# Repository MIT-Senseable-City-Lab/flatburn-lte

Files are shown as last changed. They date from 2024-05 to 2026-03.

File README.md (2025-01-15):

# FLATBURN: the open source city scanner

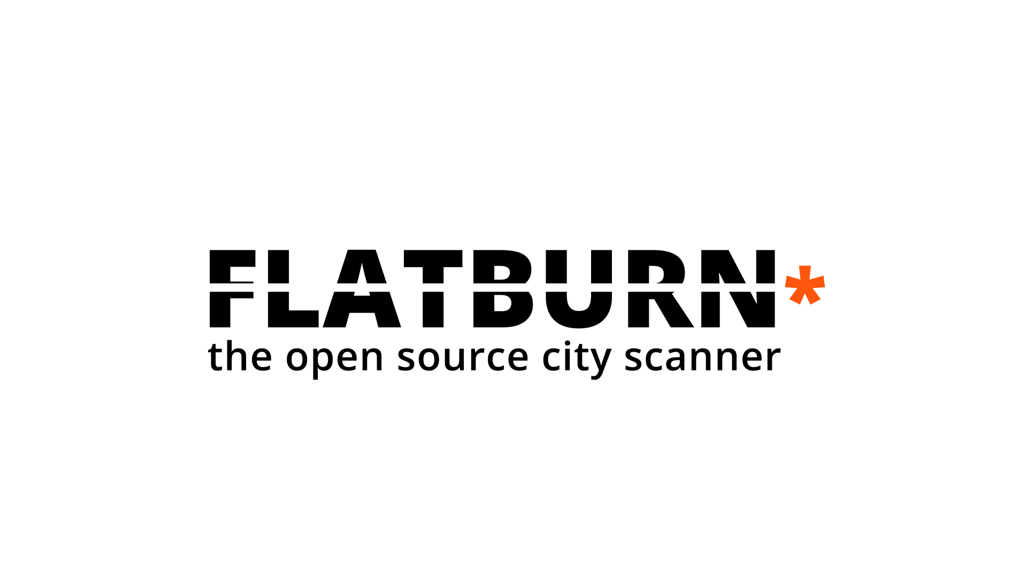
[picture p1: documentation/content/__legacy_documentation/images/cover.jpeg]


Part of the [City Scanner](https://senseable.mit.edu/cityscanner/) project at [MIT Senseable City Lab](https://senseable.mit.edu), Flatburn is an open-source, solar-powered, modular sensing platform that can be easily deployed on road vehicles to collect various environmental data. 

This repository contains all information to build your own Flatburn, explore datasets collected using Flatburn and other City Scanner deployments worldwide and learn how to perform environmental analysis and use the data to contribute to the development of healtier cities.

You can find all information on the [documentation](https://mit-senseable-city-lab.github.io/flatburn-lte/).

[Project website](https://senseable.mit.edu/flatburn).

All materials are released under [MIT license](LICENSE).

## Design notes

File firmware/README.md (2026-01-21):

# Flatburn-firmware

## Environment
- Code developed using [Particle.io plugin for MS Code](https://www.particle.io/workbench/)
- Devices can be flashed both via cable or cloud flash (data costs)
- Compatible with [Particle deviceOS@6.3.4](https://docs.particle.io/reference/device-os/firmware)
- Written in C++ and [Particle deviceOS APIs](https://docs.particle.io/reference/device-os/firmware/)

## Dev Environment Setup

1. Clone this repository
2. Open Particle Workbench
3. Run the `Particle: Import Project` command, follow the prompts, and wait for the project to load
4. Run the `Particle: Configure Workspace for Device` command and select a compatible Device OS version and the `bsom` platform when prompted ([docs](https://docs.particle.io/tutorials/developer-tools/workbench/#cloud-build-and-flash))
5. Connect your device
6. Compile & Flash!

## Quick overview of classes and files
- *cityscanner_config.h* main config file, needs to be updated before flashing
- *main.h* the program startpoint, should not be modified
- *cityscanner class* handles operation modes (more below)
- *CitySense class* manages data acquisition for environmental sensors (air quality, etc)
- *CityVitals class* acquires telemetry data (battery status, solar energy production, etc)
- *CityStore class* manages storing data on the SD card, dumping data over USB
- *MotionService class* used to send the device to sleep when the vehicle is not moving
- *LocationService class* provides GPS data to other classes (e.g. CityStore)

## Operation modes
- *IDLE* sensors off, provides only telemetry data
- *REALTIME* logs data onto the SD card
- *LOGGING* buffer data onto the SD card and send multiple records upon request (via USB)
- *PWRSAVE* like LOGGING but in low power mode

#### Payload

deviceID, timestamp, latitude, longitude, PM1.0, PM 2.5, PM4, PM10, numPM0.5, numPM1, numPM2.5, numPM4, numPM10, PM size, temperature, humidity, gas_op1_w, gas_op1_r, gas_op2_w, gas_op2_r, noise

### Vitals
deviceID, time, latitude, longitude, SOC_batt, temp_batt, voltage_batt, voltage_particle, current_batt, isCharging, isCharginS, temp_int, hum_int, voltage_solar, current_solar, cell_strenght

# Command line interface
A Python script provides a command line interface (CLI) for retrieving data over USB. To use it, follow the step-by-step instructions in the [data retrieval guide](https://mit-senseable-city-lab.github.io/flatburn-lte/deploy/data)

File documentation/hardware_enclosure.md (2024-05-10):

Files for 3D printing, laser-cutting and the full CAD assembly.

A BoM (bill of materials) listing all the required parts and components to build a Flatburn enclosure is available [here](https://docs.google.com/spreadsheets/d/1qiVyINNuo0XEu6MasEJE_p4onlJh241j/edit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).

**Process pictures showing the main assembly steps:**



Our prototypes were printed on a Flashforge Guider ii, but the files can be printed on most standard desktop 3D printers (e.g. Prusa i3, Ender 3, Ultimaker etc). 

We suggest the following settings:

* Infill type: Triangular or Esagonal 
* Infill Percentage: at leat 50% 
* Layer height: this depend on the printer nozzle, I would go with the pre-defined setting.

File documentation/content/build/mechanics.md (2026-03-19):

---
sidebar_position: 5
---

import Top from '@site/static/files/assembly/DSC09227.jpg'
import Middle from '@site/static/files/printed/middle.png'
import Bottom from '@site/static/files/assembly/DSC09240.jpg'
import BatteryCover from '@site/static/files/printed/battery_cover.png'
import SwitchTop from '@site/static/files/printed/switch_top.png'

# 🔩 Mechanics (files)

###

### Material and Suggested Settings

The easiest material to print with is _PLA_, but _ASA_ is recommended for prolonged outdoor use with high exposure to weather.

It is important to choose a **light material** (i.e. white) to avoid overheating when exposed to sun, which might interfere with measurements and overall electronics' life-cycle.

Since the device might also be exposed to moisture, vibration and stress – during trips and mounting/unmounting – it is recommended to print with settings that provide sturdyness and plenty layer and walls sealing:

- **_layer height_ – 0.28mm**
- **_top layers_ – 5**
- **_bottom layers_ – 5**
- **_walls_ – 5**
- **_infill_ – 15%**

These settings were used for time estimations below, with a total time of approximately **15 hours**.

### Parts List

:::tip
The 3d files below are provided with optimal orientation for printing, which is different from their respective reference images.
:::
| ID | name | support | weight | ~time | download |
| :--- | :--- | :-----: | -----: | :---: | :---: |
| MP_01 | **top** | N |  350 g | 07:30 | [link](https://github.com/MIT-Senseable-City-Lab/flatburn-lte/blob/main/hardware/enclosure/stl/MP-01%20top.stl) |
| MP_02 | **middle** | Y |  150 g | 03:30 | [link](https://github.com/MIT-Senseable-City-Lab/flatburn-lte/blob/main/hardware/enclosure/stl/MP-02%20middle.stl) |
| MP_03 | **bottom** | N |  150 g | 03:30 | [link](https://github.com/MIT-Senseable-City-Lab/flatburn-lte/blob/main/hardware/enclosure/stl/MP-03%20bottom.stl) |
| MP_04 | **switch_top** | N | 5 g | 00:10 | [link](https://github.com/MIT-Senseable-City-Lab/flatburn-lte/blob/main/hardware/enclosure/stl/MP-04%20switch_top.stl) |
| MP_05_02 | **switch_bottom** | N | 5 g | 00:10 | [link](https://github.com/MIT-Senseable-City-Lab/flatburn-lte/blob/main/hardware/enclosure/stl/switch%20radial%20-%20R10307RN02Q/MP-05%20switch_bottom.stl) |
| MP_06 | **battery_cover** | Y | 15 g | 00:30 | [link](https://github.com/MIT-Senseable-City-Lab/flatburn-lte/blob/main/hardware/enclosure/stl/MP-06%20battery_cover.stl) |

The sources are available [here](https://github.com/MIT-Senseable-City-Lab/flatburn-lte/tree/main/hardware/enclosure/step) in *.STEP* format.

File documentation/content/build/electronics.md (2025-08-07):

---
sidebar_position: 4
---

# ⚡ Electronics (files)

### Main and Sensing Board

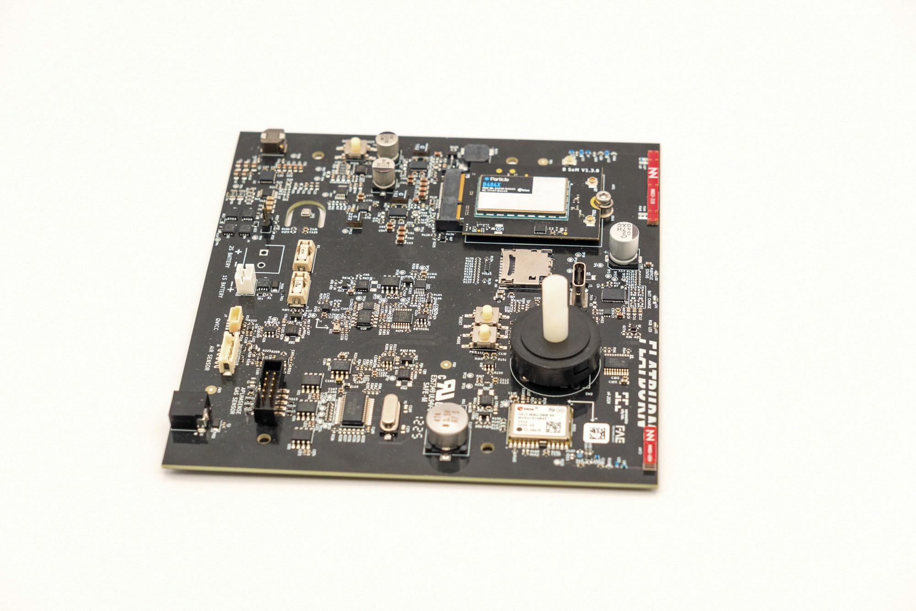
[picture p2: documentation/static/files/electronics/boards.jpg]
Main and Sensing Board


<!-- ### Harnesses

![Harnesses](@site/static/files/electronics/harnesses.jpg) --> 

### Files

- [schematics](https://github.com/MIT-Senseable-City-Lab/flatburn-lte/blob/main/hardware/electronics/Doc/Flatburn_V5_schematic.pdf) (2025-07-29)

- [KiCad files](https://github.com/MIT-Senseable-City-Lab/flatburn-lte/tree/main/hardware/electronics) with embedded component libraries

- [gerbers and centroid files](https://github.com/MIT-Senseable-City-Lab/flatburn-lte/tree/main/hardware/Production/Gerber%20and%20drill)

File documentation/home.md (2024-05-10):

# FLATBURN: the open source city scanner

[Project website](https://senseable.mit.edu/flatburn).

### Flatburn Overview
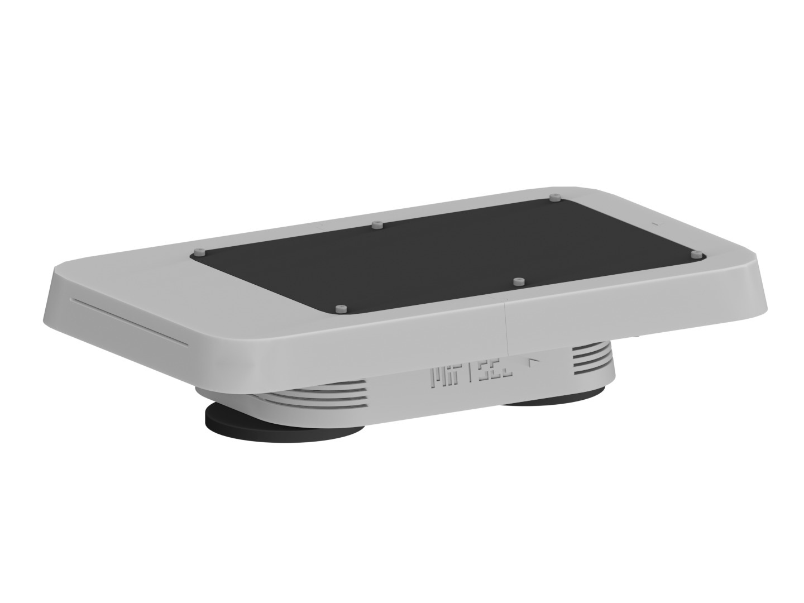
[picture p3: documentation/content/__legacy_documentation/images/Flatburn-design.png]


Part of the [City Scanner](https://senseable.mit.edu/cityscanner/) project at [MIT Senseable City Lab](https://senseable.mit.edu), Flatburn is an open-source, solar-powered, modular sensing platform that can be easily deployed on road vehicles to collect various environmental data. 

This repository contains all information to [build](https://github.com/MIT-Senseable-City-Lab/OSCS/tree/main/Build) your own Flatburn, [explore](https://github.com/MIT-Senseable-City-Lab/OSCS/tree/main/Explore) datasets collected using Flatburn and other City Scanner deployments worldwide and [learn](https://github.com/MIT-Senseable-City-Lab/OSCS/tree/main/Learn) how to perform environmental analysis and use the data to contribute to the development of healtier cities.

## Build
 - [/hardware](Build/Hardware)  
    - [fabrication files](Build/Hardware/Hardware%20enclosure) for Flatburn mechanical parts, including files for [3D printing](Build/Hardware/Hardware%20enclosure/To%20Print), [laser cutting](Build/Hardware/Hardware%20enclosure/To%20lasercut), and a [CAD model](Build/Hardware/Hardware%20enclosure/Flatburn_assembly.step) of the full assembly. A [bill of materials](https://docs.google.com/spreadsheets/d/1qiVyINNuo0XEu6MasEJE_p4onlJh241j/edit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) listing all the required mechanical components is also included.
    - [hardware schematics](Build/Hardware/Hardware%20schematics) contains `.brb` files for the main-board and the sensor-board which can be viewed using the [Cadence](https://www.cadence.com/en_US/home/tools/pcb-design-and-analysis/allegro-downloads-start.html) free viewer, schematics of the PCB in `.pdf` format, and a [bill of materials](https://docs.google.com/spreadsheets/d/1-UVIJEneydIf8kLRng4QxvzjM4k2ZoDa/edit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) for the electronics components.
 - [/firmware](Build/Firmware): The Flatburn main firmware code base, developed using [Particle.io](https://www.particle.io/workbench/) workbench.
 - [/fabrication handbook](Build/Handbook): The assembly guide with detailed instructions on how to build flatburn.

## Explore
- [/datasets](Explore/Datasets): `.csv` calibrated air quality datasets collected during City Scanner deployments worldwide. 
- [/calibration handbook](Explore/Calibration%20Handbook): a guide for validation and calibration of the data collected by Flatburn.

## Learn
- [/coding exercise](Learn/Coding%20Exercise): [jupyter](https://jupyter.org/) notebooks for a Python coding activity to introduce non-experts to air quality and environmental sensing and analysis methods. The activity includes exploring time series analysis, geospatial analysis, and pollution hotspot analysis. The conding activity can be used with the [datasets](Explore/Datasets) captured by previous City Scanner deployment as well as data captured by Flatburn.
- [/facilitator handbook](Learn/Facilitator%20Handbook): a facilitator guide and educational slides to implement the coding exercise as part of workshops or classroom activities.

All materials are released under [MIT license](LICENSE).

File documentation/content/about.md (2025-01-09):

---
sidebar_position: 1
slug: /
---

# Flatburn

_We empower communities around the world to monitor their environment._

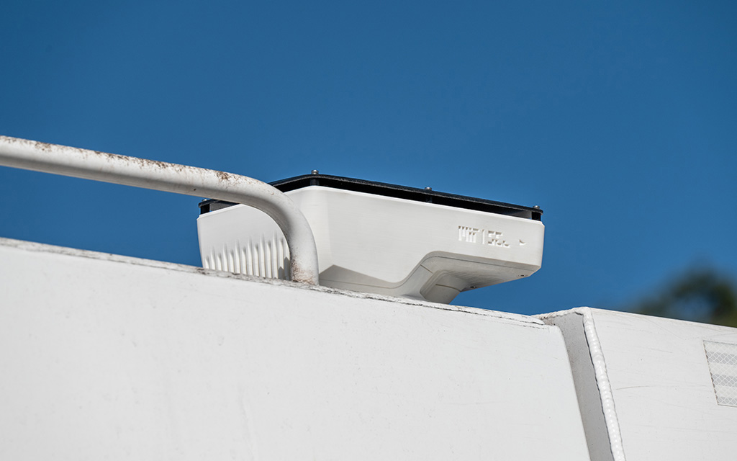
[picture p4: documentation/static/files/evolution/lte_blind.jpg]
Flatburn


Part of the City Scanner project, Flatburn is an open-source, 3D-printed environmental sensor.

Its encompasses houses heat, noise and air quality sensors. Powered using a solar panel, it can be mounted on vehicles using magnetic pads.

Build your own Flatburn and help your community monitor its environment.

<!-- vision: how the project is connected to SCL's vision

approach: drive-by low-cost sensing, high spatio-temporal resolution -->

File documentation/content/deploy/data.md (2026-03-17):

---
sidebar_position: 4
---

# 📊 Data Retrieval via USB Cable

**Follow these steps to retrieve data from the Flatburn device using the web-based downloader tool.**

The Flatburn SD Downloader is a browser-based tool that connects to your device over USB. It works in **Google Chrome** or **Microsoft Edge** (requires Web Serial API support).

The HTML tool is available [here](https://github.com/MIT-Senseable-City-Lab/flatburn-lte/blob/main/documentation/content/explore/flatburn_downloader.html). Download it and open it in Chrome or Edge.

## Step 1: Connect Flatburn to Your Computer

1. Turn on your Flatburn device.
2. Use a USB cable to connect the device to your computer.
3. Open `flatburn_downloader.html` in **Google Chrome** or **Microsoft Edge**.

## Step 2: Connect to the Serial Port

1. Click the **Connect** button.
2. A browser dialog will show available serial ports.
3. Select the Flatburn port; it will be labeled **"B-SoM CDC Mode"**.
4. The status indicator will turn green once connected, and the file list will load automatically.

**Note** After connecting, the tool waits about 1 minute for the device to finish initializing before loading the file list. This is normal, just wait for the file list to appear.

## Step 3: Download, Parse & Merge

The tool will display all available files on the SD card (e.g., files in `/queue/` and `active.csv`).

1. Review the file list.
2. Click **"Download All, Parse & Merge"**.
3. The tool will:
   - Download all files from the SD card
   - Parse each CSV (filter columns, clean data)
   - Convert epoch timestamps to human-readable format (e.g., `2025-03-15 22:37:17`)
   - Merge everything into a single dataset

A progress bar will show the download status, and stats badges will display the total files processed and rows merged.

## Step 4: Save the Merged CSV

1. Click **"Save CSV File"** to download the merged data to your computer.
2. The file is automatically named with a timestamp: `merged_20250315_223717.csv`

The output CSV contains the following columns:

| Column | Description |
|---|---|
| `timestamp` | Date and time of the reading (human-readable) |
| `latitude` | GPS latitude |
| `longitude` | GPS longitude |
| `PM1_0` | Particulate matter 1.0 µm |
| `PM2_5` | Particulate matter 2.5 µm |
| `PM4` | Particulate matter 4.0 µm |
| `PM10` | Particulate matter 10 µm |
| `temperature` | Temperature reading |
| `humidity` | Humidity reading |
| `gas_op1_w` | Gas sensor OP1 working electrode |
| `gas_op1_r` | Gas sensor OP1 reference electrode |
| `gas_op2_w` | Gas sensor OP2 working electrode |
| `gas_op2_r` | Gas sensor OP2 reference electrode |
| `noise` | Noise level reading |

## Step 5: Clean Up the SD Card (Optional)

After saving your merged CSV, you can delete all files from the SD card to free up space:

1. Click **"Delete All Files from SD"**.
2. A confirmation dialog will list all files that will be deleted.
3. Click **OK** to confirm, or **Cancel** to keep the files.

The device will automatically create a fresh `active.csv` file after deletion, so it is ready to continue collecting data.

## Step 6: You're Done!

You now have a single, clean CSV file containing all your environmental and telemetry data with human-readable timestamps. You can use this file for analysis, upload to cloud storage, or integrate into your research workflow.

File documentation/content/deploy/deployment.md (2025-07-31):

---
sidebar_position: 3
---

# 🚚 Deployment
# Flatburn Solar Feasibility & Runtime Estimation

This file estimates whether Flatburn will run continuously on solar power in Brazil, using all the  hardware and sensor configurations.

---

## 1. Instructions

Get your average daily sun hours for your city/month using:
   - [Global Solar Atlas](https://globalsolaratlas.info/)
   - [PVWatts Calculator](https://pvwatts.nrel.gov/)
   - Example: **Rio de Janeiro** in July ≈ 5.5 h/day

---

## 2. Flatburn Power Consumption Estimate

- **Total current:** 211 mA  
- **Total power:** 0.85 W
- **Device daily consumption:** 0.85 W × 24 h = **20.4 Wh/day**

---

## 3. Solar Panel and Battery Specs

| Parameter | Value | Units | Notes |
|---|---|---|---|
| Solar panel power | 5.5 | W | |
| Solar panel voltage | 6 | V | |
| Average daily sun hours  | 5.5 | hours/day  | Brazil average (Rio, July) |
| Solar energy per day | 5.5 × 5.5 = 30.25  | Wh/day | Panel power × sun hours |
| Battery capacity | 10050 × 3.7 / 1000 = 37.19 | Wh | 10050 mAh, 3.7 V Li-Ion |
| Days battery lasts w/o sun | 37.19 / 20.4 = 1.8 | days | Battery Wh / daily use |

---

## 4. Results

- **Solar panel provides:** ~30 Wh/day
- **Flatburn requires:** ~20.4 Wh/day
- **Battery stores:** ~37 Wh

- Daily solar energy is enough for continuous operation with some surplus for battery charging.
- Battery can run Flatburn for **1.8 days** without sun (cloudy/rainy buffer).

---

## 5. Tips

- For worst-case (cloudy, winter), use the lowest sun hours for your city/month.

---

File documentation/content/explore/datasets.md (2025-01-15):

---
sidebar_position: 6
---

# 🗂️ Datasets (files)

[This folder](https://github.com/MIT-Senseable-City-Lab/flatburn-lte/tree/main/documentation/content/_files/datasets) contains open City Scanner data sets collected in four deployments in three cities. Raw sensor readings were collected and calibrated following standardized air sensor performance evaluation guidelines recommended by the U.S. EPA. The general method is presented in the following diagram and details can be found in the open source [calibration page](../deploy/calibration.md).

Detailed information about the deployments and data files is included in he following table. In total, there are eight data files. Given that the second pilot in NYC contains a huge amount of data, its full dataset is divided into five sections. A [data descriptor](https://github.com/MIT-Senseable-City-Lab/OSCS/blob/main/Explore/Datasets/OSCS_OpenDataSupplement.pdf) is also included.

_Table 1. Deployments and open data sets_

| Country | City | Sensing target pollutants | Sensing fleet | Duration |
| :--- | :--- | :--- | :--- | :--- |
| US | New York City | Particulate matter, particle size distribution, NO2 | Five municipal vehicles | Jan. 2020 - Feb. 2020 |
| US | New York City | Particulate matter, particle size distribution, NO2 | Five municipal vehicles | Sep. 2021 - Dec. 2021 |
| US | Boston | Particulate matter, particle size distribution, NO2 | One mobile air laboratory | Feb. 2022 - Apr. 2022 |
| Lebanon | Beirut | Particulate matter, particle size distribution | Two taxis | Feb. 2022 - Jun. 2022 |

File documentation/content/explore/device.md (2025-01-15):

---
sidebar_position: 2
---

# 🧭 Device

The Flatburn device is based on almost a decade of experience in drive-by sensing, which resulted in a sturdy and compact device that can be deployed on vehicles of different sizes. See below all its features in depth.

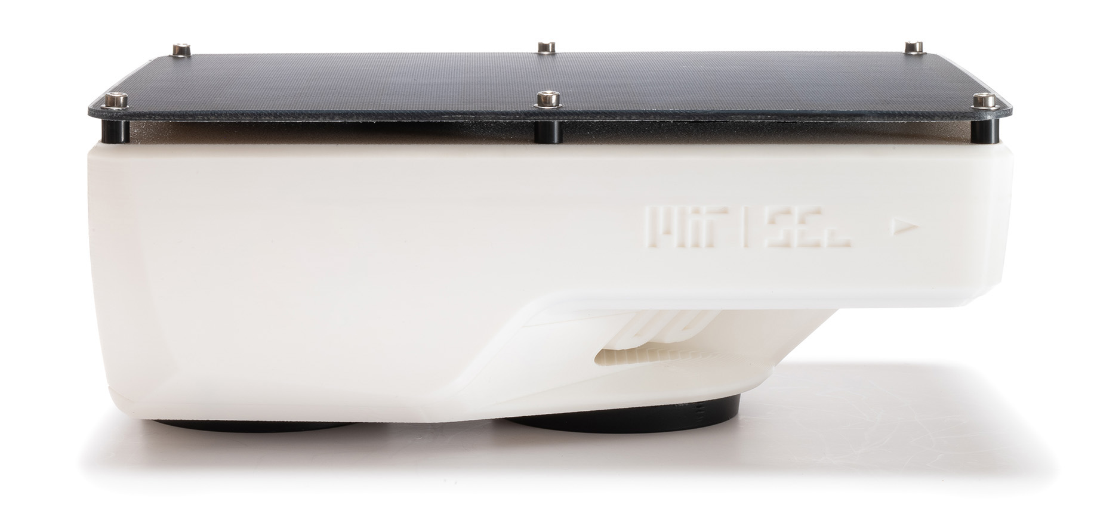
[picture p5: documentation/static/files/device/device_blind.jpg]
Device


## Sensing

<div style={{textAlign: 'center'}}>

```mermaid
mindmap
    root((**SENSING**))
        Temperature
        Humidity
        Particulate Matter
            PM1.0
            PM2.5
            PM4
            PM10
        Gases
            CO
            NO2
            O3
            & more
        Noise
        Road Quality
        Position
```

</div>

### 💨 Gases

<div style={{display: "flex", justifyContent:"space-between"}}>
    <div style={{width: "49%"}}>
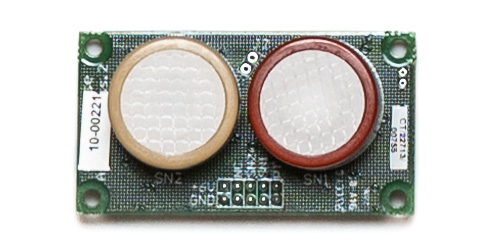
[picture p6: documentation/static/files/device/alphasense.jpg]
        
    </div>
    <div style={{width: "49%"}}>
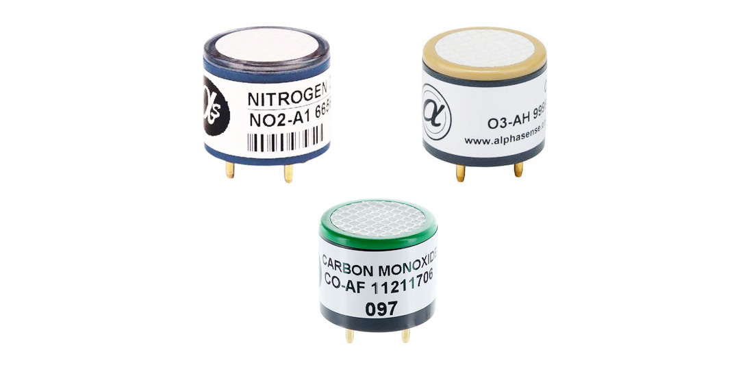
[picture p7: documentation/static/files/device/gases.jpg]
        
    </div>
</div>

_Sensor: Alphasense._

By using Alphasense platform for sensing gases, it is possible to mount up to two different sensors using the same base configuration, such as CO, NO2 or O3.

### ☁️ Particulate Matter

<!-- ![Particulate Matter](@site/static/files/device/particulate.svg) -->
<div style={{width: "49%"}}>
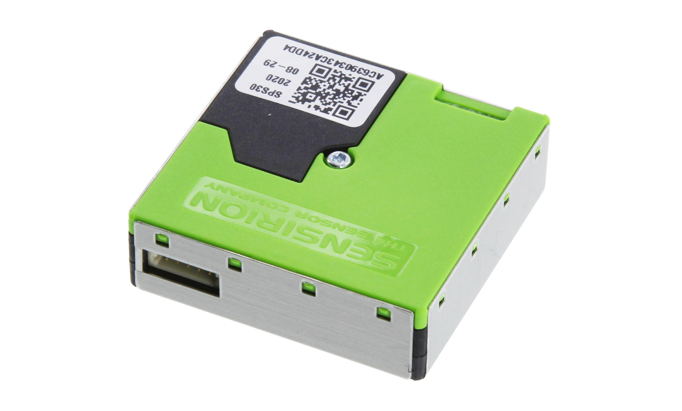
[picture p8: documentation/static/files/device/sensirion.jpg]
    
</div>
_Sensor: Sensirion SPS30._

City Scanner counts particles in different diameter size bins (PM1.0, PM2.5, PM4 and PM10) using a small laser.

The particle counts are an indicator to determine signatures of different pollution sources. This data can inform epidemiological research and urban health policies.

### 🌡️ Temperature & 💧 Humidity

<!-- ![Temperature & Humidity](@site/static/files/device/temperature.svg) -->

<div style={{display: "flex", justifyContent:"space-between"}}>
    <div style={{width: "49%"}}>
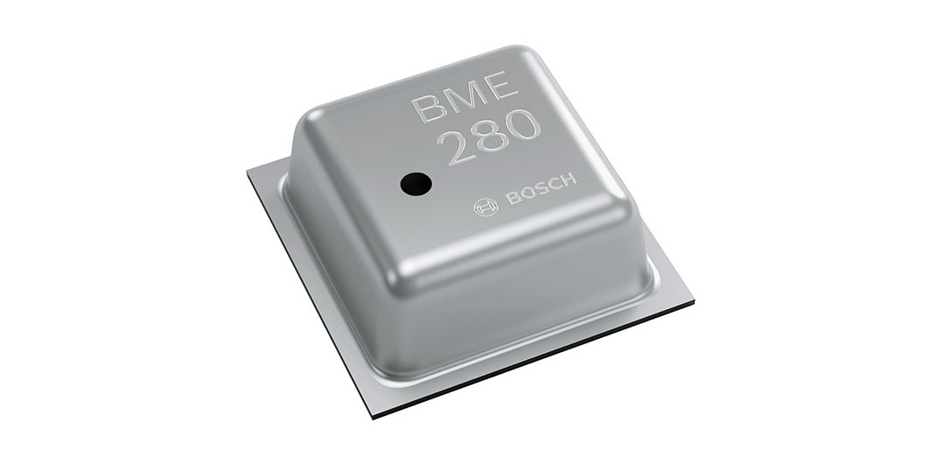
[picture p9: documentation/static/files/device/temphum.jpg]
        
    </div>
</div>

_Sensor: Bosch BME280_

City Scanner includes low-cost temperature and humidity sensors that can be used to understand pedestrian activities as well as heat islands in urban areas.

### 🎤 Noise Levels

<div style={{display: "flex", justifyContent:"space-between"}}>
    <div style={{width: "49%"}}>
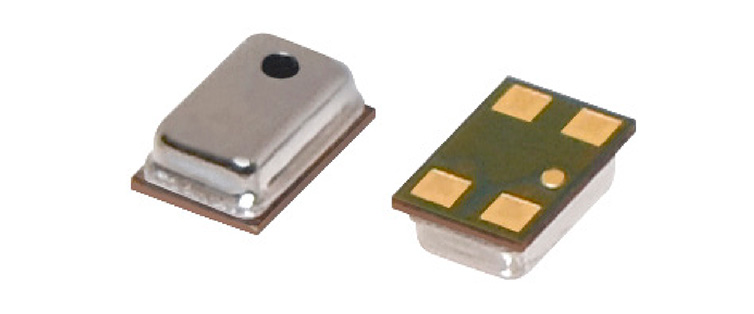
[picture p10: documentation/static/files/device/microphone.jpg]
        
    </div>
</div>

_Sensor: CUI DEVICES CMM-2718AT-42316-TR MEMS Microphone_

The device carries an internal microphone able to capture noise from surroundings.

### 🛰️ Position & 🚎 Road Quality

<!-- ![Road Quality](@site/static/files/device/road.svg) -->

<div style={{display: "flex", justifyContent:"space-between"}}>
    <div style={{width: "49%"}}>
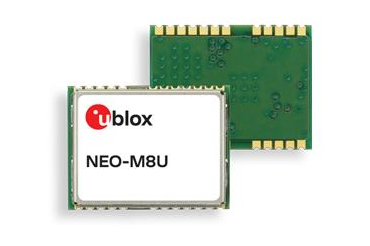
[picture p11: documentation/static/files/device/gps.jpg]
        
    </div>
</div>

_Sensor: u-blox NEO-M8U-06B_

The GPS sensor provides location, and also accelerometer data to identify road quality based on the vehicle vibrations.

City Scanner literally creates a roadmap for improving roads.

## Power

### ☀️ Solar Energy

Whenever the sun is shining the device is able to charge its battery while operating.

### 🔋 Battery

If either the day is cloudy, or it is in a shade, the device is able to run for _⚠️ N hours_ without needing to charge on an outlet.

## Connectivity

### 🌎 Particle GSM

<div style={{display: "flex", justifyContent:"space-between"}}>
    <div style={{width: "49%"}}>
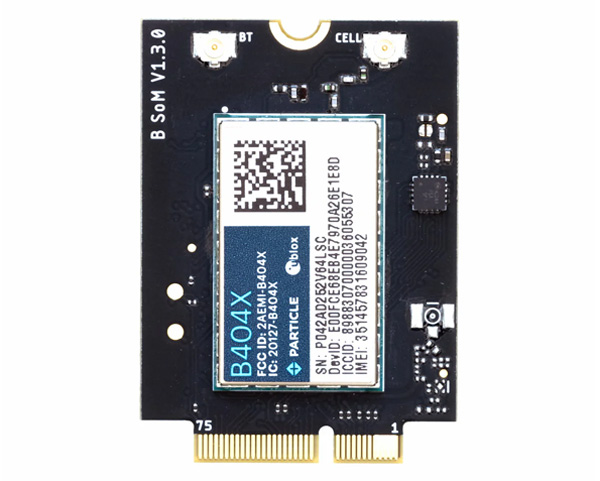
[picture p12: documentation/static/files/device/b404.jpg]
        
    </div>
    <div style={{width: "49%"}}>
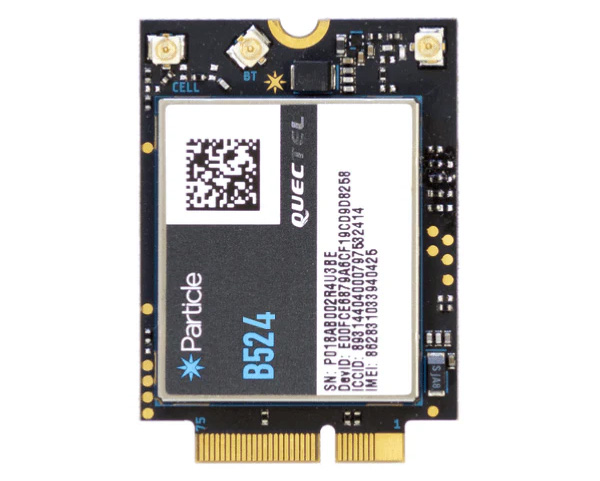
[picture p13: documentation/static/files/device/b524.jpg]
        
    </div>
</div>

By using a [Particle](https://www.particle.io/) module, the device automatically gathers data and send it to the cloud, and might have its firmware updated remotely as well.

It is possible to select between US (B404) and EU (B524), depending on where the device will be deployed.

<div style={{textAlign: "center"}}>
 ```mermaid
graph BT;

    A[/Sensing\] --> D1
    B[/Sensing\] --> D2
    C[/Sensing\] --> D3
    D[/Sensing\] --> D4

    D1(<b>Device #01</b>) -.-> |GSM| E
    D2(<b>Device #02</b>)  -.-> |GSM| E
    D3(<b>Device #03</b>)  -.-> |GSM| E
    D4(<b>Device #...</b>)  -.-> |GSM| E{Back-end}

    E ==> F[(Database)]

```
</div>

## Weather Resilience

### ☔️ Sensing Chamber

Inspired by the nasal cavity. Just like our brains, all sensitive electronics are positioned in a monolithic enclosure and above the air intake, avoiding the water entrance.

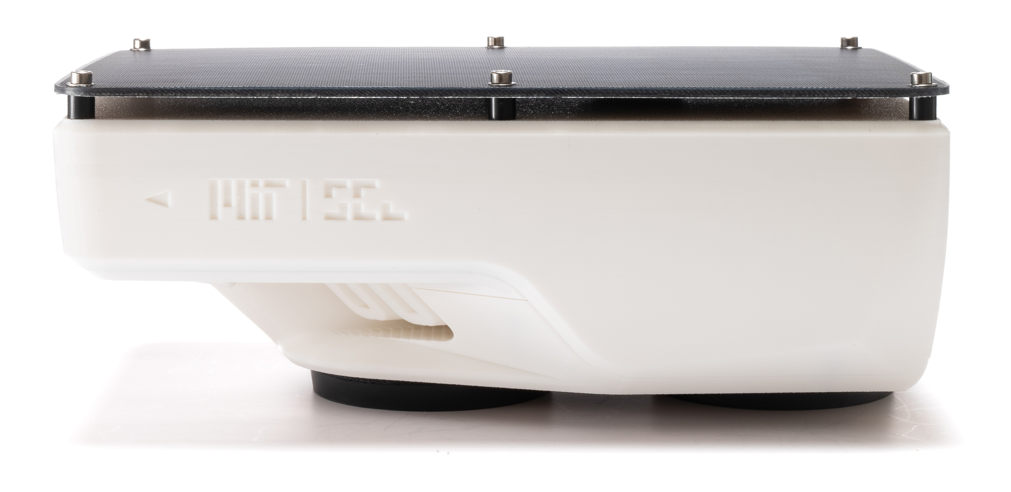
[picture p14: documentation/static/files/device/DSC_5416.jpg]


The sensors that need to be in contact with the exterior are protected by grilled nostrils that slows the airspeed to avoid misreadings and allows for fast sensor response times. Any eventual accumulated moisture is easily drained through internal slopes.
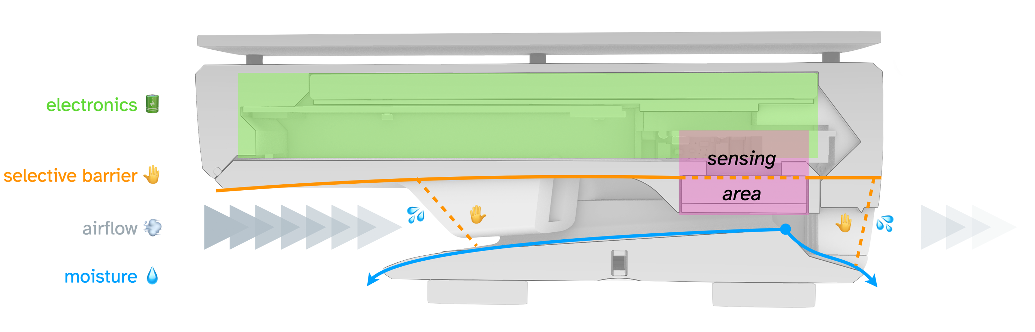
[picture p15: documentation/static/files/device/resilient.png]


### 🤿 Sealed I/Os

Both the **on–off switch** and the **USB-C port** are sealed for protection while keeping their core functionalities.
<div style={{display: "flex", justifyContent:"space-between"}}>
    <span style={{width: "49%"}}>
        
    </span>
    <span style={{width: "49%"}}>
        
    </span>
</div>

The USB-C can be used to charge the device, flash firmware, debug and retrieve data.
<div style={{display: "flex", justifyContent:"space-between"}}>
    <span style={{width: "32%"}}>
        
    </span>
    <span style={{width: "32%"}}>
        
    </span>
    <span style={{width: "32%"}}>
        
    </span>
</div>

## Practicity

### 🧲 Magnetic Mount

The two magnets on the bottom make it easy to **attach the device to any ferromagnetic material**, such as most of automobile roofs.
<div style={{display: "flex", justifyContent:"space-between"}}>
    <div style={{width: "49%"}}>
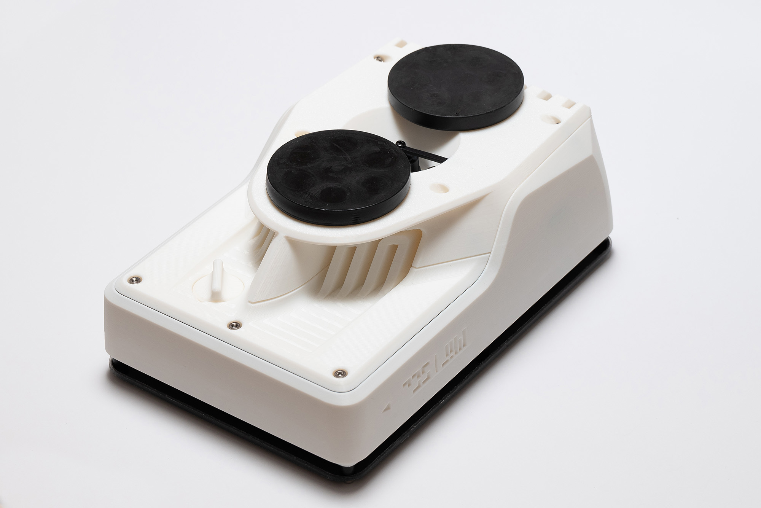
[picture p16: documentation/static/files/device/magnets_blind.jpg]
        
    </div>
    <div style={{width: "49%"}}>
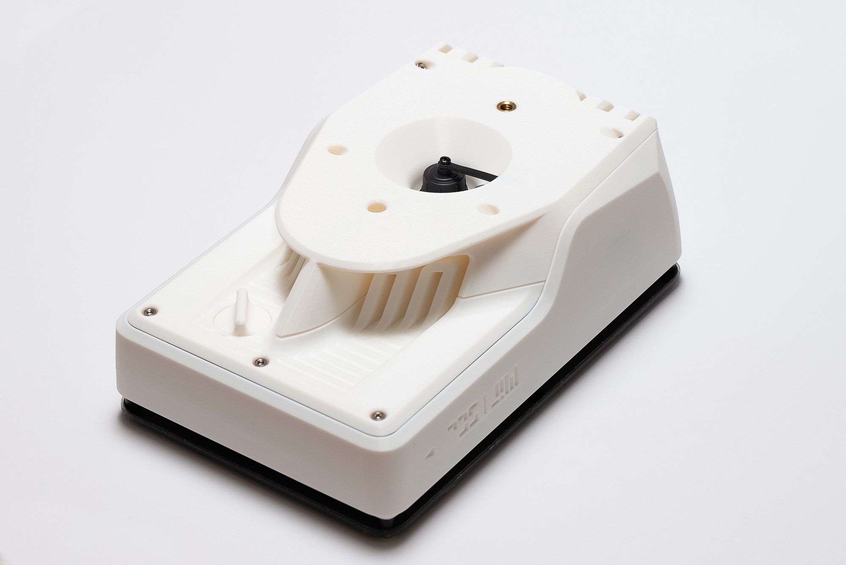
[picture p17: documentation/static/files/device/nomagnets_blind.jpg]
        
    </div>
</div>
Alternatively, the magnets can be removed, leaving the rear standard camera 1/4" thread to **mount the device with other accessories.**

### 💼 Light and Compact

Each unit weighs 1.5kg, and at least 5 devices can be fitted inside a small carry-on bag.

<div style={{display: "flex", justifyContent:"space-between"}}>
    <div style={{width: "48%"}}>
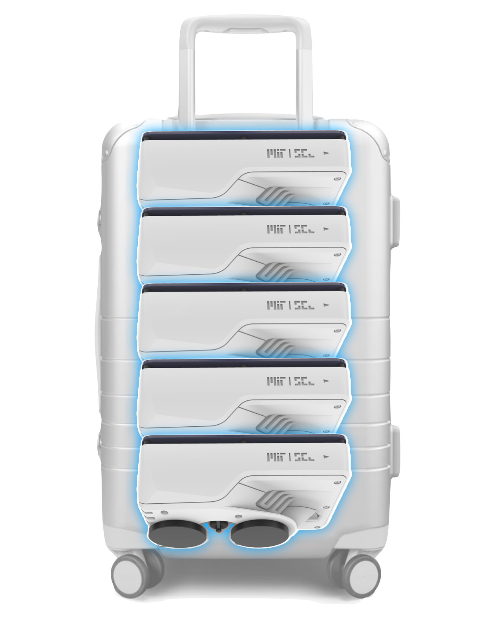
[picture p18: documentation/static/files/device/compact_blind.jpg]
        
    </div>
</div>

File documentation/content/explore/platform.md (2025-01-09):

---
sidebar_position: 1
---

# 🏗️ Platform

<!-- Explain how all different researches and devices are structured under the long-term City Scanner project. -->

The City Scanner platform proposes a drive-by solution to capture the spatiotemporal variation in environmental indicators in urban areas, such as air quality. Instead of relying on a dedicated fleet, the project began by deploying various types of environmental sensors on garbage trucks in the City of Cambridge.

With a few garbage trucks, we collected various environmental data for the whole city over several months. The result was 1.6 million data points including temperature, humidity, and air quality data.

The spatio­temporal datasets play a significant role in smart city domain by empowering advanced analytics solutions for decision makers and urban managers. The City Scanner project follows a centralized IoT regime to generate a near real-time map of sensed data, building on existing fleets and moving sensing platforms.

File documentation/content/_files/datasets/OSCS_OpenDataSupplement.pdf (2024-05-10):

## City Scanner Open Data Supplement

This document provides expanded definitions, units, and more information on the data provided in the .CSV files from City Scanner deployments.

### Data Fields

time

- The time field is in Unix time and can be converted to local time with a simple script or using online tools.

latitude, longitude

- The latitude and longitude readings from the devices are determined via GPS and given in degrees for projected corrdinates.

pm1, pm25, pm10

- The particulate matter (pm) readings from the optical particle counter after calibration.
- The units for each are instantaneous mass concentrations in µg/m³

no2

- The nitrogen dioxide (no2) readings from the gas sensors after conversion and calibration.
- The unit is instantaneous concentrations in parts per billion (ppb).

bin0-bin23

- Twenty-four bins from the OPC containing particle number counts for different sizes, ranging from 0.35 to 40 µm. The bin boundary sizes are as follows from bin0 to bin23:
- 0.35
- 0.46
- 0.66
- 1.0
- 1.3
- 1.7
- 2.3
- 3.0
- 4.0
- 5.2
- 6.5

- 8.0
- 10.0
- 12.0
- 14.0
- 16.0
- 18.0
- 20.0
- 22.0
- 25.0
- 28.0
- 31.0
- 34.0
- 37.0
- 40.0

temperature

- Ambient temperature reading in degrees Celsius.

humidity

- Ambient relative humidity reading in percentage

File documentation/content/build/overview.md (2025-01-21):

---
sidebar_position: 1
---

# 🏔️ Overview

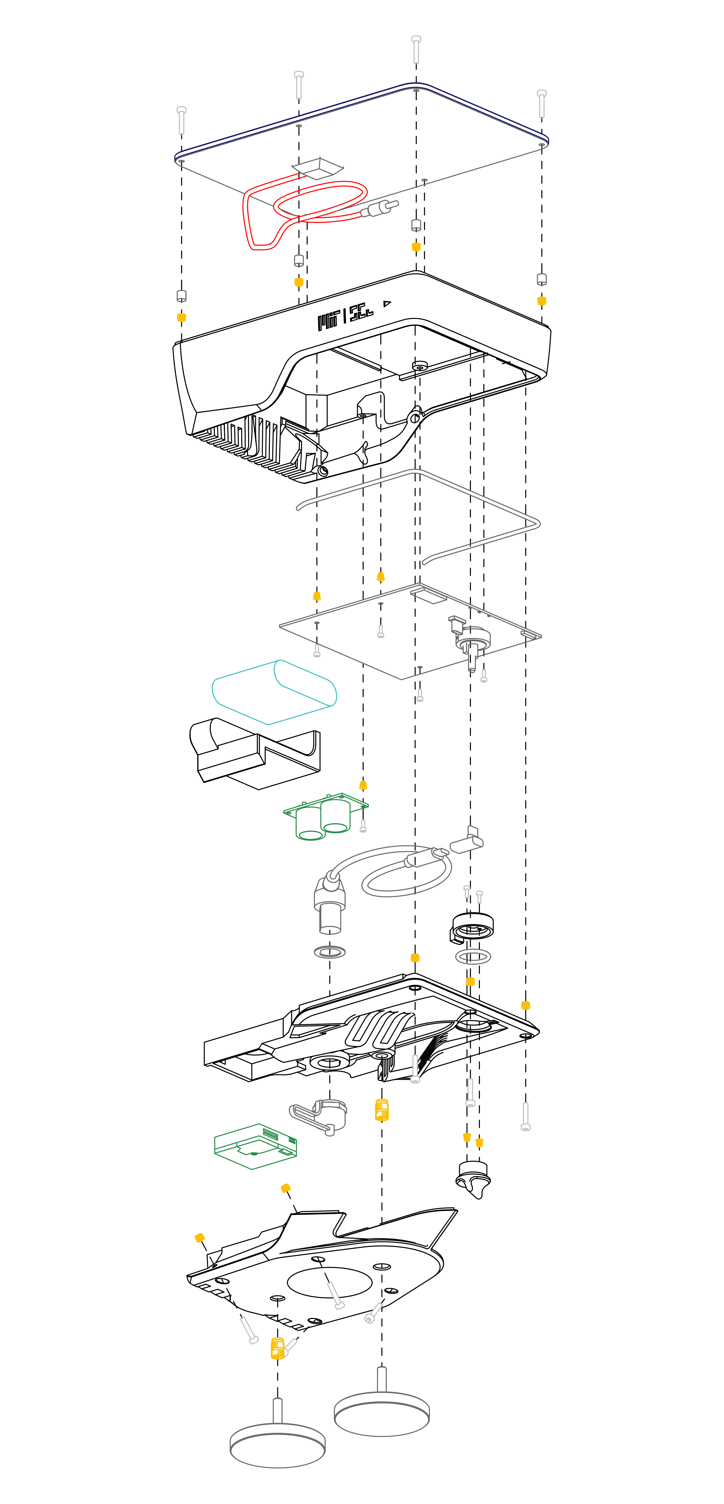
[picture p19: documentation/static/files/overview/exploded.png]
Flatburn


Click [here](https://github.com/MIT-Senseable-City-Lab/flatburn-lte/blob/main/documentation/content/_files/overview/exploded_view.pdf) for PDF File.

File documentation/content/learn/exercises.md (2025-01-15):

---
sidebar_position: 2
---

# 💻 Coding Exercise (files)

[This folder](https://github.com/MIT-Senseable-City-Lab/flatburn-lte/tree/main/documentation/content/_files/coding_exercise) contains a coding activity written in Python to introduce users to air quality and environmental sensing methods by working with CityScanner Data, exploring time series analysis, geospatial analysis, and pollution hotspot analysis.

There are 2 versions:

- One is a `.ipynb` file containing python code and some descriptive text, which can be run in an environment of your choosing.
- The other is a `.ipynb` file intended to be run on the [Google CoLab](https://colab.research.google.com/) platform.

The notebooks provide sample code to run with *New York City Deployment* data, which can be edited to use different data files we provide in [explore/datasets](/Explore/Datasets).

Please refer to the [Facilitator Handbook](facilitator/handbook_overview) for further instructions.

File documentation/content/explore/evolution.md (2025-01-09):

---
sidebar_position: 4
---

# ♾️ Evolution

What we discover when we turn urban vehicles into sensing platforms.

```mermaid

timeline
    2017  <br> Greta I
    2018  <br> Greta II
    2019  <br> Blackburn
    2022  <br> Whiteburn
    2023  <br> Flatburn
    2024  <br> Flatburn

```

### 2024 Flatburn

_Stockolm (2024), Bologna (2024)_

Flatburn

### 2023 Flatburn

_Beirut (2023), Amsterdam (2023)_

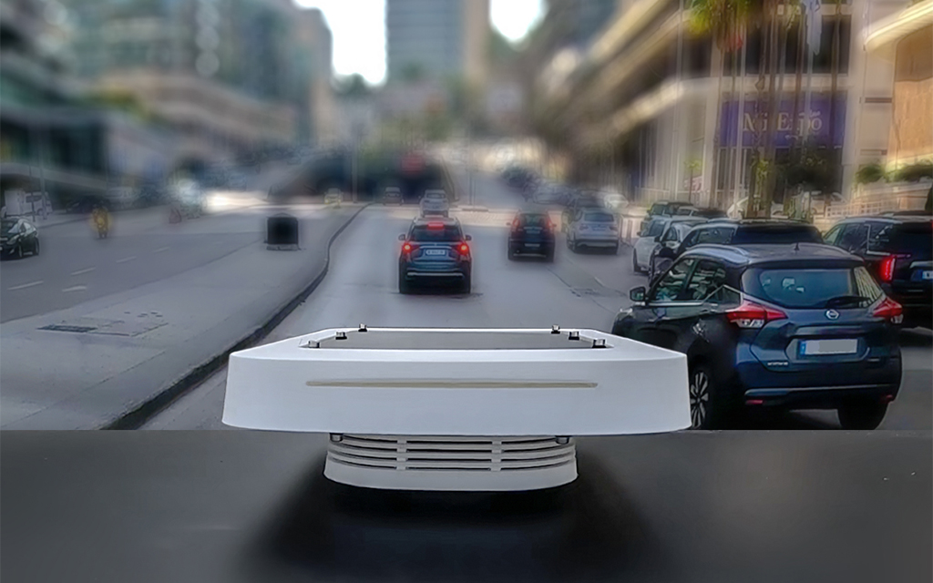
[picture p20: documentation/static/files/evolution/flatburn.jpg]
Flatburn


### 2022 Whiteburn

_Boston (2019), New York (2020), Stockholm (2021), Oskemen (2021), Beirut (2022)_

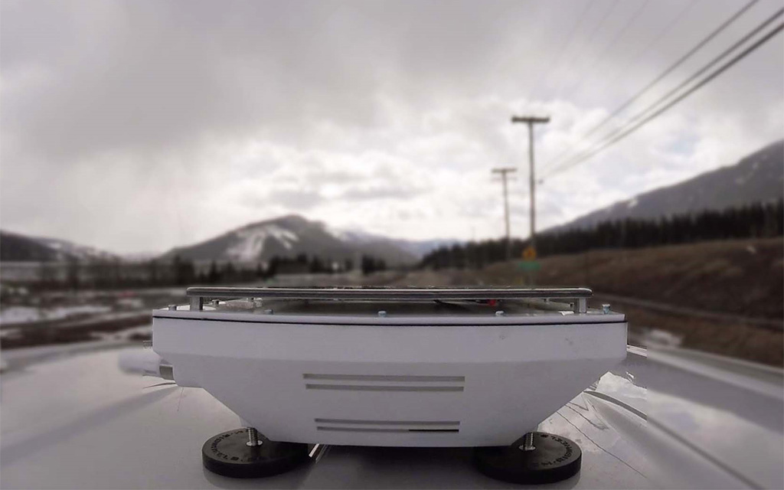
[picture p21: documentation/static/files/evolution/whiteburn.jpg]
Whiteburn


### 2019 Blackburn

_Boston (2019)_

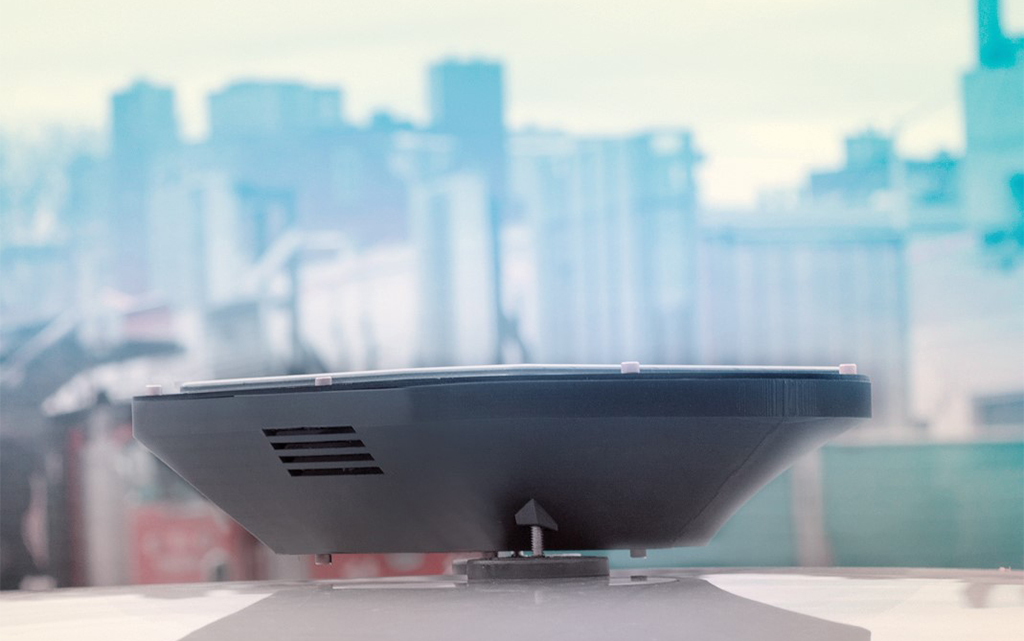
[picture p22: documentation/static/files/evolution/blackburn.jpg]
Blackburn


### 2018 Greta II

_Boston (2018), New York (2018)_

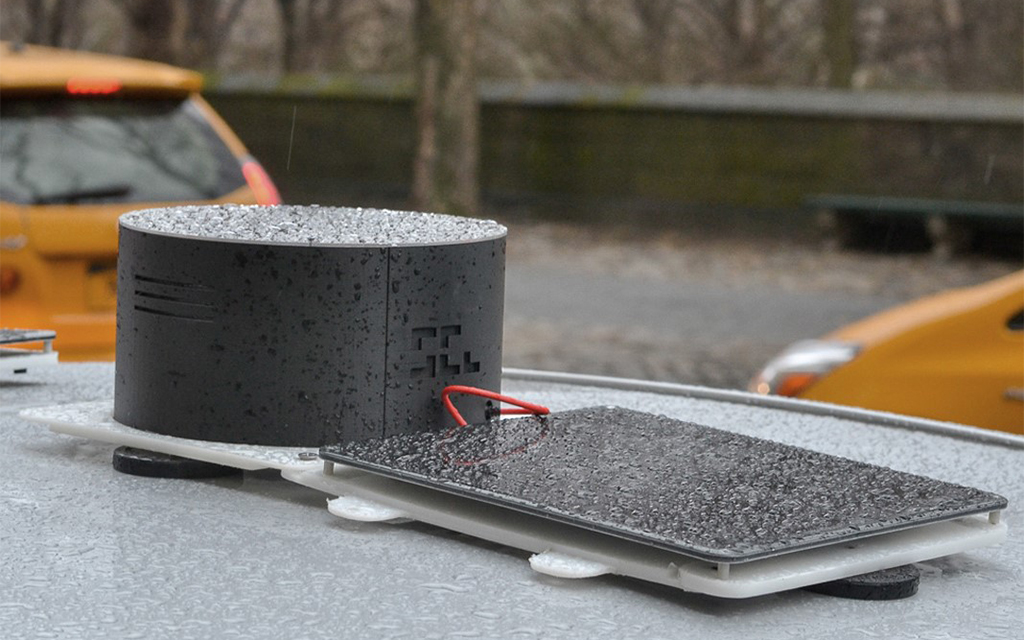
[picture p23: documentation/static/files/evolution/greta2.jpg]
Greta II


### 2017 Greta I

_Boston (2017)_

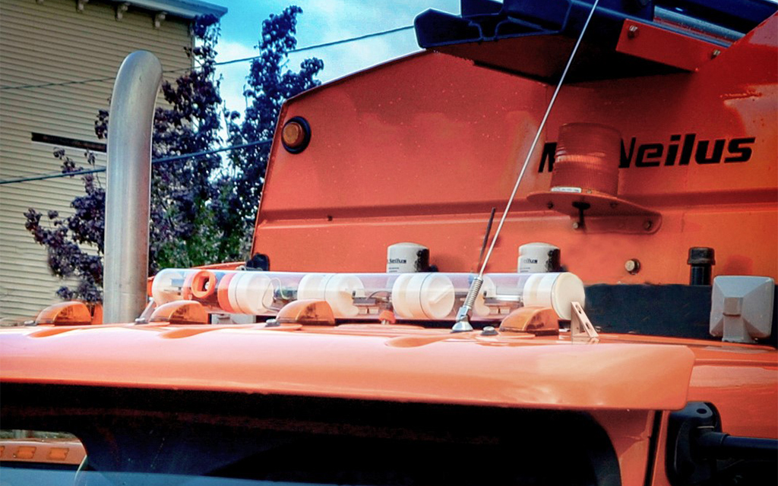
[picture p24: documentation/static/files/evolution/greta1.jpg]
Greta I


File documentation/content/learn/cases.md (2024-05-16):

---
sidebar_position: 1
---

# 💡 Use Cases

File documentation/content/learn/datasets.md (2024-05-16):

---
sidebar_position: 2
---

# 🗂️ Datasets

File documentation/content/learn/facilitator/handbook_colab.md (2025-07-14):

---
title: 🤸 Colab
sidebar_position: 3
---

import Image1 from '@site/static/files/facilitator/image1.png';
import Image2 from '@site/static/files/facilitator/image2.png';
import Image3 from '@site/static/files/facilitator/image3.png';
import Image4 from '@site/static/files/facilitator/image4.png';
import Image5 from '@site/static/files/facilitator/image5.png';
import Image6 from '@site/static/files/facilitator/image6.png';
import Image7 from '@site/static/files/facilitator/image7.png';

## Coding Activity Facilitator Guide

### Schedule

- Lecture (up to 1 hour);
- Python activity + Discussion (up to 2 hours);
- Google CoLab notebook ”SAL Activity” provided in Google Drive.

## Python Activity Instructions

### Introductory Lecture

Please utilize the accompanying [Introductory Lecture Slides](handbook_slides) for this activity.

### Before the Workshop

- Before the workshop begins, please send out an email to the organizers asking them to ensure that all participants have a Google GSuite account, are familiar with Google Drive, and have the Google CoLaboratory (Colab) extension installed.
- Participants should also be encouraged to explore the [Colab welcome site](https://colab.research.google.com/) prior to the workshop if they are not familiar with the platform.
- The recommended browser for this workshop is [Google Chrome](https://www.google.com/chrome/).

<details>
<summary><strong>⚠️ If participants do not have Google CoLab, they can do so with the following process (expand) </strong></summary>

#### 1. Click the “New” button on the left hand side of the Google drive page.


<br/> <br/>

#### 2. Then scroll down to the “More” option from the popup menu.


<br/> <br/>

#### 3. Next, scroll down to the “Connect More Apps” option on the second pop up menu and click on it.


<br/> <br/>

#### 4. This should bring up the Google Workspace Marketplace.


<br/> <br/>

#### 5. Use the search bar to search for Colaboratory, and select the option that shows up.


<br/> <br/>

#### 6. Click the blue “Install” button, give the extension the necessary permissions.


<br/> <br/>

#### ... and you should be set up!



</details>

### During the Workshop Introduction

Provide students with the link to the zip file containing the notebook and relevant data files:

- Ask the students to download the zip file onto their computer, and unzip the files.
- Then, ask them to upload the folder to their Google Drive and rename the folder “THEIRNAME_WorkshopName”. The path to get to the folder should be ‘/content/drive/My Drive/THEIRNAME_WorkshopName.
- Ask the students to modify the path in Block 4 to reflect this During the Workshop
- When the students run code block #13, which creates the first .html map, let them know that the .html file will be saved in the Google Drive folder they created. - They will need to download the file onto their computers and then double click to open it in their web browser and interact with it.
- Please ensure they know which location they are saving the .html file to (eg, Desktop or Downloads folder).

### Discussion prompts

- What do you think the biggest issues surrounding pollution hotspots in The Bronx are,
  versus where you are?
- Have you, your friends, family, or coworkers been affected by air pollution? What do you
  hope can be done about it?
- Share what you learned about different methods of environmental sensing.

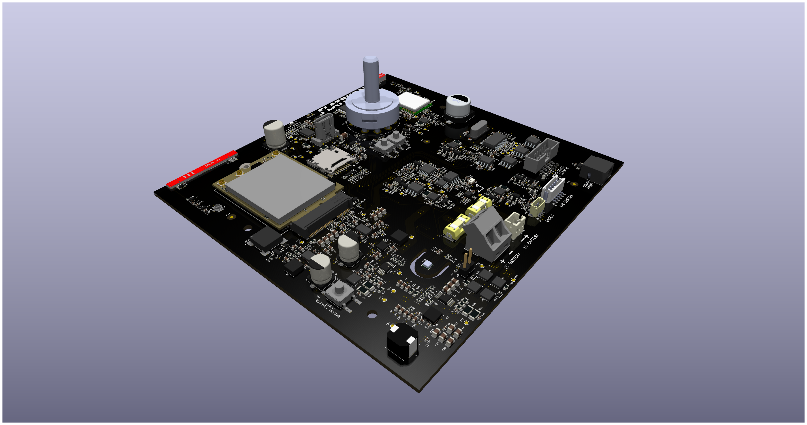
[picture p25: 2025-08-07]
hardware/electronics/Doc/Flatburn_3D_Models/VIEW.png

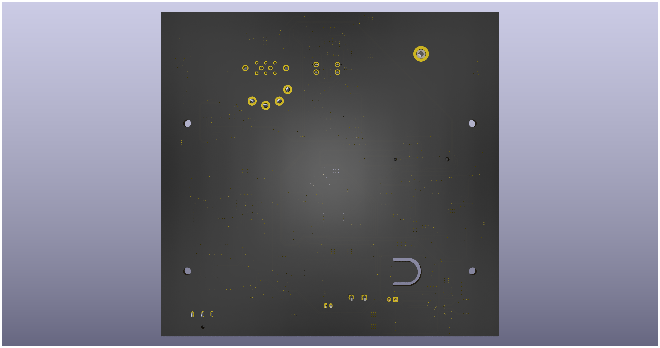
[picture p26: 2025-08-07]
hardware/electronics/Doc/Flatburn_3D_Models/BOTTOM.png

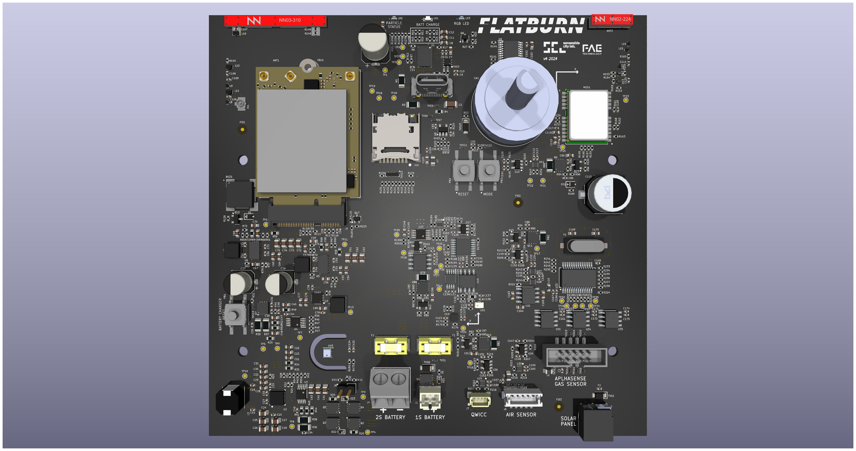
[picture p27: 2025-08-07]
hardware/electronics/Doc/Flatburn_3D_Models/TOP.png

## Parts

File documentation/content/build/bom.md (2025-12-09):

---
sidebar_position: 2
---

# 📦 Bill Of Materials

<!-- a nice top-down photo can be put here following the previous version below -->
<!-- ![Parts](@site/static/files/bom/parts.jpg) -->

:::info
The list below refers to a single device.
:::

### Identifier standard (ID)

All names follow the same _pattern:_

```
    X Y _ NN _ ( Z / NNN )
```

- **X** → Electronics, Mechanics, Consumables or Accessories
- **Y** → Type
- **N** → Crescent number
- **Z** → Different alternatives (A, B, C, ...)
  _or_
  **N** → Crescent sub-number

## ⚡ Electronics

:::warning
Depending on where the device will be deployed a different type of **Particle MCU** will be needed.

Make sure you order the correct option, being **EL_01_A for North America** or **EL_01_B for Europe**.
:::

### General Parts

| ID | Type | Subtype | Specification | URL |  Qty  |
| :--- | :--- | :--- | :--- | :---: | :---: |
| EB_01 | Board | Main | Custom | [custom](#boards) | 1 |
| **EL_01_A** | Logic | MCU | Particle B-SoM LTE-M B404X (for North America) | [link](https://store.particle.io/collections/cellular/products/b-series-lte-cat-m1-noram-with-ethersim) |  (1)  |
| **EL-01_B** | Logic | MCU | Particle B-SoM LTE B524 (for Europe) | [link](https://store.particle.io/collections/cellular/products/b-series-lte-cat1-3g-2g-europe-ethersim) |  (1)  |
| EP_01 | Power | Battery | Lithium Ion Battery - 3.7V 10050mAh (10 Ah) | [link](https://www.adafruit.com/product/5035) | 1 |
| EP_02 | Power | Solar Panel  | Voltaic Systems P105 - 5.5W 6V Solar Panel | [link](https://www.amazon.com/Voltaic-Systems-Small-Solar-Panel/dp/B085W9KG6V) | 1 |
| ES_01 | Sensor  | Gas | Alphasense A4x2 (CO+NO2) + AFE board | [link](https://www.alphasense.com) | 1 |
| ES_02 | Sensor  | Particulate  | Sensirion SPS30 | [link](https://www.digikey.com/en/products/detail/sensirion-ag/SPS30/9598990) | 1 |
| EH_01 | Harness | Cable | U.FL to U.FL – CINCH 415-0086-050 | [link](https://www.digikey.com/en/products/detail/cinch-connectivity-solutions-johnson/415-0086-050/1305528) | 1 |
| EH_03 | Harness | Cable | AreMe – 90 Degree USB-C male to female | [link](https://www.amazon.com/gp/product/B0CQH48YFQ/) | 1 |
| EH_04 | Harness | Cable | Qianrenon – 90º Waterproof USB-C "pass through" 30cm | [link](https://www.amazon.com/gp/product/B0BPCHR24G/) | 1 |
| EV_01 | Vault | Storage Card | 32GB MicroSD | [link](https://www.amazon.com/dp/B08GY9NYRM/) | 1 |

### Custom Parts

#### Boards

Due to the quantity of items, these lists are available in a dedicated spreadsheet:
- [📝 Main Board](https://github.com/MIT-Senseable-City-Lab/flatburn-lte/blob/main/hardware/Production/BOM_Flatburn_V5.csv) (2025-04-18)

#### Cables

| ID | Type | Subtype | From  |  To | Specification | URL |  Qty  |
| :--- | :--- | :--- | :---: | :---: | :--- | :---: | :---: |
| EH_02_01 | Harness | Wire | EB_01 | ES_02 | 0.08 mm2 (AWG 28) x 300 mm | [link](https://www.digikey.com/en/products/detail/cnc-tech/10064-28-1-0500-001-1-TS/4486265)  | 5 |
| EH_02_02 | Harness | Socket | EB_01 | ES_02 | JST SZH-002T-P0.5 | [link](https://www.digikey.com/en/products/detail/jst-sales-america-inc/szh-002t-p0-5/527363) |  10 |
| EH_02_03 | Harness | Housing | EB_01 | ES_02 | JST ZHR-5 | [link](https://www.digikey.com/en/products/detail/jst-sales-america-inc/ZHR-5/608642) | 2 |

<!-- | EH_01_01 | Harness | Wire      | EB_01 | ES_01 | TBD                        |                                              TBD                                              |   1   | --> 
<!-- | EH_01_02 | Harness | Connector | EB_01 | ES_01 | TBD                        |                                              TBD                                              |   2   | --> 

<!-- :::tip
💡 You can buy these boards fully assembled together with cables by contacting [My Fast PCBA from FAE Technology S.p.a.](myfastpcba@fae.technology).
::: --> 

## ⚙️ Mechanics

### General Parts

| ID | Type | Subtype | Specification | URL |  Qty  |
| :---- | :--- | :--- | :--- | :---: | :---: |
| MM_01 | Mounting | Magnet | RigMount Magnetic 1/4" Mount – Long | [link](https://www.rigwheels.com/product/magnetic-mount/) | 2 |
| MF_01 | Fixation | Brass Insert | 1/4" – for Plastic | [link](https://www.mcmaster.com/94459A390/) | 2 |
| MF_02 | Fixation | Brass Insert | M2 – flanged, for Plastic | [link](https://www.mcmaster.com/97171A300/) | 7 |
| MF_03 | Fixation | Brass Insert | M3 - tapered, for Plastic | [link](https://www.mcmaster.com/94180A331/) |  13 |
| MF_04 | Fixation | Stainless Screw | M2X6 – socket head hex | [link](https://www.mcmaster.com/91292A831/) | 7 |
| MF_05 | Fixation | Stainless Screw | M2.5X4 – socket head hex | [link](https://www.mcmaster.com/91292A015/) | 1 |
| MF_06 | Fixation | Stainless Screw | M3X16 – socket head hex | [link](https://www.mcmaster.com/91292A115/) |  13 |
| MF_07 | Fixation | Spacer | M3 6mm spacer – ABS | [link](https://www.amazon.com/dp/B09N2NKNDJ?smid=A2U2UFFPJ8JX7R) | 6 |
| MS_01 | Sealing  | O-Ring | Oil-Resistant Buna-N – 3/32 Fractional Width, Dash 116 | [link](https://www.mcmaster.com/9452K28/) | 2 |
| MS_02 | Sealing  | O-Ring Cord | Oil-Resistant Soft Buna-N – 3/32 Fractional Width | [link](https://www.mcmaster.com/9864K25/) | 2 ft  |

### [3D Printed Parts](./mechanics)

More info in the [mechanics](./mechanics) section.

## 🧵 Consumables

| ID | Type  | Subtype  | Specification | URL |  Qty |
| :---- | :---- | :--- | :--- | :---: | :----: |
| CP_01 | Print | Filament | PLA White | [link](https://us.store.bambulab.com/collections/bambu-lab-3d-printer-filament/products/pla-basic-filament) | 0.7 kg |

## 🔌 Accessories

:::info
The device uses USB-C for charging, flashing firmware and transfering data.

Please, choose among the cable options below according to your needs (A or B).
:::

### General

| ID | Type  | Subtype | Specification | URL |  Qty  |
| :--- | :---- | :--- | :--- | :---: | :---: |
| AL_01_A | Logic | Data + power cable | USB-C → USB-C | [link](https://www.amazon.com/Amazon-Basics-Charging-Transfer-Certified/dp/B085SB6RSN/) | 1 |
| AL_01_B | Logic | Data + power cable | USB-C → USB-A |  [link](https://www.amazon.com/Amazon-Basics-Charger-480Mbps-Certified/dp/B01GGKYN0A/)  | 1 |
| AP_01_A | Power | Outlet Charger | USB-C, 30 Watts, Bivolt | [link](https://www.amazon.com/dp/B0B2MM1W65/ref=twister_B0DNYG7ZY9) | 1 |

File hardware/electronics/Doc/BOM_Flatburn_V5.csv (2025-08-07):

Item | Reference | Value | MPN | Description | Distributor | Pkg Type | Footprint | Notes
1 | ANT1 | NN03-310 | NN03-310 | Ignion TRIO mXTENDT (NN03-310),GSM, UMTS, LTE, LTE-M, NB-IoT, 5G, GNSS, Bluetooth, 400-8000MHz, 30X3X1mm | M-128-NN03-310 | SMD | FAE-ANT:XCVR_NN03-310
2 | ANT2 | NN02-224 | NN02-224 | Ignion RUN mXTENDâ„¢ (NN02-224) GNSS antenna, 824-8000 MHz | M-128-NN02-224 | SMD | FAE-ANT:XCVR_NN02-224
3 | BUZ1 | ST-025BH | ST-025BH | BUZZER MAGN 3V 7.5X7.5 SMD, 2,7KHz, 8RdBA | D-433-1087-2-ND | SMD | FAE-BUZZ:ST-025BH_SOB
4 | C1 | 100n/50V |  | CHIP CAP.CER. 100nF 50V 10% X7R 0402 | FAE-043362 | SMD | Capacitor_SMD:C_0402_1005Metric
5 | C2 | 10n/1kV |  | CHIP CAP.CER. 10nF 1kV 10% X7R 1206 | FAE-028470 | SMD | Capacitor_SMD:C_1206_3216Metric
6 | C3 | 100n/50V |  | CHIP CAP.CER. 100nF 50V 10% X7R 0402 | FAE-043362 | SMD | Capacitor_SMD:C_0402_1005Metric
7 | C4 | 100n/50V |  | CHIP CAP.CER. 100nF 50V 10% X7R 0402 | FAE-043362 | SMD | Capacitor_SMD:C_0402_1005Metric
8 | C5 | 10n/50V |  | CHIP CAP.CER. 10nF 50V 10% X7R 0402 | FAE-101362 | SMD | Capacitor_SMD:C_0402_1005Metric
9 | C6 | 10n/50V |  | CHIP CAP.CER. 10nF 50V 10% X7R 0402 | FAE-101362 | SMD | Capacitor_SMD:C_0402_1005Metric
10 | C7 | 4.7u/35V |  | CHIP CAP.CER. 4.7u 35V 10% X5R 0603 | FAE-057733 | SMD | Capacitor_SMD:C_0603_1608Metric
11 | C8 | 10u/10V |  | CHIP CAP.CER. 10u 10V 10% X5R 0603 | FAE-028168 | SMD | Capacitor_SMD:C_0603_1608Metric
12 | C9 | 330p/10V | C0402C331K8RACTU | CHIP CAP.CER. 330p 10V 10% X7R 0402 | M-80-C0402C331K8R | SMD | Capacitor_SMD:C_0402_1005Metric
13 | C10 | 330p/10V | C0402C331K8RACTU | CHIP CAP.CER. 330p 10V 10% X7R 0402 | M-80-C0402C331K8R | SMD | Capacitor_SMD:C_0402_1005Metric
14 | C11 | 10u/10V |  | CHIP CAP.CER. 10u 10V 10% X5R 0603 | FAE-028168 | SMD | Capacitor_SMD:C_0603_1608Metric
15 | C12 | 4.7u/10V |  | CHIP CAP.CER. 4.7u 10V 10% X5R 0603 | FAE-033362 | SMD | Capacitor_SMD:C_0603_1608Metric
16 | C13 | 47u/50V | GXC1H470MCQ1GS | AL ORG POLR. 47u 50V 20% 8X10 | M-647-GXC1H470MCQ1GS | SMD | Capacitor_SMD:CP_Elec_8x10
17 | C14 | 10n/50V |  | CHIP CAP.CER. 10nF 50V 10% X7R 0402 | FAE-101362 | SMD | Capacitor_SMD:C_0402_1005Metric
18 | C15 | 47n/25V |  | CHIP CAP.CER. 47nF 25V 10% X7R 0402 | FAE-029703 | SMD | Capacitor_SMD:C_0402_1005Metric
19 | C16 | 47n/25V |  | CHIP CAP.CER. 47nF 25V 10% X7R 0402 | FAE-029703 | SMD | Capacitor_SMD:C_0402_1005Metric
20 | C17 | 10u/50V | GRM21BR61H106KE43L | CHIP CAP.CER. 10u 50V 10% X5R 0805 | M-81-GRM21BR61H106KE3L | SMD | Capacitor_SMD:C_0805_2012Metric
21 | C18 | 10u/50V | GRM21BR61H106KE43L | CHIP CAP.CER. 10u 50V 10% X5R 0805 | M-81-GRM21BR61H106KE3L | SMD | Capacitor_SMD:C_0805_2012Metric
22 | C19 | 100n/50V |  | CHIP CAP.CER. 100nF 50V 10% X7R 0402 | FAE-043362 | SMD | Capacitor_SMD:C_0402_1005Metric
23 | C20 | 1n/50V |  | CHIP CAP.CER. 1nF 50V 10% X7R 0402 | FAE-043572 | SMD | Capacitor_SMD:C_0402_1005Metric
24 | C21 | 4.7u/10V |  | CHIP CAP.CER. 4.7u 10V 10% X5R 0603 | FAE-033362 | SMD | Capacitor_SMD:C_0603_1608Metric
25 | C22 | 10u/25V |  | CHIP CAP.CER. 10u 25V 20% X5R 0603 | FAE-055937 | SMD | Capacitor_SMD:C_0603_1608Metric
26 | C23 | 10u/25V |  | CHIP CAP.CER. 10u 25V 20% X5R 0603 | FAE-055937 | SMD | Capacitor_SMD:C_0603_1608Metric
27 | C24 | 10u/50V | GRM21BR61H106KE43L | CHIP CAP.CER. 10u 50V 10% X5R 0805 | M-81-GRM21BR61H106KE3L | SMD | Capacitor_SMD:C_0805_2012Metric
28 | C25 | 10u/50V | GRM21BR61H106KE43L | CHIP CAP.CER. 10u 50V 10% X5R 0805 | M-81-GRM21BR61H106KE3L | SMD | Capacitor_SMD:C_0805_2012Metric
29 | C26 | 10u/50V | GRM21BR61H106KE43L | CHIP CAP.CER. 10u 50V 10% X5R 0805 | M-81-GRM21BR61H106KE3L | SMD | Capacitor_SMD:C_0805_2012Metric
30 | C27 | 100n/50V |  | CHIP CAP.CER. 100nF 50V 10% X7R 0402 | FAE-043362 | SMD | Capacitor_SMD:C_0402_1005Metric
31 | C28 | 10u/25V | GRM188R61E106KA73D | CHIP CAP.CER. 10u 25V 10% X5R 0603 | M-81-GRM188R61E106KA3D | SMD | Capacitor_SMD:C_0603_1608Metric
32 | C29 | 10u/25V | GRM188R61E106KA73D | CHIP CAP.CER. 10u 25V 10% X5R 0603 | M-81-GRM188R61E106KA3D | SMD | Capacitor_SMD:C_0603_1608Metric
33 | C30 | 10u/25V | GRM188R61E106KA73D | CHIP CAP.CER. 10u 25V 10% X5R 0603 | M-81-GRM188R61E106KA3D | SMD | Capacitor_SMD:C_0603_1608Metric
34 | C31 | 10u/25V | GRM188R61E106KA73D | CHIP CAP.CER. 10u 25V 10% X5R 0603 | M-81-GRM188R61E106KA3D | SMD | Capacitor_SMD:C_0603_1608Metric
35 | C32 | 10u/25V | GRM188R61E106KA73D | CHIP CAP.CER. 10u 25V 10% X5R 0603 | M-81-GRM188R61E106KA3D | SMD | Capacitor_SMD:C_0603_1608Metric
36 | C33 | 100n/50V |  | CHIP CAP.CER. 100nF 50V 10% X7R 0402 | FAE-043362 | SMD | Capacitor_SMD:C_0402_1005Metric
37 | C34 | 100n/50V |  | CHIP CAP.CER. 100nF 50V 10% X7R 0402 | FAE-043362 | SMD | Capacitor_SMD:C_0402_1005Metric
38 | C35 | 100n/50V |  | CHIP CAP.CER. 100nF 50V 10% X7R 0402 | FAE-043362 | SMD | Capacitor_SMD:C_0402_1005Metric
39 | C36 | 10p/50V | GCM1555C1H100JA16D | CHIP CAP.CER. 10p 50V 5% C0G 0402 | FAE-043366 | SMD | Capacitor_SMD:C_0402_1005Metric
40 | C37 | 220u/25V | UCM1E221MCL1GS | EL POLR. 220u 25V 20% 6,3x7,7 | M-647-UCM1E221MCL1GS | SMD | Capacitor_SMD:CP_Elec_6.3x7.7
41 | C38 | 220u/25V | UCM1E221MCL1GS | EL POLR. 220u 25V 20% 6,3x7,7 | M-647-UCM1E221MCL1GS | SMD | Capacitor_SMD:CP_Elec_6.3x7.7
42 | C39 | NU |  | CHIP CAP.CER. 100nF 50V 10% X7R 0402 | FAE-043362 | SMD | Capacitor_SMD:C_0402_1005Metric | NOT MOUNTED
43 | C40 | 100n/50V |  | CHIP CAP.CER. 100nF 50V 10% X7R 0402 | FAE-043362 | SMD | Capacitor_SMD:C_0402_1005Metric
44 | C41 | 1u/50V |  | CHIP CAP.CER. 1u 50V 10% X7R 0805 | FAE-027166 | SMD | Capacitor_SMD:C_0805_2012Metric
45 | C42 | 1u/50V |  | CHIP CAP.CER. 1u 50V 10% X7R 0805 | FAE-027166 | SMD | Capacitor_SMD:C_0805_2012Metric
46 | C43 | 1u/50V |  | CHIP CAP.CER. 1u 50V 10% X7R 0805 | FAE-027166 | SMD | Capacitor_SMD:C_0805_2012Metric
47 | C44 | 100n/50V |  | CHIP CAP.CER. 100nF 50V 10% X7R 0402 | FAE-043362 | SMD | Capacitor_SMD:C_0402_1005Metric
48 | C45 | 1u/25V | CL10B105KA8NNNC | CHIP CAP.CER. 1u 25V 10% X7R 0603 | FAE-100573 | SMD | Capacitor_SMD:C_0603_1608Metric
49 | C46 | 1u/25V | CL10B105KA8NNNC | CHIP CAP.CER. 1u 25V 10% X7R 0603 | FAE-100573 | SMD | Capacitor_SMD:C_0603_1608Metric
50 | C47 | 1u/25V | CL10B105KA8NNNC | CHIP CAP.CER. 1u 25V 10% X7R 0603 | FAE-100573 | SMD | Capacitor_SMD:C_0603_1608Metric
51 | C48 | NU |  | CHIP CAP.CER. 100nF 50V 10% X7R 0402 | FAE-043362 | SMD | Capacitor_SMD:C_0402_1005Metric | NOT MOUNTED
52 | C49 | 100n/50V |  | CHIP CAP.CER. 100nF 50V 10% X7R 0402 | FAE-043362 | SMD | Capacitor_SMD:C_0402_1005Metric
53 | C50 | 100n/50V |  | CHIP CAP.CER. 100nF 50V 10% X7R 0402 | FAE-043362 | SMD | Capacitor_SMD:C_0402_1005Metric
54 | C51 | 100n/50V |  | CHIP CAP.CER. 100nF 50V 10% X7R 0402 | FAE-043362 | SMD | Capacitor_SMD:C_0402_1005Metric
55 | C52 | 100n/50V |  | CHIP CAP.CER. 100nF 50V 10% X7R 0402 | FAE-043362 | SMD | Capacitor_SMD:C_0402_1005Metric
56 | C53 | 10u/25V | GRM188R61E106KA73D | CHIP CAP.CER. 10u 25V 10% X5R 0603 | M-81-GRM188R61E106KA3D | SMD | Capacitor_SMD:C_0603_1608Metric
57 | C54 | 10u/25V | GRM188R61E106KA73D | CHIP CAP.CER. 10u 25V 10% X5R 0603 | M-81-GRM188R61E106KA3D | SMD | Capacitor_SMD:C_0603_1608Metric
58 | C55 | 100n/50V |  | CHIP CAP.CER. 100nF 50V 10% X7R 0402 | FAE-043362 | SMD | Capacitor_SMD:C_0402_1005Metric
59 | C56 | NU | GRM188R61E106KA73D | CHIP CAP.CER. 10u 25V 10% X5R 0603 | M-81-GRM188R61E106KA3D | SMD | Capacitor_SMD:C_0603_1608Metric | NOT MOUNTED
60 | C57 | 10u/25V | GRM188R61E106KA73D | CHIP CAP.CER. 10u 25V 10% X5R 0603 | M-81-GRM188R61E106KA3D | SMD | Capacitor_SMD:C_0603_1608Metric
61 | C58 | 330p/25V | C0603C331J3HACAUTO | CHIP CAP.CER. 330p 25V 5% X8R 0603 | M-80-C0603C331J3HAUTO | SMD | Capacitor_SMD:C_0603_1608Metric
62 | C59 | 22n/16V | 0603YC223J4T2A | CHIP CAP.CER. 22n 16V 5% X7R 0603 | M-581-0603YC223J4T2A | SMD | Capacitor_SMD:C_0603_1608Metric
63 | C60 | 100n/50V |  | CHIP CAP.CER. 100nF 50V 10% X7R 0402 | FAE-043362 | SMD | Capacitor_SMD:C_0402_1005Metric
64 | C61 | 22u/16V | GRM21BC81C226ME44L | CHIP CAP.CER. 22u 16V 20% X6S 0805 | M-81-GRM21BC81C226ME4L | SMD | Capacitor_SMD:C_0805_2012Metric
65 | C62 | 22u/16V | GRM21BC81C226ME44L | CHIP CAP.CER. 22u 16V 20% X6S 0805 | M-81-GRM21BC81C226ME4L | SMD | Capacitor_SMD:C_0805_2012Metric
66 | C63 | 22u/16V | GRM21BC81C226ME44L | CHIP CAP.CER. 22u 16V 20% X6S 0805 | M-81-GRM21BC81C226ME4L | SMD | Capacitor_SMD:C_0805_2012Metric
67 | C64 | 10u/25V | GRM188R61E106KA73D | CHIP CAP.CER. 10u 25V 10% X5R 0603 | M-81-GRM188R61E106KA3D | SMD | Capacitor_SMD:C_0603_1608Metric
68 | C65 | 10u/25V | GRM188R61E106KA73D | CHIP CAP.CER. 10u 25V 10% X5R 0603 | M-81-GRM188R61E106KA3D | SMD | Capacitor_SMD:C_0603_1608Metric
69 | C66 | 100n/50V |  | CHIP CAP.CER. 100nF 50V 10% X7R 0402 | FAE-043362 | SMD | Capacitor_SMD:C_0402_1005Metric
70 | C67 | NU | GRM188R61E106KA73D | CHIP CAP.CER. 10u 25V 10% X5R 0603 | M-81-GRM188R61E106KA3D | SMD | Capacitor_SMD:C_0603_1608Metric | NOT MOUNTED
71 | C68 | 10u/25V | GRM188R61E106KA73D | CHIP CAP.CER. 10u 25V 10% X5R 0603 | M-81-GRM188R61E106KA3D | SMD | Capacitor_SMD:C_0603_1608Metric
72 | C69 | 560p/25V | GRM1885C1E561JA01D | CHIP CAP.CER. 560p 25V 1% C0G 0603 | M-81-GRM185C1E561JA01D | SMD | Capacitor_SMD:C_0603_1608Metric
73 | C70 | 27n/25V | C0603C273J3RACAUTO | CHIP CAP.CER. 27n 25V 5% X7R 0603 | M-80-C0603C273J3RAUTO | SMD | Capacitor_SMD:C_0603_1608Metric
74 | C71 | 100n/50V |  | CHIP CAP.CER. 100nF 50V 10% X7R 0402 | FAE-043362 | SMD | Capacitor_SMD:C_0402_1005Metric
75 | C72 | 22u/16V | GRM21BC81C226ME44L | CHIP CAP.CER. 22u 16V 20% X6S 0805 | M-81-GRM21BC81C226ME4L | SMD | Capacitor_SMD:C_0805_2012Metric
76 | C73 | 22u/16V | GRM21BC81C226ME44L | CHIP CAP.CER. 22u 16V 20% X6S 0805 | M-81-GRM21BC81C226ME4L | SMD | Capacitor_SMD:C_0805_2012Metric
77 | C74 | 22u/16V | GRM21BC81C226ME44L | CHIP CAP.CER. 22u 16V 20% X6S 0805 | M-81-GRM21BC81C226ME4L | SMD | Capacitor_SMD:C_0805_2012Metric
78 | C75 | 22u/16V | GRM21BC81C226ME44L | CHIP CAP.CER. 22u 16V 20% X6S 0805 | M-81-GRM21BC81C226ME4L | SMD | Capacitor_SMD:C_0805_2012Metric
79 | C76 | 10u/25V | GRM188R61E106KA73D | CHIP CAP.CER. 10u 25V 10% X5R 0603 | M-81-GRM188R61E106KA3D | SMD | Capacitor_SMD:C_0603_1608Metric
80 | C77 | 10u/25V | GRM188R61E106KA73D | CHIP CAP.CER. 10u 25V 10% X5R 0603 | M-81-GRM188R61E106KA3D | SMD | Capacitor_SMD:C_0603_1608Metric
81 | C78 | 3.3n/25V | 8.85E+11 | CHIP CAP.CER. 3.3nF 25V 10% X7R 0402 | M-710-885012205047 | SMD | Capacitor_SMD:C_0402_1005Metric
82 | C79 | 100n/50V |  | CHIP CAP.CER. 100nF 50V 10% X7R 0402 | FAE-043362 | SMD | Capacitor_SMD:C_0402_1005Metric
83 | C80 | 22u/16V | KGM15CR51C226MT | CHIP CAP.CER. 22u 16V 20% X5R 0603 | M-581-KGM15CR51C226MT | SMD | Capacitor_SMD:C_0603_1608Metric
84 | C81 | 100n/50V |  | CHIP CAP.CER. 100nF 50V 10% X7R 0402 | FAE-043362 | SMD | Capacitor_SMD:C_0402_1005Metric
85 | C82 | 100n/50V |  | CHIP CAP.CER. 100nF 50V 10% X7R 0402 | FAE-043362 | SMD | Capacitor_SMD:C_0402_1005Metric
86 | C83 | 100n/50V |  | CHIP CAP.CER. 100nF 50V 10% X7R 0402 | FAE-043362 | SMD | Capacitor_SMD:C_0402_1005Metric
87 | C84 | 100n/50V |  | CHIP CAP.CER. 100nF 50V 10% X7R 0402 | FAE-043362 | SMD | Capacitor_SMD:C_0402_1005Metric
88 | C85 | NU |  | CHIP CAP.CER. 100nF 50V 10% X7R 0402 | FAE-043362 | SMD | Capacitor_SMD:C_0402_1005Metric | NOT MOUNTED
89 | C86 | NU |  | CHIP CAP.CER. 100nF 50V 10% X7R 0402 | FAE-043362 | SMD | Capacitor_SMD:C_0402_1005Metric | NOT MOUNTED
90 | C87 | NU |  | CHIP CAP.CER. 100nF 50V 10% X7R 0402 | FAE-043362 | SMD | Capacitor_SMD:C_0402_1005Metric | NOT MOUNTED
91 | C88 | NU |  | CHIP CAP.CER. 100nF 50V 10% X7R 0402 | FAE-043362 | SMD | Capacitor_SMD:C_0402_1005Metric | NOT MOUNTED
92 | C89 | 10u/10V |  | CHIP CAP.CER. 10u 10V 10% X5R 0603 | FAE-028168 | SMD | Capacitor_SMD:C_0603_1608Metric
93 | C90 | 10u/10V |  | CHIP CAP.CER. 10u 10V 10% X5R 0603 | FAE-028168 | SMD | Capacitor_SMD:C_0603_1608Metric
94 | C91 | 10u/10V |  | CHIP CAP.CER. 10u 10V 10% X5R 0603 | FAE-028168 | SMD | Capacitor_SMD:C_0603_1608Metric
95 | C92 | 10u/10V |  | CHIP CAP.CER. 10u 10V 10% X5R 0603 | FAE-028168 | SMD | Capacitor_SMD:C_0603_1608Metric
96 | C93 | 100n/50V |  | CHIP CAP.CER. 100nF 50V 10% X7R 0402 | FAE-043362 | SMD | Capacitor_SMD:C_0402_1005Metric
97 | C94 | 100n/50V |  | CHIP CAP.CER. 100nF 50V 10% X7R 0402 | FAE-043362 | SMD | Capacitor_SMD:C_0402_1005Metric
98 | C95 | 100n/50V |  | CHIP CAP.CER. 100nF 50V 10% X7R 0402 | FAE-043362 | SMD | Capacitor_SMD:C_0402_1005Metric
99 | C96 | NU |  | CHIP CAP.CER. 100nF 50V 10% X7R 0402 | FAE-043362 | SMD | Capacitor_SMD:C_0402_1005Metric | NOT MOUNTED
100 | C97 | NU |  | CHIP CAP.CER. 33pF 50V 5% C0G 0402 | FAE-043360 | SMD | Capacitor_SMD:C_0402_1005Metric | NOT MOUNTED
101 | C98 | NU |  | CHIP CAP.CER. 33pF 50V 5% C0G 0402 | FAE-043360 | SMD | Capacitor_SMD:C_0402_1005Metric | NOT MOUNTED
102 | C99 | 100n/50V |  | CHIP CAP.CER. 100nF 50V 10% X7R 0402 | FAE-043362 | SMD | Capacitor_SMD:C_0402_1005Metric
103 | C100 | 10u/10V |  | CHIP CAP.CER. 10u 10V 10% X5R 0603 | FAE-028168 | SMD | Capacitor_SMD:C_0603_1608Metric
104 | C101 | 100n/50V |  | CHIP CAP.CER. 100nF 50V 10% X7R 0402 | FAE-043362 | SMD | Capacitor_SMD:C_0402_1005Metric
105 | C102 | 100n/50V |  | CHIP CAP.CER. 100nF 50V 10% X7R 0402 | FAE-043362 | SMD | Capacitor_SMD:C_0402_1005Metric
106 | C103 | 10u/10V |  | CHIP CAP.CER. 10u 10V 10% X5R 0603 | FAE-028168 | SMD | Capacitor_SMD:C_0603_1608Metric
107 | C104 | 100n/50V |  | CHIP CAP.CER. 100nF 50V 10% X7R 0402 | FAE-043362 | SMD | Capacitor_SMD:C_0402_1005Metric
108 | C105 | 10u/10V |  | CHIP CAP.CER. 10u 10V 10% X5R 0603 | FAE-028168 | SMD | Capacitor_SMD:C_0603_1608Metric
109 | C106 | 1.6p/50V | GJM1555C1H1R6WB01D | CHIP CAP.CER. 1.6pF 50V +-0.05pF C0G 0402 | M-81-GJM1555C1H1R6WB1D | SMD | Capacitor_SMD:C_0402_1005Metric
110 | C107 | 0.4p/50V | GJM1555C1HR40WB01D | CHIP CAP.CER. 0.4p 50V +-0.05p C0G 0402 | M-81-GJM1555C1HR40WB1D | SMD | Capacitor_SMD:C_0402_1005Metric
111 | C108 | 0.5p/50V | GJM1555C1HR50WB01D | CHIP CAP.CER. 0.5p 50V +-0.05p C0G 0402 | M-81-GJM1555C1HR50WB1D | SMD | Capacitor_SMD:C_0402_1005Metric
112 | C109 | 0.3p/50V | GJM1555C1HR30WB01D | CHIP CAP.CER. 0.3p 50V +-0.05p C0G 0402 | M-81-GJM1555C1HR30WB1D | SMD | Capacitor_SMD:C_0402_1005Metric
113 | C110 | 100n/50V |  | CHIP CAP.CER. 100nF 50V 10% X7R 0402 | FAE-043362 | SMD | Capacitor_SMD:C_0402_1005Metric
114 | C111 | 100n/50V |  | CHIP CAP.CER. 100nF 50V 10% X7R 0402 | FAE-043362 | SMD | Capacitor_SMD:C_0402_1005Metric
115 | C112 | 100n/50V |  | CHIP CAP.CER. 100nF 50V 10% X7R 0402 | FAE-043362 | SMD | Capacitor_SMD:C_0402_1005Metric
116 | C113 | 100n/50V |  | CHIP CAP.CER. 100nF 50V 10% X7R 0402 | FAE-043362 | SMD | Capacitor_SMD:C_0402_1005Metric
117 | C114 | 1n/50V |  | CHIP CAP.CER. 1nF 50V 10% X7R 0402 | FAE-043572 | SMD | Capacitor_SMD:C_0402_1005Metric
118 | C115 | 470mF/3.5V | FCS0V474ZFTBR24 | SUPERCAP 0.7x8.5-470mF/3.5V | M-80-FCS0V474ZFTBR24 | SMD | FAE-CAP:FCS0V474ZFTBR24_KEM
119 | C116 | 1u/25V | CL10B105KA8NNNC | CHIP CAP.CER. 1u 25V 10% X7R 0603 | FAE-100573 | SMD | Capacitor_SMD:C_0603_1608Metric
120 | C117 | 100n/50V |  | CHIP CAP.CER. 100nF 50V 10% X7R 0402 | FAE-043362 | SMD | Capacitor_SMD:C_0402_1005Metric
121 | C118 | 100n/50V |  | CHIP CAP.CER. 100nF 50V 10% X7R 0402 | FAE-043362 | SMD | Capacitor_SMD:C_0402_1005Metric
122 | C119 | 10u/10V |  | CHIP CAP.CER. 10u 10V 10% X5R 0603 | FAE-028168 | SMD | Capacitor_SMD:C_0603_1608Metric
123 | C120 | 100n/50V |  | CHIP CAP.CER. 100nF 50V 10% X7R 0402 | FAE-043362 | SMD | Capacitor_SMD:C_0402_1005Metric
124 | C121 | 1u/16V | GRM155C71C105KE11D | CHIP CAP.CER. 1uF 16V 10% X7S 0402 | M-81-GRM155C71C105KE1D | SMD | Capacitor_SMD:C_0402_1005Metric
125 | C122 | 100n/50V |  | CHIP CAP.CER. 100nF 50V 10% X7R 0402 | FAE-043362 | SMD | Capacitor_SMD:C_0402_1005Metric
126 | C123 | 100n/50V |  | CHIP CAP.CER. 100nF 50V 10% X7R 0402 | FAE-043362 | SMD | Capacitor_SMD:C_0402_1005Metric
127 | C124 | 100n/50V |  | CHIP CAP.CER. 100nF 50V 10% X7R 0402 | FAE-043362 | SMD | Capacitor_SMD:C_0402_1005Metric
128 | C125 | 100n/50V |  | CHIP CAP.CER. 100nF 50V 10% X7R 0402 | FAE-043362 | SMD | Capacitor_SMD:C_0402_1005Metric
129 | C126 | 100n/50V |  | CHIP CAP.CER. 100nF 50V 10% X7R 0402 | FAE-043362 | SMD | Capacitor_SMD:C_0402_1005Metric
130 | C127 | 1u/16V | GRM155C71C105KE11D | CHIP CAP.CER. 1uF 16V 10% X7S 0402 | M-81-GRM155C71C105KE1D | SMD | Capacitor_SMD:C_0402_1005Metric
131 | C128 | 100n/50V |  | CHIP CAP.CER. 100nF 50V 10% X7R 0402 | FAE-043362 | SMD | Capacitor_SMD:C_0402_1005Metric
132 | C129 | 100n/50V |  | CHIP CAP.CER. 100nF 50V 10% X7R 0402 | FAE-043362 | SMD | Capacitor_SMD:C_0402_1005Metric
133 | C130 | 100n/50V |  | CHIP CAP.CER. 100nF 50V 10% X7R 0402 | FAE-043362 | SMD | Capacitor_SMD:C_0402_1005Metric
134 | C131 | 100n/50V |  | CHIP CAP.CER. 100nF 50V 10% X7R 0402 | FAE-043362 | SMD | Capacitor_SMD:C_0402_1005Metric
135 | C132 | 1u/16V | GRM155C71C105KE11D | CHIP CAP.CER. 1uF 16V 10% X7S 0402 | M-81-GRM155C71C105KE1D | SMD | Capacitor_SMD:C_0402_1005Metric
136 | C133 | 100n/50V |  | CHIP CAP.CER. 100nF 50V 10% X7R 0402 | FAE-043362 | SMD | Capacitor_SMD:C_0402_1005Metric
137 | C134 | 100n/50V |  | CHIP CAP.CER. 100nF 50V 10% X7R 0402 | FAE-043362 | SMD | Capacitor_SMD:C_0402_1005Metric
138 | C135 | 100n/50V |  | CHIP CAP.CER. 100nF 50V 10% X7R 0402 | FAE-043362 | SMD | Capacitor_SMD:C_0402_1005Metric
139 | C136 | 100n/50V |  | CHIP CAP.CER. 100nF 50V 10% X7R 0402 | FAE-043362 | SMD | Capacitor_SMD:C_0402_1005Metric
140 | C137 | 1u/16V | GRM155C71C105KE11D | CHIP CAP.CER. 1uF 16V 10% X7S 0402 | M-81-GRM155C71C105KE1D | SMD | Capacitor_SMD:C_0402_1005Metric
141 | C138 | 100n/50V |  | CHIP CAP.CER. 100nF 50V 10% X7R 0402 | FAE-043362 | SMD | Capacitor_SMD:C_0402_1005Metric
142 | C139 | 1u/16V | GRM155C71C105KE11D | CHIP CAP.CER. 1uF 16V 10% X7S 0402 | M-81-GRM155C71C105KE1D | SMD | Capacitor_SMD:C_0402_1005Metric
143 | C140 | 100n/50V |  | CHIP CAP.CER. 100nF 50V 10% X7R 0402 | FAE-043362 | SMD | Capacitor_SMD:C_0402_1005Metric
144 | C141 | 100n/50V |  | CHIP CAP.CER. 100nF 50V 10% X7R 0402 | FAE-043362 | SMD | Capacitor_SMD:C_0402_1005Metric
145 | C142 | 100n/50V |  | CHIP CAP.CER. 100nF 50V 10% X7R 0402 | FAE-043362 | SMD | Capacitor_SMD:C_0402_1005Metric
146 | C143 | 100n/50V |  | CHIP CAP.CER. 100nF 50V 10% X7R 0402 | FAE-043362 | SMD | Capacitor_SMD:C_0402_1005Metric
147 | C144 | 1u/16V | GRM155C71C105KE11D | CHIP CAP.CER. 1uF 16V 10% X7S 0402 | M-81-GRM155C71C105KE1D | SMD | Capacitor_SMD:C_0402_1005Metric
148 | C145 | 100n/50V |  | CHIP CAP.CER. 100nF 50V 10% X7R 0402 | FAE-043362 | SMD | Capacitor_SMD:C_0402_1005Metric
149 | C146 | 10u/10V |  | CHIP CAP.CER. 10u 10V 10% X5R 0603 | FAE-028168 | SMD | Capacitor_SMD:C_0603_1608Metric
150 | C147 | 100n/50V |  | CHIP CAP.CER. 100nF 50V 10% X7R 0402 | FAE-043362 | SMD | Capacitor_SMD:C_0402_1005Metric
151 | C148 | 100n/50V |  | CHIP CAP.CER. 100nF 50V 10% X7R 0402 | FAE-043362 | SMD | Capacitor_SMD:C_0402_1005Metric
152 | C149 | 100n/50V |  | CHIP CAP.CER. 100nF 50V 10% X7R 0402 | FAE-043362 | SMD | Capacitor_SMD:C_0402_1005Metric
153 | C150 | 100n/50V |  | CHIP CAP.CER. 100nF 50V 10% X7R 0402 | FAE-043362 | SMD | Capacitor_SMD:C_0402_1005Metric
154 | C151 | 100n/50V |  | CHIP CAP.CER. 100nF 50V 10% X7R 0402 | FAE-043362 | SMD | Capacitor_SMD:C_0402_1005Metric
155 | C152 | 100n/50V |  | CHIP CAP.CER. 100nF 50V 10% X7R 0402 | FAE-043362 | SMD | Capacitor_SMD:C_0402_1005Metric
156 | C153 | 100n/50V |  | CHIP CAP.CER. 100nF 50V 10% X7R 0402 | FAE-043362 | SMD | Capacitor_SMD:C_0402_1005Metric
157 | C154 | 100n/50V |  | CHIP CAP.CER. 100nF 50V 10% X7R 0402 | FAE-043362 | SMD | Capacitor_SMD:C_0402_1005Metric
158 | C155 | 100n/50V |  | CHIP CAP.CER. 100nF 50V 10% X7R 0402 | FAE-043362 | SMD | Capacitor_SMD:C_0402_1005Metric
159 | C156 | 100n/50V |  | CHIP CAP.CER. 100nF 50V 10% X7R 0402 | FAE-043362 | SMD | Capacitor_SMD:C_0402_1005Metric
160 | C157 | 100n/50V |  | CHIP CAP.CER. 100nF 50V 10% X7R 0402 | FAE-043362 | SMD | Capacitor_SMD:C_0402_1005Metric
161 | C158 | 100n/50V |  | CHIP CAP.CER. 100nF 50V 10% X7R 0402 | FAE-043362 | SMD | Capacitor_SMD:C_0402_1005Metric
162 | C159 | 100n/50V |  | CHIP CAP.CER. 100nF 50V 10% X7R 0402 | FAE-043362 | SMD | Capacitor_SMD:C_0402_1005Metric
163 | C160 | 100n/50V |  | CHIP CAP.CER. 100nF 50V 10% X7R 0402 | FAE-043362 | SMD | Capacitor_SMD:C_0402_1005Metric
164 | C161 | 1u/16V | GRM155C71C105KE11D | CHIP CAP.CER. 1uF 16V 10% X7S 0402 | M-81-GRM155C71C105KE1D | SMD | Capacitor_SMD:C_0402_1005Metric
165 | C162 | 100n/50V |  | CHIP CAP.CER. 100nF 50V 10% X7R 0402 | FAE-043362 | SMD | Capacitor_SMD:C_0402_1005Metric
166 | C163 | 4.7u/10V |  | CHIP CAP.CER. 4.7u 10V 10% X5R 0603 | FAE-033362 | SMD | Capacitor_SMD:C_0603_1608Metric
167 | C164 | NU | CL10B105KA8NNNC | CHIP CAP.CER. 1u 25V 10% X7R 0603 | FAE-100573 | SMD | Capacitor_SMD:C_0603_1608Metric | NOT MOUNTED
168 | C165 | 22u/16V | KGM15CR51C226MT | CHIP CAP.CER. 22u 16V 20% X5R 0603 | M-581-KGM15CR51C226MT | SMD | Capacitor_SMD:C_0603_1608Metric
169 | C166 | 1u/16V | GRM155C71C105KE11D | CHIP CAP.CER. 1uF 16V 10% X7S 0402 | M-81-GRM155C71C105KE1D | SMD | Capacitor_SMD:C_0402_1005Metric
170 | C167 | 100n/50V |  | CHIP CAP.CER. 100nF 50V 10% X7R 0402 | FAE-043362 | SMD | Capacitor_SMD:C_0402_1005Metric
171 | C168 | 100n/50V |  | CHIP CAP.CER. 100nF 50V 10% X7R 0402 | FAE-043362 | SMD | Capacitor_SMD:C_0402_1005Metric
172 | C169 | 18p/50V | C0603C180J5GAC7411 | CHIP CAP.CER. 18p 50V 5% C0G 0603 | M-80-C0603C180J5G7411 | SMD | Capacitor_SMD:C_0603_1608Metric
173 | C170 | 18p/50V | C0603C180J5GAC7411 | CHIP CAP.CER. 18p 50V 5% C0G 0603 | M-80-C0603C180J5G7411 | SMD | Capacitor_SMD:C_0603_1608Metric
174 | C171 | 1u/16V | GRM155C71C105KE11D | CHIP CAP.CER. 1uF 16V 10% X7S 0402 | M-81-GRM155C71C105KE1D | SMD | Capacitor_SMD:C_0402_1005Metric
175 | C172 | 100n/50V |  | CHIP CAP.CER. 100nF 50V 10% X7R 0402 | FAE-043362 | SMD | Capacitor_SMD:C_0402_1005Metric
176 | C173 | 1u/16V | GRM155C71C105KE11D | CHIP CAP.CER. 1uF 16V 10% X7S 0402 | M-81-GRM155C71C105KE1D | SMD | Capacitor_SMD:C_0402_1005Metric
177 | C174 | 100n/50V |  | CHIP CAP.CER. 100nF 50V 10% X7R 0402 | FAE-043362 | SMD | Capacitor_SMD:C_0402_1005Metric
178 | CABLE1 | U.FL | 2016493-1 | U.FL cable 30MM Right angle | M-571-2016493-1 | SMD
179 | D1 | 1N4148WS | 1N4148WS | Diode VR 100V, 0.15A | M-637-1N4148WS | SMD | Diode_SMD:D_SOD-323F
180 | DS1 | BAT54J | BAT54J,115 | Schottky 30V/0.2A , SOD-323F | FAE-034244 | SMD | Diode_SMD:D_SOD-323F
181 | DZ1 | NU | BZT52C12T-7 | Zener 12V 300mW | M-621-BZT52C12T-7 | SMD | Diode_SMD:D_SOD-523 | NOT MOUNTED
182 | DZ2 | BZT52C12T-7 | BZT52C12T-7 | Zener 12V 300mW | M-621-BZT52C12T-7 | SMD | Diode_SMD:D_SOD-523
183 | DZ3 | BZT52C12T-7 | BZT52C12T-7 | Zener 12V 300mW | M-621-BZT52C12T-7 | SMD | Diode_SMD:D_SOD-523
184 | F1 | 01543.15DR | 01543.15DR | Fuse Holder + Fuse: 4533.15, 3.15A | M-576-01543.15DR | SMD | FAE-FUSE:154SERIES
185 | F2 | NU | 0154005.DR | Fuse Holder + Fuse: 453005.0, 5A | M-576-0154005.DR | SMD | FAE-FUSE:154SERIES | NOT MOUNTED
186 | J1 | B2B-PH-K-S(LF)(SN) | B2B-PH-K-S(LF)(SN) | CONN JACK R/A PCB 3.5X1.1MM | M-306-B2BPHKSLFSNPP | THT | Connector_JST:JST_PH_B2B-PH-K_1x02_P2.00mm_Vertical
187 | J2 | 54-00125 | 54-00125 | CONN JACK R/A PCB 3.5X1.1MM | D-839-1508-ND | THT | FAE-CONN:54-00125
188 | J3 | DX07S024WJ3R400 | DX07S024WJ3R400 | USB Connectors Vert Mount Type C Recept 10mm Height | M-656-DX07S0024WJ3R400 | SMD | FAE-CONN:DX07S024WJ3R400
189 | J4 | NU | 39543-4302 | 5.00mm Pitch Eurostyle 45Â° Wire Entry Fixed Mount PCB Terminal Block, 2 Circuits | M-538-39543-4302 | THT | FAE-CONN:39543-4302 | NOT MOUNTED
190 | J5 | SBH21-NBPN-D05-SM-BK | SBH21-NBPN-D05-SM-BK | CONN JACK R/A PCB 3.5X1.1MM | D-S9036-ND | SMD | FAE-CONN:SBH21-NBPN-D05-SM-BK
191 | J6 | B5B-ZR-SM4-TF | B5B-ZR-SM4-TF | JST, 5P, Vertical SMD | D-455-1684-2-ND | SMD | FAE-CONN:B5B-ZR-SM4-TF
192 | J7 | BM04B-SRSS-TB | BM04B-SRSS-TB | SH series 1.0mm pitch, 50V, 1.0A | D-455-BM04B-SRSS-TBTR-ND | SMD | FAE-CONN:BM04B-SRSS_JST
193 | J8 | STRIP-2P-M |  |  | FAE-038144 | THT | Connector_PinHeader_2.54mm:PinHeader_1x02_P2.54mm_Vertical
194 | J9 | MDT420E01001 | MDT420E01001 | PCI Express/PCI Connectors PCIe M2 Connectors P=05mm H=42mm Key E | M-523-MDT420E01001 | SMD | FAE-CONN:MDT420E01001
195 | J10 | DM3CS-SF | DM3CS-SF | uSD hinged type | M-798-DM3CSSF | SMD | FAE-CONN:DM3CSSF
196 | J11 | U.FL-R-SMT-1(10) | U.FL-R-SMT-1(10) | Coaxial/RF connector 50Ohm HIROSE | FAE-028096 | SMD | FAE-CONN:U.FL-R-SMT-1(10)
197 | L1 | BLM21PG221SN1D | BLM21PG221SN1D | SDM Ferrite Beads 220Ohm/2A - 25%, 0805 | M-81-BLM21P221SG | SMD | Inductor_SMD:L_0805_2012Metric
198 | L2 | BLM21PG221SN1D | BLM21PG221SN1D | SDM Ferrite Beads 220Ohm/2A - 25%, 0805 | M-81-BLM21P221SG | SMD | Inductor_SMD:L_0805_2012Metric
199 | L3 | SPM6550T-1R0M100A | SPM6550T-1R0M100A | SDM 1.0uH, 20% 6550 Metal | M-810-SPM6550T1R0M100A | SMD | FAE-IND:SPM6550
200 | L4 | XGL4020-102MEC | XGL4020-102MEC | SDM 1uH, 20% ,Isat8.8A, 1616 | D-4652-XGL4020-102MEC-ND | SMD | Inductor_SMD:L_Coilcraft_XxL4020
201 | L5 | XGL4020-102MEC | XGL4020-102MEC | SDM 1uH, 20% ,Isat8.8A, 1616 | D-4652-XGL4020-102MEC-ND | SMD | Inductor_SMD:L_Coilcraft_XxL4020
202 | L6 | XGL4025-222MEC | XGL4025-222MEC | SDM 2.2uH, 20% ,Isat6.3A, 1616 | D-4652-XGL4025-222MEC-ND | SMD | Inductor_SMD:L_Coilcraft_XxL4020
203 | L7 | BLM21PG221SN1D | BLM21PG221SN1D | SDM Ferrite Beads 220Ohm/2A - 25%, 0805 | M-81-BLM21P221SG | SMD | Inductor_SMD:L_0805_2012Metric
204 | L8 | LQW15AN1N3C80D | LQW15AN1N3C80D | SDM 1.3nH/3.15A, +-0.2nH | M-81-LQW15AN1N3C80D | SMD | FAE-IND:LQW15AN4N1G80D
205 | L9 | LQW15AN2N3G80D | LQW15AN2N3G80D | SDM 2.3nH/2.53A, 2% | M-81-LQW15AN2N3G80D | SMD | FAE-IND:LQW15AN2N3G80D
206 | L10 | LQW18AN15NG80D | LQW18AN15NG80D | SDM 2.3nH/2.53A, 2% | M-81-LQW18AN15NG80D | SMD | FAE-IND:LQW18AN7N2G80D
207 | L11 | LQW18AN9N9G80D | LQW18AN9N9G80D | SDM 9.9nH/1.6A, 2% | M-81-LQW18AN9N9G80D | SMD | FAE-IND:LQW18AN7N2G80D
208 | L12 | LQW18AN10NG80D | LQW18AN10NG80D | SDM 10nH/1.6A, 2% | M-81-LQW18AN10NG80D | SMD | FAE-IND:LQW18AN7N2G80D
209 | L13 | LQW15AN7N5H00D | LQW15AN7N5H00D | SDM 7.5nH/570mA, 3% | M-81-LQW15AN7N5H00D | SMD | FAE-IND:LQW15AN7N5H00D
210 | L14 | LQW15AN7N1G80D | LQW15AN7N1G80D | SDM 7.1nH/1.42A, 2% | M-81-LQW15AN7N1G80D | SMD | FAE-IND:LQW15AN4N1G80D
211 | L15 | LQW15AN4N6G80D | LQW15AN4N6G80D | SDM 4.6nH/1.45A, 2% | M-81-LQW15AN4N6G80D | SMD | FAE-IND:LQW15AN4N1G80D
212 | L16 | LQM18PN2R2MGHD | LQM18PN2R2MGHD | SDM 2.2uH, 20% ,Isat0.35A, 0603 | M-81-LQM18PN2R2MGHD | SMD | Inductor_SMD:L_0603_1608Metric
213 | LD1 | IN-S63ASR | IN-S63ASR | RED led diode, right view, 2,6V, 20mA, | M-743-IN-S63ASR | SMD | FAE-DIODES:INS63ASR
214 | LD2 | IN-S63TBS5R5G5B | IN-S63TBS5R5G5B | RGB led diode, right view, 1.9 V, 2.8 V, 2.8 V, 5mA | M-743-IN-S63TBS5R5G5B | SMD | FAE-DIODES:INS63TBS5R5G5B
215 | LD3 | IN-S63TBS5R5G5B | IN-S63TBS5R5G5B | RGB led diode, right view, 1.9 V, 2.8 V, 2.8 V, 5mA | M-743-IN-S63TBS5R5G5B | SMD | FAE-DIODES:INS63TBS5R5G5B
216 | MOD1 | NEO-M8U-06B | NEO-M8U-06B | GNSS/GPS Modules u-blox M8 | M-377-NEO-M8U-06B | SMD | FAE-MOD:MOD24_NEO-M8U_UBL
217 | OBJ1 | 9774025151R | 9774025151R | STEEL SPACER 5.1X2.5mm, M2.5, W.E. | FAE-044635 | THT | FAE-MEC:SPACER M2.5 - 9774025151R
218 | OBJ2 | KNOB M2.5x4-INOX |  | Hexagon socket cylindrical head screw, Cl 12.9 DIN 912 UNI 5931, M2.54X4 | FAE-048266 | THT
219 | PB1 | 1571634-2 | 1571634-2 | PB SPST 24V 50mA OFF-(ON) | M-506-1571634-2 | SMD | FAE-SWITCH:15716342
220 | PB2 | 1571634-2 | 1571634-2 | PB SPST 24V 50mA OFF-(ON) | M-506-1571634-2 | SMD | FAE-SWITCH:15716342
221 | PB3 | 1571634-2 | 1571634-2 | PB SPST 24V 50mA OFF-(ON) | M-506-1571634-2 | SMD | FAE-SWITCH:15716342
222 | Q1 | NU | SISH402DN-T1-GE3 | PMOS, 30Vdss RDS 8mOhm 20Vgss 35A Id | M-78-SISH402DN-T1-GE3 | SMD | FAE-TRANSISTOR:PowerPAK 121-8 | NOT MOUNTED
223 | Q2 | SISH402DN-T1-GE3 | SISH402DN-T1-GE3 | PMOS, 30Vdss RDS 8mOhm 20Vgss 35A Id | M-78-SISH402DN-T1-GE3 | SMD | FAE-TRANSISTOR:PowerPAK 121-8
224 | Q3 | SISH402DN-T1-GE3 | SISH402DN-T1-GE3 | PMOS, 30Vdss RDS 8mOhm 20Vgss 35A Id | M-78-SISH402DN-T1-GE3 | SMD | FAE-TRANSISTOR:PowerPAK 121-8
225 | Q4 | SISH402DN-T1-GE3 | SISH402DN-T1-GE3 | PMOS, 30Vdss RDS 8mOhm 20Vgss 35A Id | M-78-SISH402DN-T1-GE3 | SMD | FAE-TRANSISTOR:PowerPAK 121-8
226 | Q5 | SISH402DN-T1-GE3 | SISH402DN-T1-GE3 | PMOS, 30Vdss RDS 8mOhm 20Vgss 35A Id | M-78-SISH402DN-T1-GE3 | SMD | FAE-TRANSISTOR:PowerPAK 121-8
227 | Q6 | BSS84WQ-7-F | BSS84WQ-7-F | PMOS, -50Vdss RDS 10Ohm 20Vgss -130mA Id | M-621-BSS84WQ-7-F | SMD | Package_TO_SOT_SMD:SOT-323_SC-70
228 | Q7 | SISS27DN-T1-GE3 | SISS27DN-T1-GE3 | PMOS, -30Vdss RDS 9mOhm 20Vgss -50A Id | M-78-SISS27DN-T1-GE3 | SMD | FAE-TRANSISTOR:PowerPAK 121-8
229 | Q8 | SISS27DN-T1-GE3 | SISS27DN-T1-GE3 | PMOS, -30Vdss RDS 9mOhm 20Vgss -50A Id | M-78-SISS27DN-T1-GE3 | SMD | FAE-TRANSISTOR:PowerPAK 121-8
230 | Q9 | SISS27DN-T1-GE3 | SISS27DN-T1-GE3 | PMOS, -30Vdss RDS 9mOhm 20Vgss -50A Id | M-78-SISS27DN-T1-GE3 | SMD | FAE-TRANSISTOR:PowerPAK 121-8
231 | Q10 | SISS27DN-T1-GE3 | SISS27DN-T1-GE3 | PMOS, -30Vdss RDS 9mOhm 20Vgss -50A Id | M-78-SISS27DN-T1-GE3 | SMD | FAE-TRANSISTOR:PowerPAK 121-8
232 | Q11 | SISS27DN-T1-GE3 | SISS27DN-T1-GE3 | PMOS, -30Vdss RDS 9mOhm 20Vgss -50A Id | M-78-SISS27DN-T1-GE3 | SMD | FAE-TRANSISTOR:PowerPAK 121-8
233 | Q12 | DMN63D8L-7 | DMN63D8L-7 | NMOS, 30Vdss RDS 2,8Ohm 20Vgss -350mA Id | M-621-DMN63D8L-7 | SMD | Package_TO_SOT_SMD:SOT-23
234 | Q13 | DMN63D8L-7 | DMN63D8L-7 | NMOS, 30Vdss RDS 2,8Ohm 20Vgss -350mA Id | M-621-DMN63D8L-7 | SMD | Package_TO_SOT_SMD:SOT-23
235 | Q14 | DMN63D8L-7 | DMN63D8L-7 | NMOS, 30Vdss RDS 2,8Ohm 20Vgss -350mA Id | M-621-DMN63D8L-7 | SMD | Package_TO_SOT_SMD:SOT-23
236 | Q15 | DMN63D8L-7 | DMN63D8L-7 | NMOS, 30Vdss RDS 2,8Ohm 20Vgss -350mA Id | M-621-DMN63D8L-7 | SMD | Package_TO_SOT_SMD:SOT-23
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

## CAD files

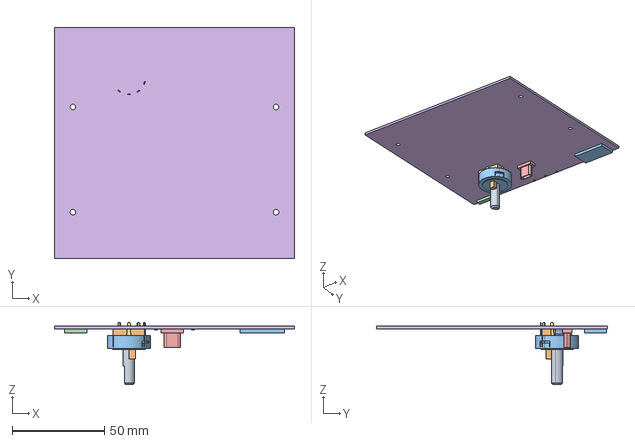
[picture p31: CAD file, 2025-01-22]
hardware/enclosure/step/electronics/EB-01 main_board.stp
130.0 x 125.0 x 33.8 mm

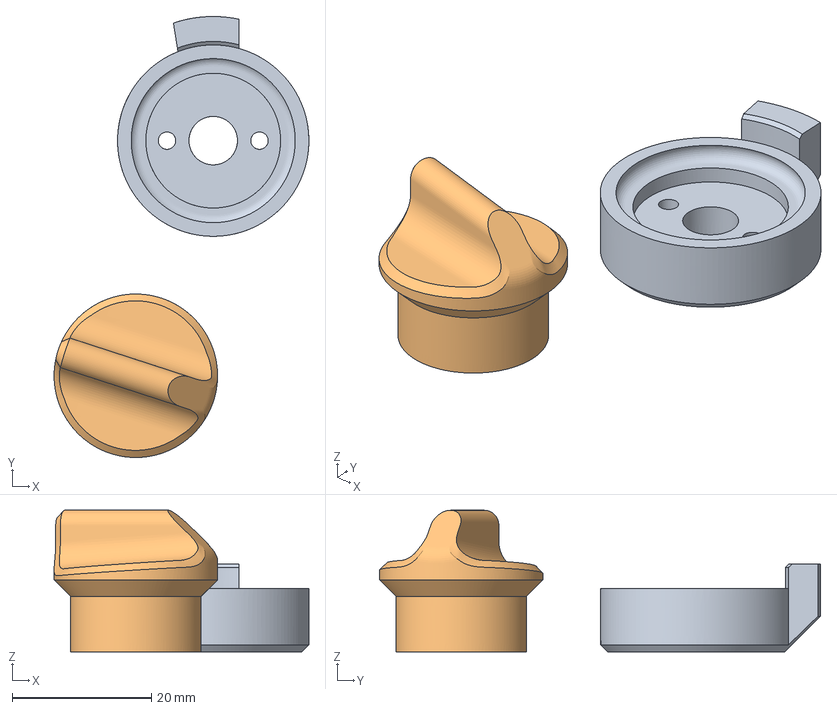
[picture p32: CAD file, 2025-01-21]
hardware/enclosure/bambu/switch_radial_R10307RN02Q.3mf
36.5 x 63.2 x 20.3 mm
MP-04 switch_top.stl
MP-05 switch_bottom.stl

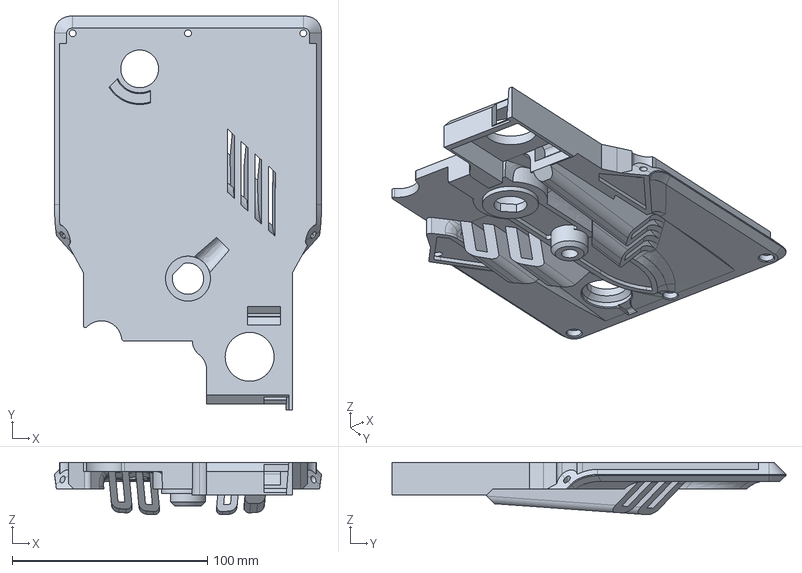
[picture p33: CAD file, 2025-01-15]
hardware/enclosure/step/mechanics/3d_printing/MP-02 middle.stp
136.6 x 201.5 x 26.8 mm

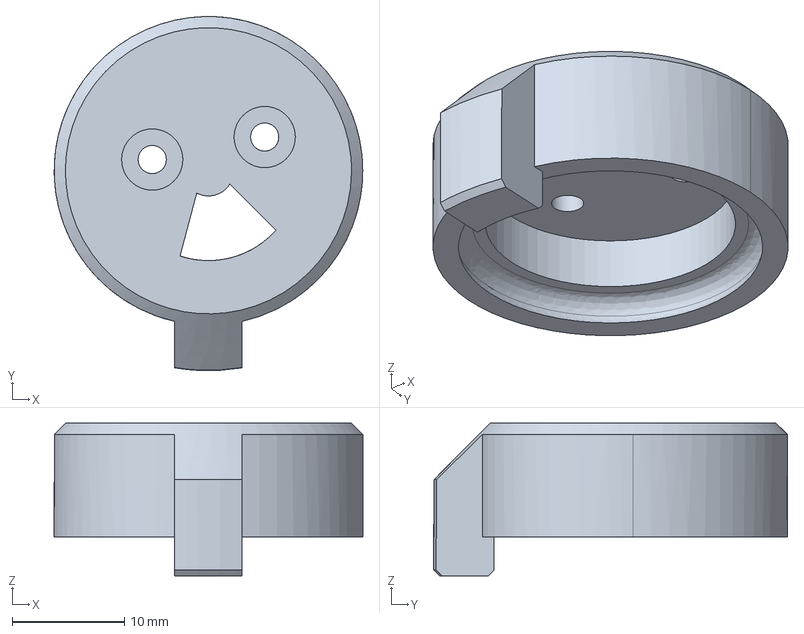
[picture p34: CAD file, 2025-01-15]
hardware/enclosure/step/mechanics/3d_printing/switch linear - FS22AXX/MP-04 switch_top.stp
27.4 x 31.5 x 13.6 mm

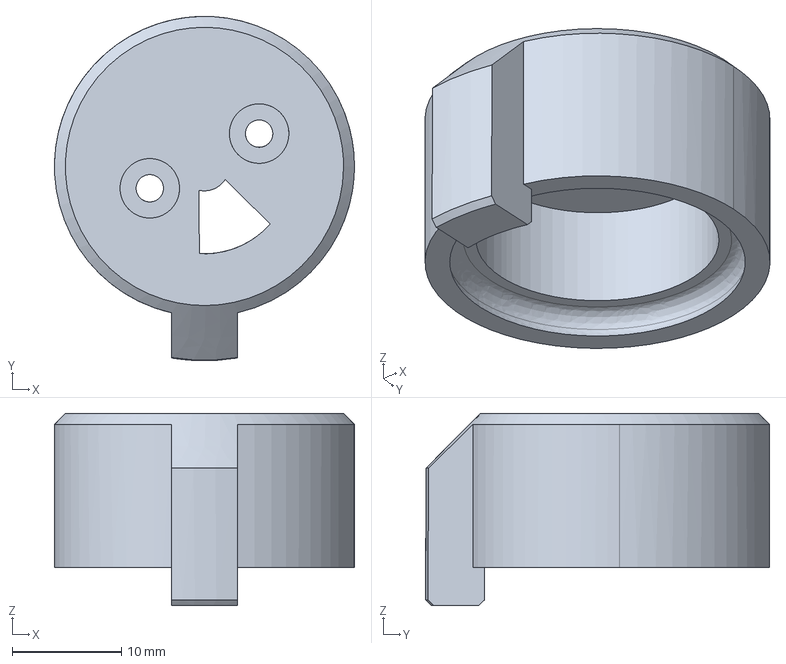
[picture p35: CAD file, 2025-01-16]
hardware/enclosure/step/mechanics/3d_printing/switch linear - SLW-135987-5A-N-D/MP-04 switch_top.stp
27.4 x 31.5 x 17.6 mm

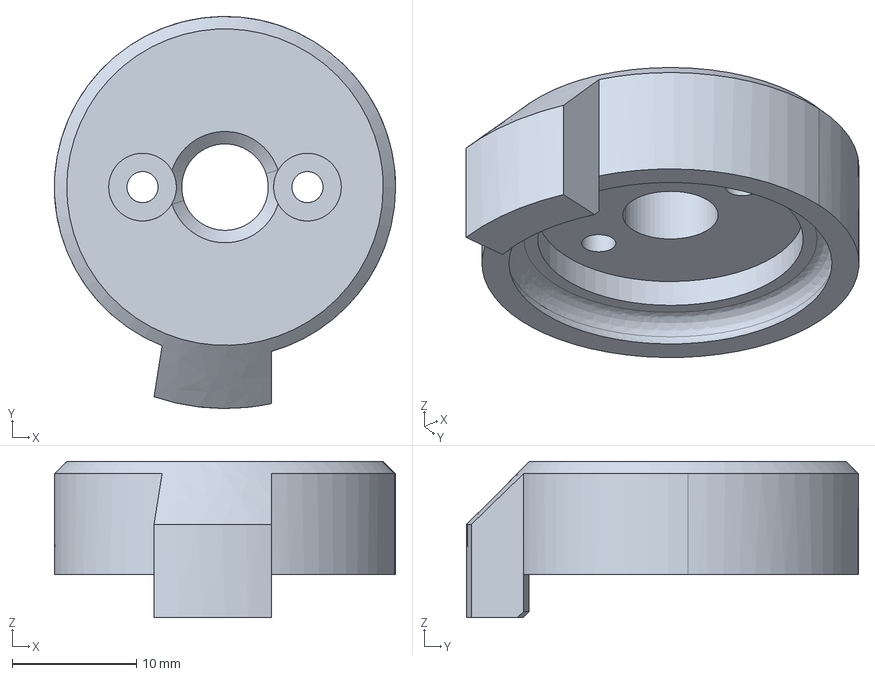
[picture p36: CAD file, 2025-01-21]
hardware/enclosure/step/mechanics/3d_printing/switch radial - R10307RN02Q/MP-04 switch_top.stp
27.4 x 31.5 x 12.6 mm

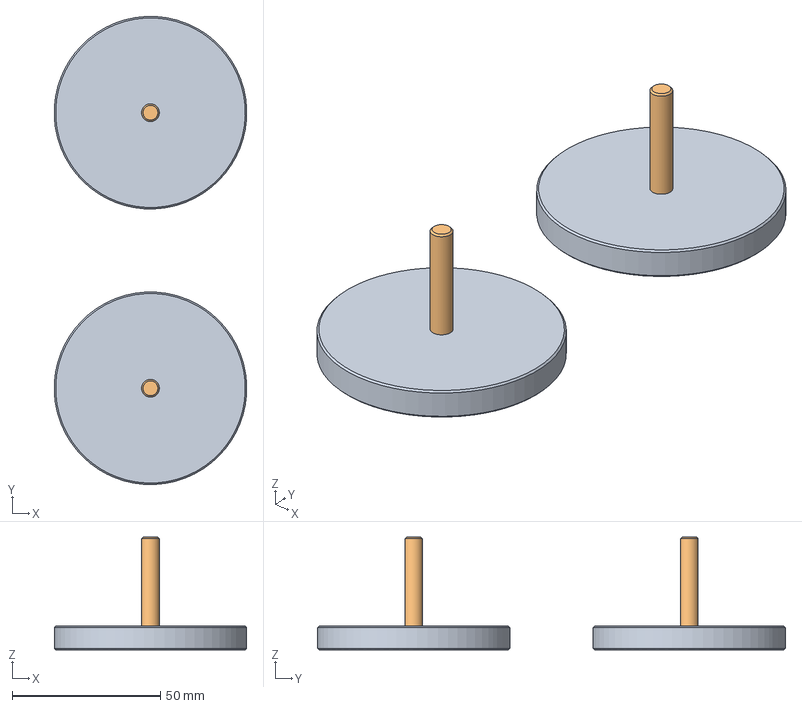
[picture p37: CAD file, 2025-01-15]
hardware/enclosure/step/mechanics/mounting/MM-01 magnet_1:4".stp
65.0 x 157.9 x 38.0 mm

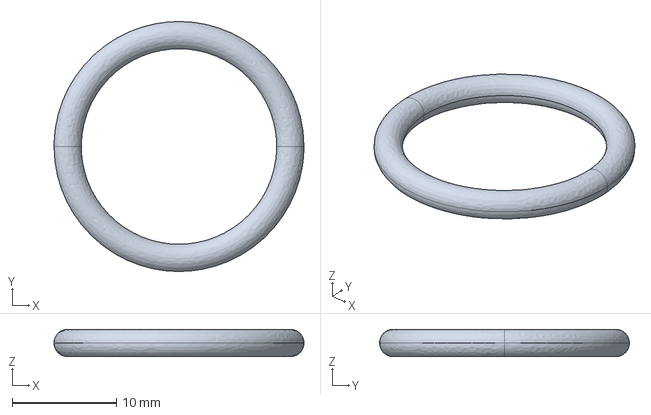
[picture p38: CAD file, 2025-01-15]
hardware/enclosure/step/mechanics/sealing/MS-01 oring.stp
24.0 x 24.0 x 2.62 mm

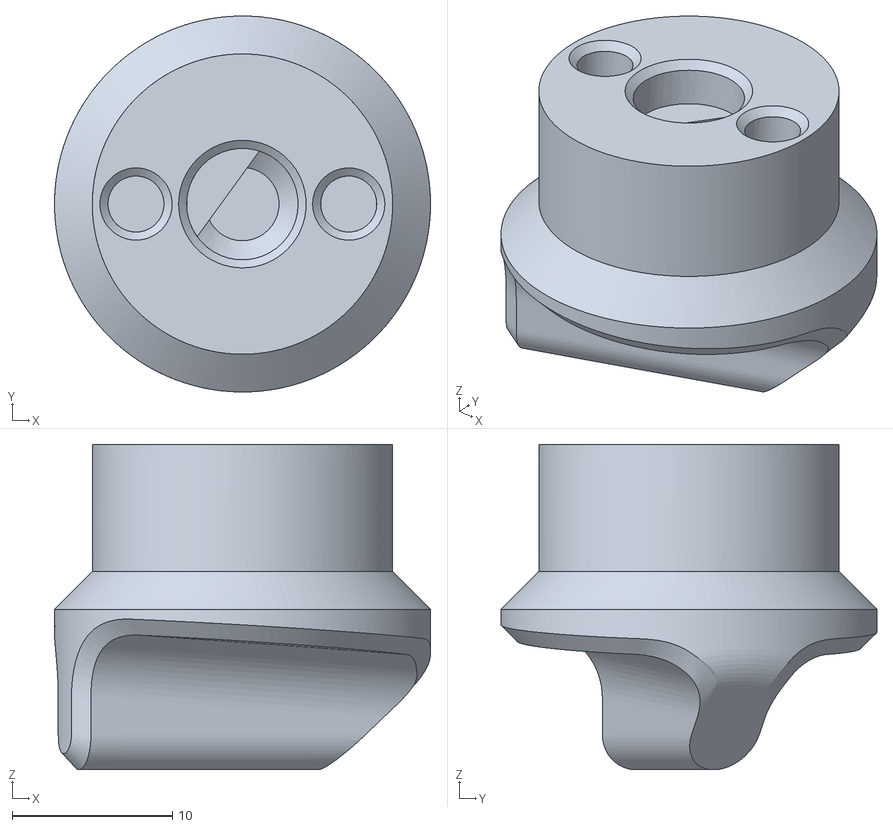
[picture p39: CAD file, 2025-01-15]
hardware/enclosure/stl/switch radial - R10307RN02Q/MP-05 switch_bottom.stl
23.4 x 23.4 x 20.3

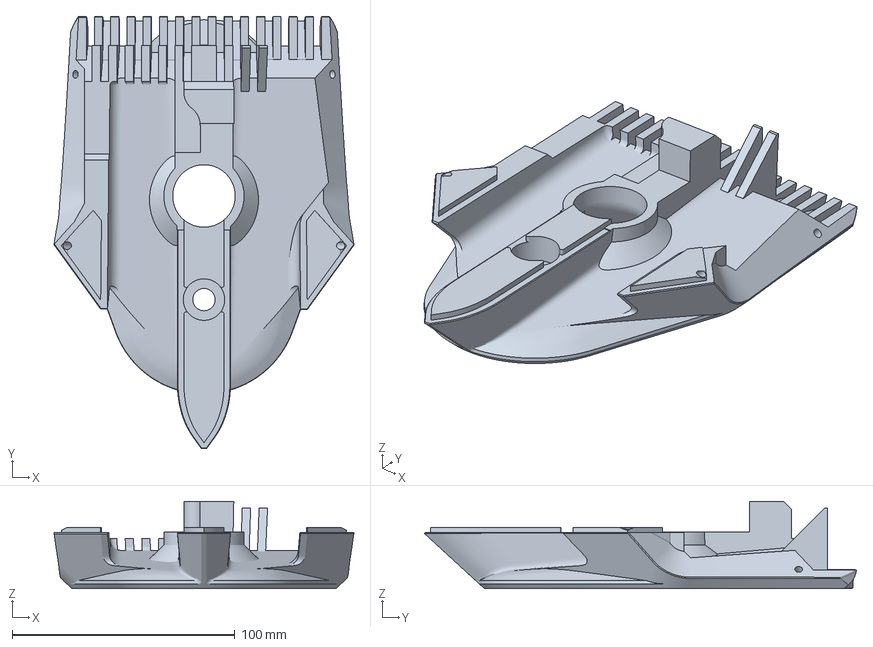
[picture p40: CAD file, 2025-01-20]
hardware/enclosure/bambu/bottom.3mf
134.5 x 193.8 x 39.2 mm

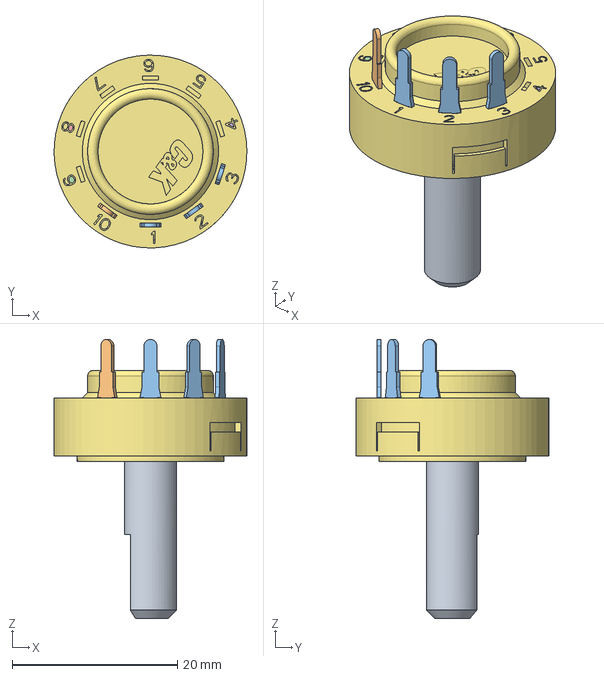
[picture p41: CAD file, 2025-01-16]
hardware/enclosure/step/electronics/switch radial - R10307RN02Q.stp
23.4 x 23.4 x 33.8 mm

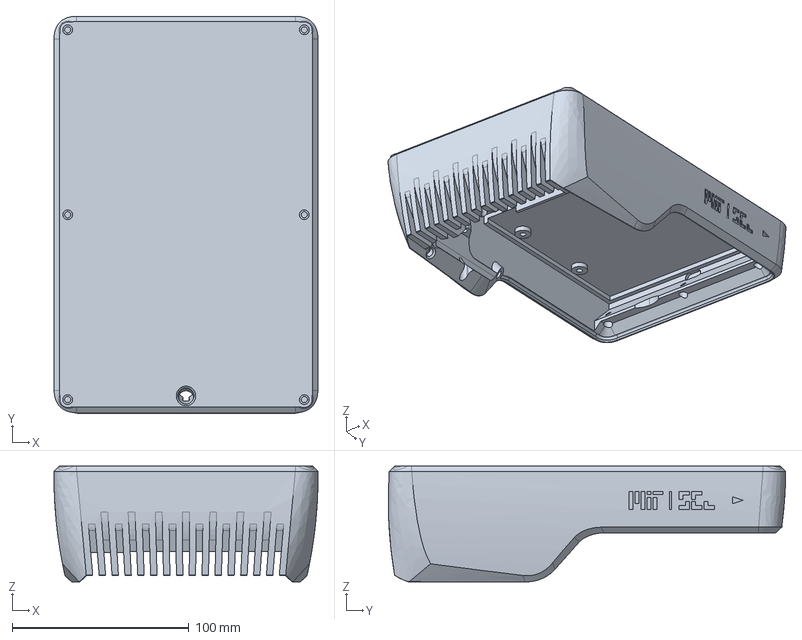
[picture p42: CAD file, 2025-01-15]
hardware/enclosure/step/mechanics/3d_printing/MP-01 top.stp
149.5 x 225.1 x 65.6 mm

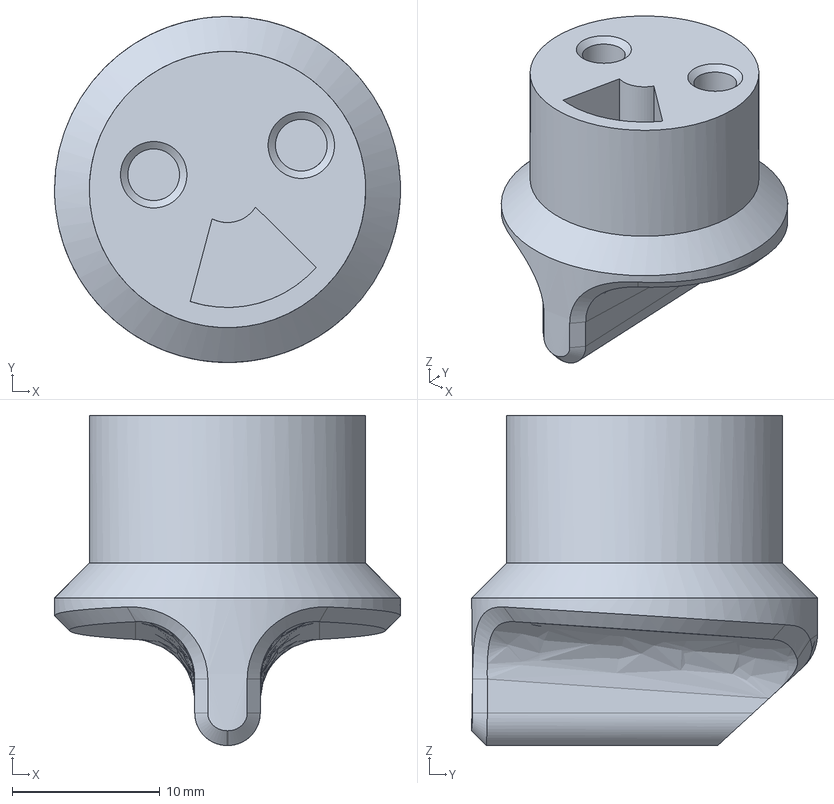
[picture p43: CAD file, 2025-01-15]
hardware/enclosure/step/mechanics/3d_printing/switch linear - FS22AXX/MP-05 switch_bottom.stp
23.4 x 23.4 x 22.4 mm

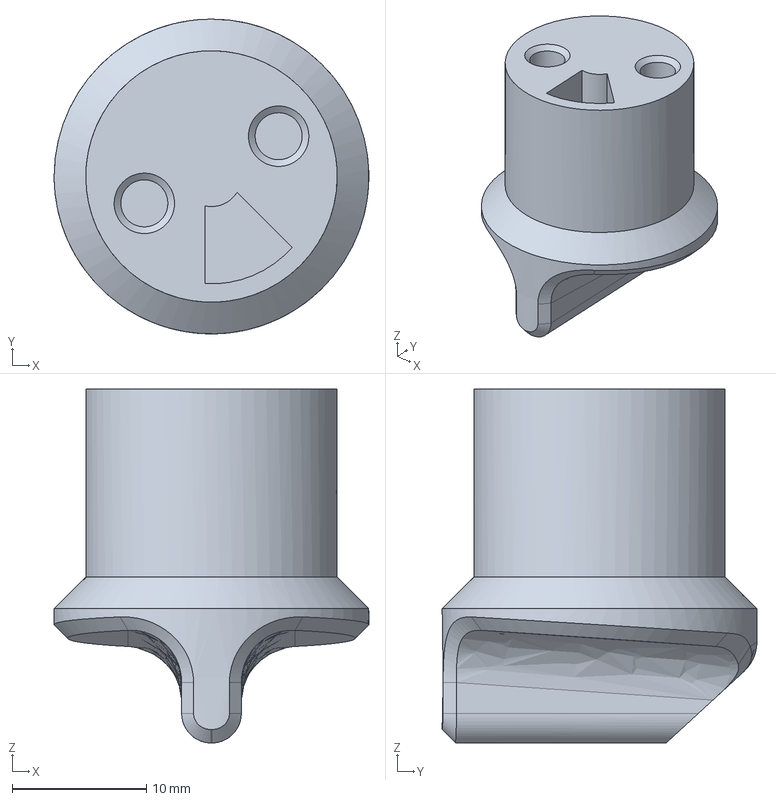
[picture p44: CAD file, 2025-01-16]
hardware/enclosure/step/mechanics/3d_printing/switch linear - SLW-135987-5A-N-D/MP-05 switch_bottom.stp
23.4 x 23.4 x 26.4 mm

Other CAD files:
hardware/enclosure/stl/MP-04 switch_top.stl
hardware/enclosure/stl/switch linear - SLW-135987-5A-N-D/MP-04 switch_top.stl
hardware/enclosure/step/mechanics/3d_printing/switch radial - R10307RN02Q/MP-05 switch_bottom.stp
hardware/enclosure/step/mechanics/sealing/MS-02 oring_cord.stp
hardware/enclosure/bambu/battery_holder.3mf
hardware/enclosure/bambu/middle.3mf
hardware/enclosure/bambu/switch_linear_FS22AXX.3mf
hardware/enclosure/bambu/switch_linear_SLW-135987-5A-N-D.3mf
hardware/enclosure/bambu/top.3mf
hardware/enclosure/step/electronics/EH-03 90deg_adapter_usb.stp
hardware/enclosure/step/electronics/EH-04 waterproof_usb.stp
hardware/enclosure/step/electronics/EP-01 battery.stp
hardware/enclosure/step/electronics/EP-02 solar_panel.stp
hardware/enclosure/step/electronics/ES-01 sensor_gas.stp
hardware/enclosure/step/electronics/ES-02 sensor_particulate.stp
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

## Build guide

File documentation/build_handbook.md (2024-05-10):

## Flatburn

# Assembly Guide

This assembly guide has step-by-step instructions on how to assemble a Flatburn. Look through the build section on our Github to gather all the required files for building the device. Follow the instructions in this guide (and feel free to customize the device and sensors as you see fit). We hope you have fun assembling your own Flatburn and collecting data about your environment!

# What you need to get started
- 3D printed and laser-cut parts,
- Fasteners and tools as specified in the [bill of materials](https://docs.google.com/spreadsheets/d/1-UVIJEneydIf8kLRng4QxvzjM4k2ZoDa/edit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)



# Assembly instructions
1. Slot together two halves of the core module

   

2. Use super-glue to secure the o-rings in the core module (solar-panel recess and base-plate recess) and to the top of the sensor module.

 



1. Using a soldering iron, add screw inserts to the core module and to the magnet-feet holders; small (M3) and large (¼ “) inserts respectively

  



2. Clip ‘in-between plate’ into core module. Feed solar panel cable through slot.

         

3. Screw solar panel onto the core module

  

4. Slide the main PCB into the back of the core module; secure with 3D printed clamps.

  

5. Slide battery into front of the core module

  

6. Connect solar panel and battery to the main PCB
   
  

7. Clip the magnet-feet holders into the base-plate
   


8. Feed the sensor-connector-cable through the slot in the base-plate and then secure the plate to the core module\



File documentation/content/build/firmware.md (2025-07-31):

---
sidebar_position: 7
---

# 💻 Firmware

## Environment

- Code developed using [Particle.io plugin for MS Code](https://www.particle.io/workbench/);
- Devices can be flashed both via cable or cloud flash (data costs);
- Currently testing on bsom [Particle deviceOS@6.1.1](https://docs.particle.io/reference/device-os/firmware);
- Written in C++ and [Particle deviceOS APIs](https://docs.particle.io/reference/device-os/firmware/);

## Dev Environment Setup

1. Clone [this](https://github.com/MIT-Senseable-City-Lab/flatburn-lte/) repository;
2. Open Particle Workbench;
3. Run the `Particle: Import Project` command, follow the prompts, and wait for the project to load;
4. Run the `Particle: Configure Workspace for Device` command and select a compatible Device OS version and the `bsom` platform when prompted ([docs](https://docs.particle.io/tutorials/developer-tools/workbench/#cloud-build-and-flash));
5. Connect your device;
6. Compile & Flash!

## Main Firmware Functionalities
- Cityscanner: Handles operation modes;
- CitySense: Collects environmental data (payload);
- CityVitals: Collects telemetry/status (vitals);
- CityStore: Handles SD card and USB data storage/transfer;
- MotionService: Puts device to sleep when vehicle is not moving;
- LocationService: Provides GPS data;

## Block Diagram
```mermaid
flowchart LR

    subgraph Device [Flatburn]
        config[cityscanner_config]
        entry[main]
        scan[cityscanner]
        sense[CitySense]
        vitals[CityVitals]
        store[CityStore]
        motion[MotionService]
        location[LocationService]
        config --> entry
        entry --> scan
        scan --> sense
        scan --> vitals
        scan --> store
        scan --> motion
        scan --> location
    end

    subgraph OperationModes [Operation Modes]
        idle[IDLE]
        realtime[REALTIME]
        logging[LOGGING]
        pwrsave[PWRSAVE]
        scan --> idle
        scan --> realtime
        scan --> logging
        scan --> pwrsave
    end

    subgraph DataFlow [Data Flow]
        payload[Payload]
        vitalsData[Vitals]
        sense --> payload
        vitals --> vitalsData
        location --> payload
        location --> vitalsData
        payload --> store
        vitalsData --> store
    end

    motion --> scan
    store --> sd[SD Card/USB]
```

## Operation modes

- _IDLE_ sensors off, provides only telemetry data;
- _REALTIME_ logs data onto the SD card and send it in real time (via Particle publish);
- _LOGGING_ buffer data onto the SD card and send multiple records upon request (via USB);
- _PWRSAVE_ ike LOGGING but in low power mode.

### Payload

| # | Element | Type | Purpose | Source |
|---|---|---|---|---|
| 0 | deviceID | identifier  | Unique device identifier from particle | Partile module |
| 1 | timestamp | temporal | UTC time of measurement | GPStime in Epoch |
| 2 | latitude | spatial | Latitude (decimal degrees) | GPS module |
| 3 | longitude | spatial | Longitude (decimal degrees) | GPS module |
| 4 | PM1.0 | atmospheric | Particulated Matter (1 μm) | Sensirion SPS30 |
| 5 | PM2.5 | atmospheric | Particulated Matter (2.5 μm) | Sensirion SPS30 |
| 6 | PM4 | atmospheric | Particulated Matter (4 μm) | Sensirion SPS30 |
| 7 | PM10 | atmospheric | Particulated Matter (10 μm) | Sensirion SPS30 |
| 8 | numPM0.5 | atmospheric | Particle count (0.5 μm) | Sensirion SPS30 |
| 9 | numPM1 | atmospheric | Particle count (1 μm) | Sensirion SPS30 |
| 10| numPM2.5 | atmospheric | Particle count (2.5 μm) | Sensirion SPS30 |
| 11| numPM4 | atmospheric | Particle count (4 μm) | Sensirion SPS30 |
| 12| numPM10 | atmospheric | Particle count (10 μm) | Sensirion SPS30 |
| 13| PM size | atmospheric | Average particle size | Sensirion SPS30 |
| 14| temperature | atmospheric | Ambient air temperature (°C) | BME280 |
| 15| humidity | atmospheric | Ambient relative humidity (%) | BME280 |
| 16| gas_op1_w | air quality | Gas sensor 1 (write pin) | Alphasense AFE |
| 17| gas_op1_r | air quality | Gas sensor 1 (read pin) | Alphasense AFE |
| 18| gas_op2_w | air quality | Gas sensor 2 (write pin) | Alphasense AFE |
| 19| gas_op2_r | air quality | Gas sensor 2 (read pin) | Alphasense AFE |
| 20| noise | sound | Environmental noise in (dB) | Alphasense AFE |

---

### Vitals

| # | Element | Type | Purpose | Source |
|---|---|---|---|---|
| 0 | deviceID | identifier | Unique device identifier from particle | Particle module |
| 1 | timestamp | temporal | UTC time of measurement | GPStime in Epoch |
| 2 | latitude | spatial | Latitude (decimal degrees) | GPS module |
| 3 | longitude | spatial | Longitude (decimal degrees) | GPS module |
| 4 | voltage_batt | electrical | Battery voltage (V) | Battery IC |
| 5 | current_batt | electrical | Battery current (mA) | Battery IC |
| 6 | isCharging | status | Charging status (boolean) | Firmware |
| 7 | isCharginS | status | Secondary charging status (boolean) | Firmware |
| 8 | isCharged | status | Battery fully charged | Firmware |
|11 | voltage_solar | electrical | Solar panel voltage (V) | Solar |
|12 | current_solar | electrical | Solar panel current (mA) | Solar |
|13 | cell_strength | signal | Cellular network signal strength | Cellular RSSI |

# Command line interface

A Python script provides a command line interface (CLI) for retrieving data over USB. To use it, follow the step-by-step instructions in the [data retrieval guide](https://mit-senseable-city-lab.github.io/flatburn-lte/deploy/data)

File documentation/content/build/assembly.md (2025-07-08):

---
sidebar_position: 6 
---

# 🧩 Assembly

:::info
It is highly recommended that you read this entire assembly manual to familiarize yourself before starting!
:::

## Overview

The assembly process consists of **14 easy steps**, which should take up to **60 minutes** per device.

The device was designed for not needing wire soldering, glueing or any other complex operation.

You will be installing brass inserts into plastic, placing parts together, connecting cables and fastening screws.

## Safety

:::danger

1. Be aware of the soldering iron tip and hot parts to **avoid burning** yourself and the 3d printed parts.
2. The metal inserts will keep **hot for a while** after inserting, especially the bigger 1/4" ones.
   :::

## Step 1 – Setup and Preparation

1. Make sure there is enough space and lighting;
3. Have all parts and components accessible on bench, placing the smallest ones on "buckets" to avoid losing them;
2. Leave the center of the bench for where the actual work is going to be, and the perimeter for tools and other parts;
4. Keep dangerous tools such as the soldering station away from where you could accidentaly hit it by mistake.
5. Print all 3D printed parts - you can consult the [**materials**](mechanics) for printer settings and files. 

:::info
Meanwhile, you can always consult the [**overview reference**](overview), [**bill of materials**](bom) and [**suggested tools**](tools) throughout the process.
:::

<!-- ## Step 2 – Remove Printed Supports

Remove the support on _middle_ piece:
![alt text](../../static/files/assembly/DSC_5172.jpg)

Remove the support on _camera_ piece:
![alt text](../../static/files/assembly/DSC_5171.jpg) -->

## Step 2 – M2 Inserts

:::tip

- It is easy to misplace the inserts, pay attention to the **indicated spots** on the images.
- The **larger holes** are meant for the **1/4" inserts**, the **medium for M3** and **smaller for M2** - the documentation will indicate where to put each specific insert size. 
- After the inserts are melted into the plastic they **cannot be easily removed** without damaging the 3d printed part.
- If in doubt, think twice and check the instructions!
  :::

Start by picking-up all the thirteen M2 inserts
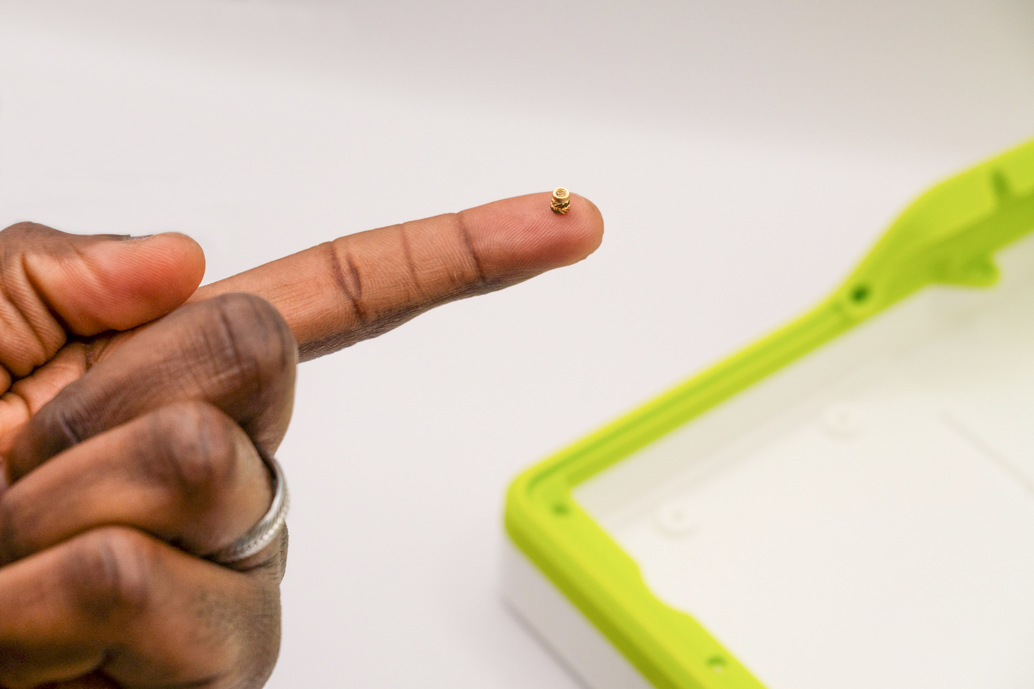
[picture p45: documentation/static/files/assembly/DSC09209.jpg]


Of which, place eight M2 inserts on _top_:
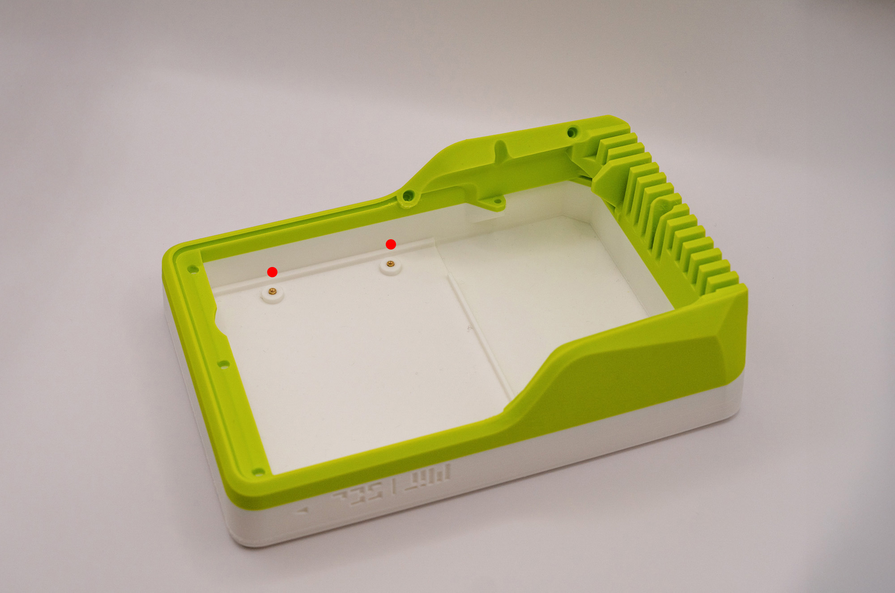
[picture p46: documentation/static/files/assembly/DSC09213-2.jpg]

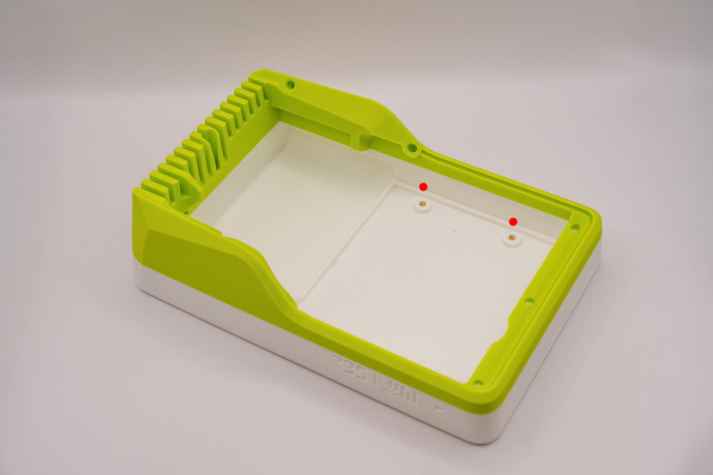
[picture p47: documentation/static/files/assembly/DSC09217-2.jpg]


<!-- Then, place four M2 inserts on _camera_:
![alt text](../../static/files/assembly/DSC_5181.jpg)

Finally, place the last M2 insert on _switch_bottom_:
![alt text](../../static/files/assembly/DSC_5182.jpg) -->

Set the soldering iron to 300ºC, wait for it to reach the temperature, then slowly press the soldering tip perpendicularly (avoid twisting) to the inserts until all them are flush with the printed surfaces:
<!-- ![alt text](../../static/files/assembly/DSC_5187.jpg)
![alt text](../../static/files/assembly/DSC_5188.jpg) 

![alt text](../../static/files/assembly/DSC_5194.jpg) -->
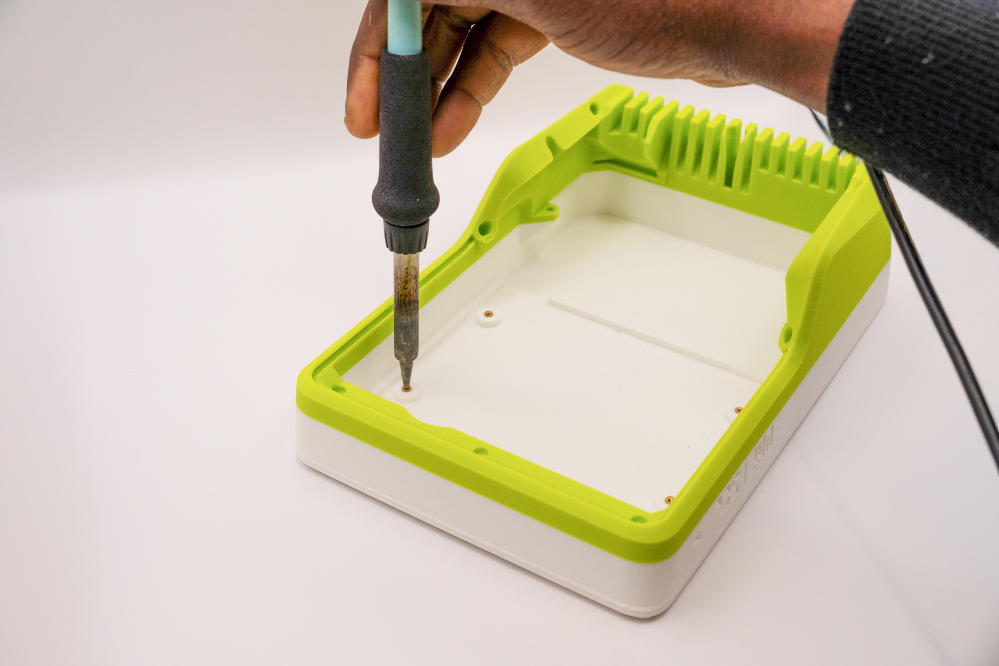
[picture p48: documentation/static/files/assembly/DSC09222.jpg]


In the end, this should be the result:

<!-- **✅ _switch_bottom_**
![alt text](../../static/files/assembly/DSC_5192.jpg)

**✅ _camera_**
![alt text](../../static/files/assembly/DSC_5193.jpg) -->

**✅ _top_**
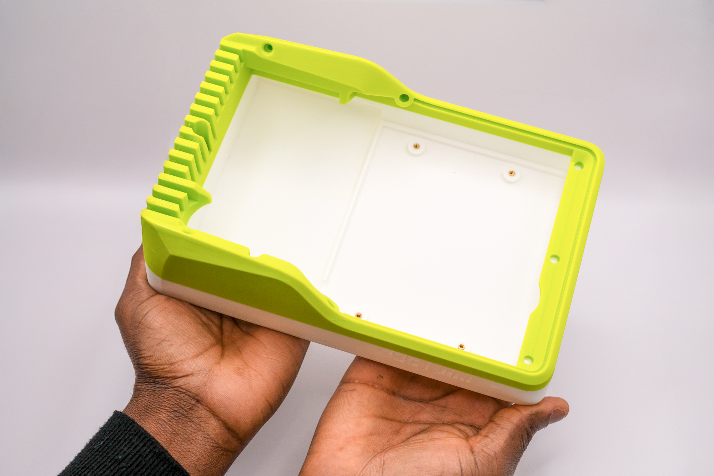
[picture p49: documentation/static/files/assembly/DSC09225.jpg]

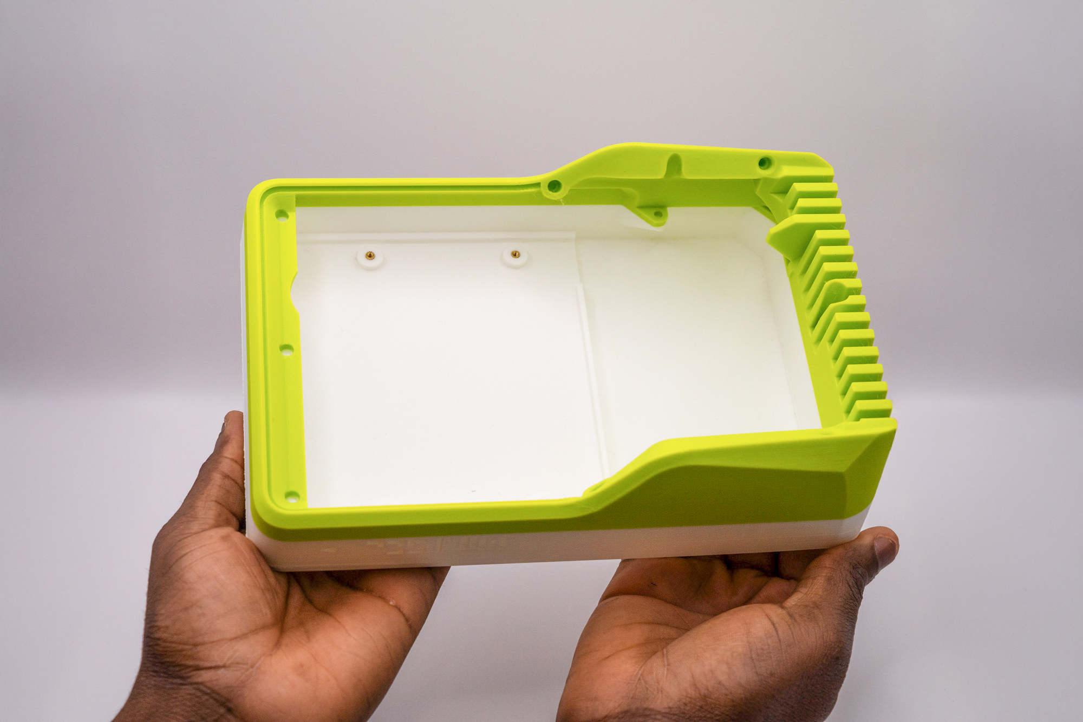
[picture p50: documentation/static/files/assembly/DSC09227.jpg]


## Step 3 – M3 Inserts

Pick-up thirteen M3 inserts, turn the _top_ piece around, then place six M3 inserts on it:
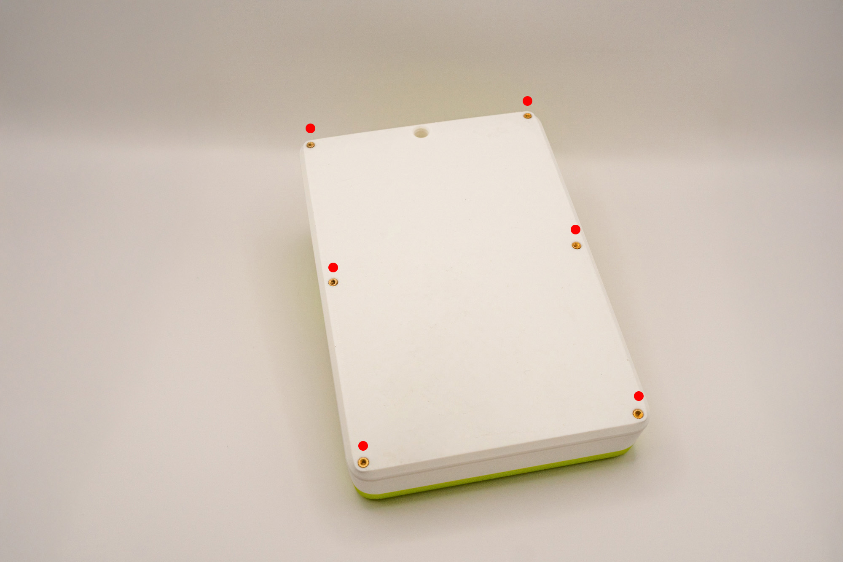
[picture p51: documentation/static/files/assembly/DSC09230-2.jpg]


<!-- ![alt text](../../static/files/assembly/DSC_5205.jpg) -->

Then, install the six inserts with the soldering iron, turn the _top_ piece back and place the remaining eight M3 inserts on the other side:
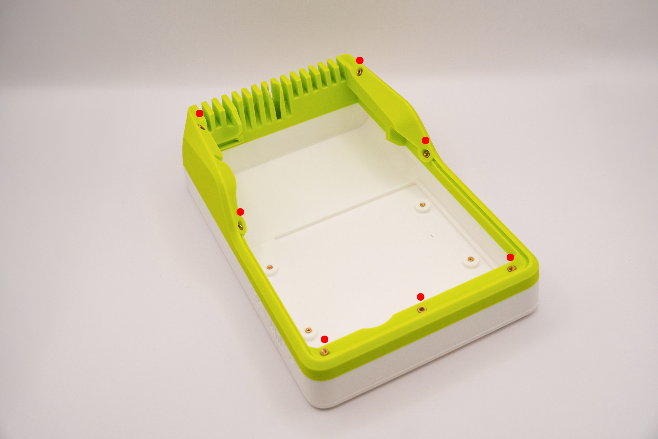
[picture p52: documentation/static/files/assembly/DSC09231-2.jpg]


Pay attention to the appropriate angle, respecting the holes' directions and the surface alignment:
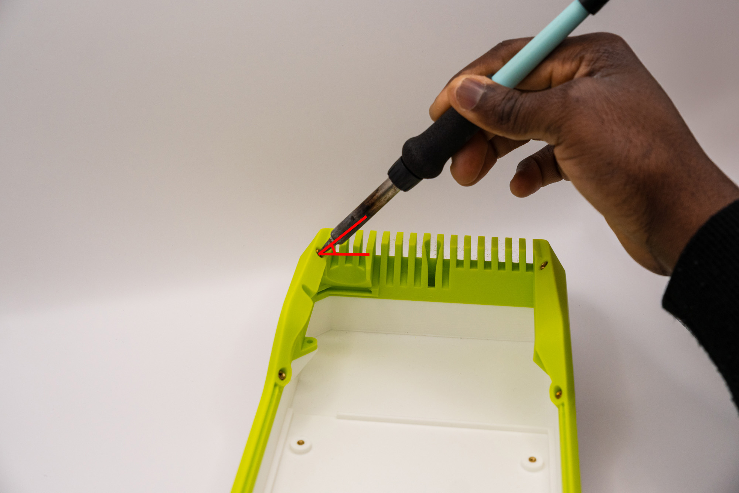
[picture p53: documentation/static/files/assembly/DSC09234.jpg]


## Step 4 – 1/4" Inserts

Place a ¼" insert on the designated spot on _middle_ piece:
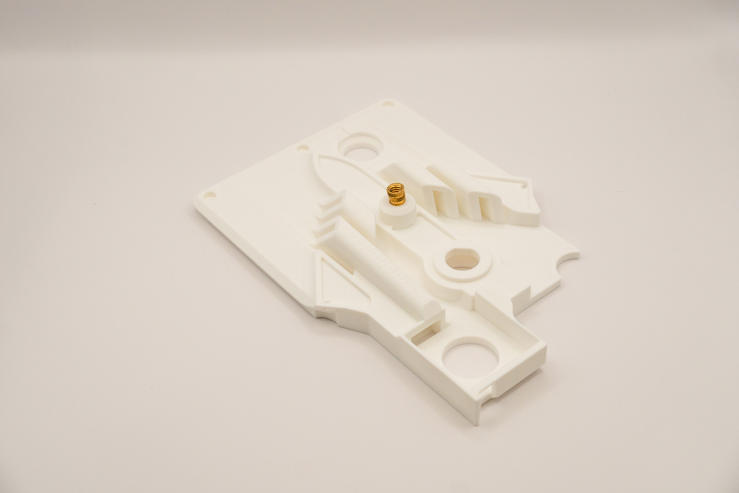
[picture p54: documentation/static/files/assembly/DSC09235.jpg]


<!-- ![alt text](../../static/files/assembly/DSC_5207.jpg) -->

:::tip
Be careful, these bigger inserts take longer to heat and to cool down.
:::

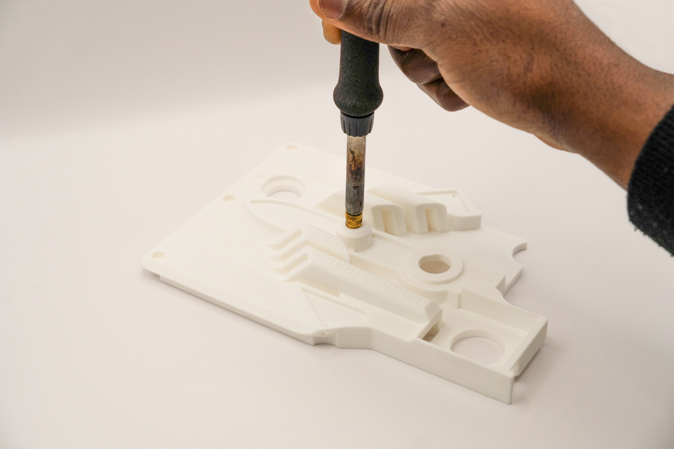
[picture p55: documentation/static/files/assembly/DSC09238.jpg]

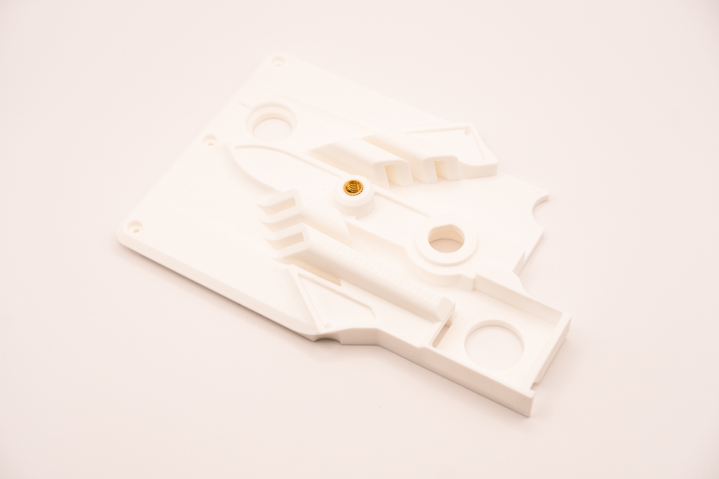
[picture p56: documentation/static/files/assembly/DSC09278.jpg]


Then, place the other ¼" insert on the rear spot of the _bottom_ piece:
:::warning
Be careful to not place the insert in the wrong spot
:::
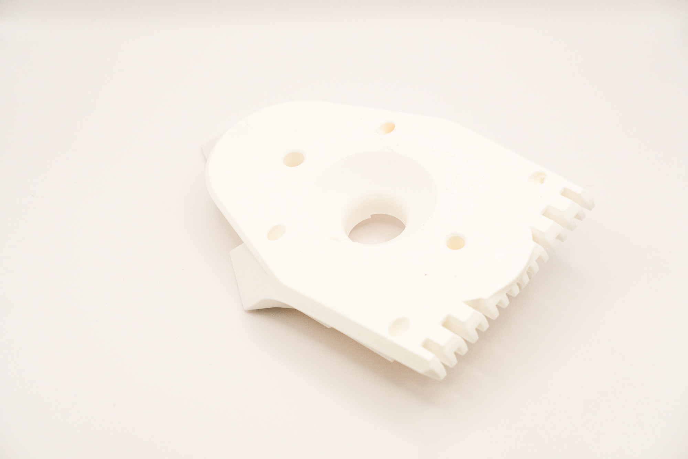
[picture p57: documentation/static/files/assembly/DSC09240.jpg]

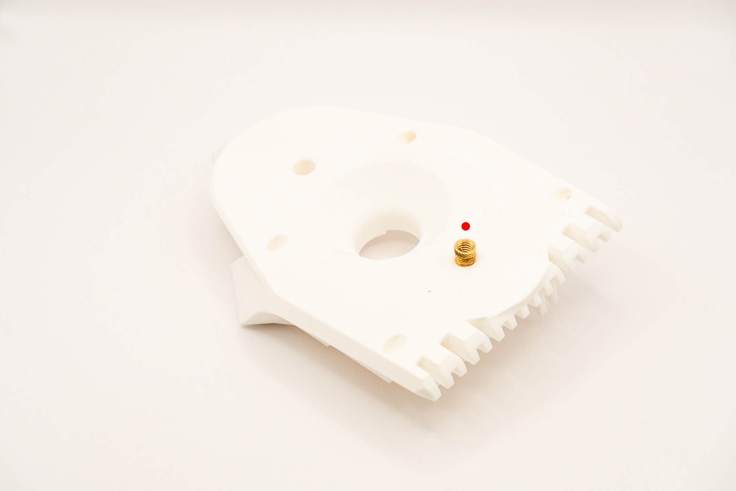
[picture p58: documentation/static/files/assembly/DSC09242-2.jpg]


<!-- ![alt text](../../static/files/assembly/DSC_5211.jpg) -->

**✅ Result**
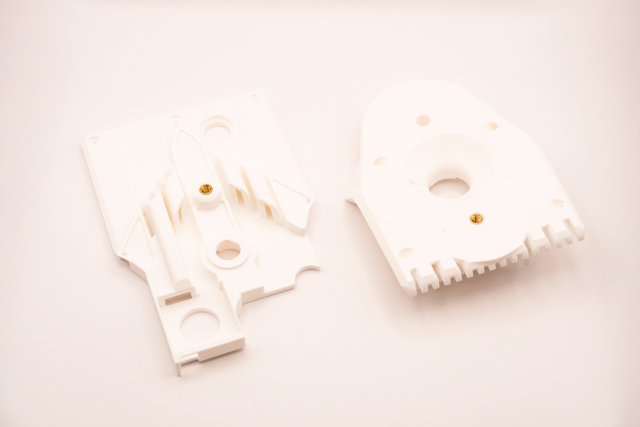
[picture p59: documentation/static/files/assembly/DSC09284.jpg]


## Step 5 – O-Ring Cord

Pick the O-ring cord and unroll it:
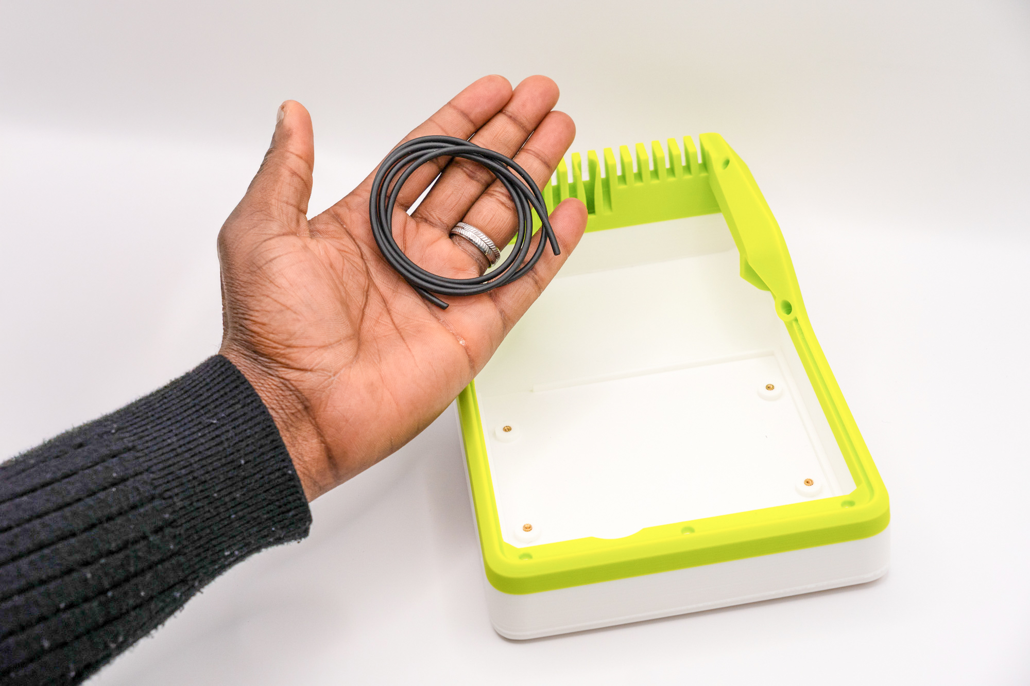
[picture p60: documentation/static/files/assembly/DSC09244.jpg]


Align the tip of the cord to the recess on the _top_ piece, then gently press it perpendicularly to fit inside:
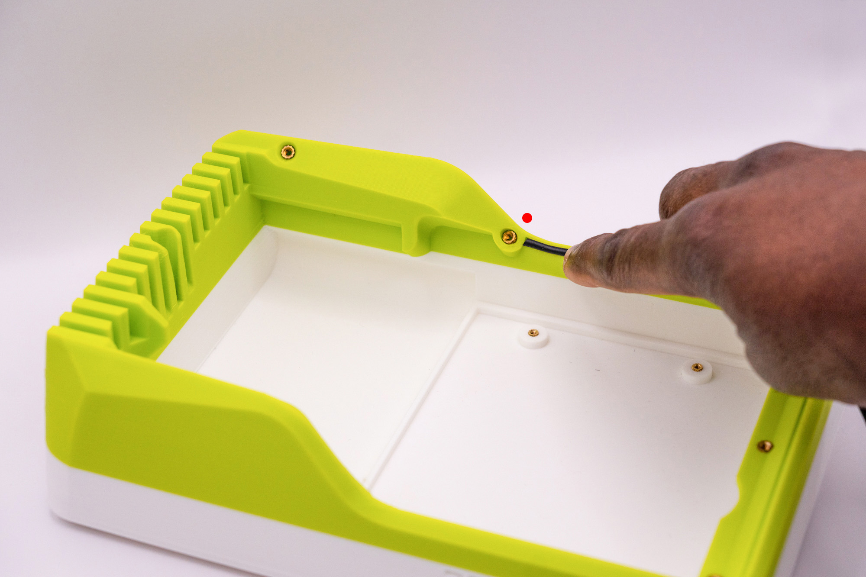
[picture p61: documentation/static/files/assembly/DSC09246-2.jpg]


Without stretching, keep pressing until reaching the other extremity of the recess:
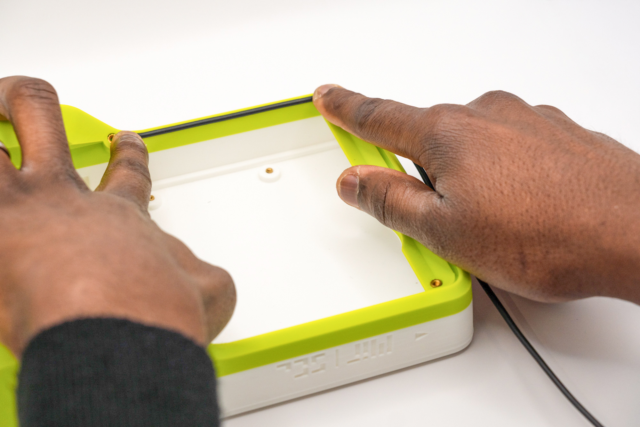
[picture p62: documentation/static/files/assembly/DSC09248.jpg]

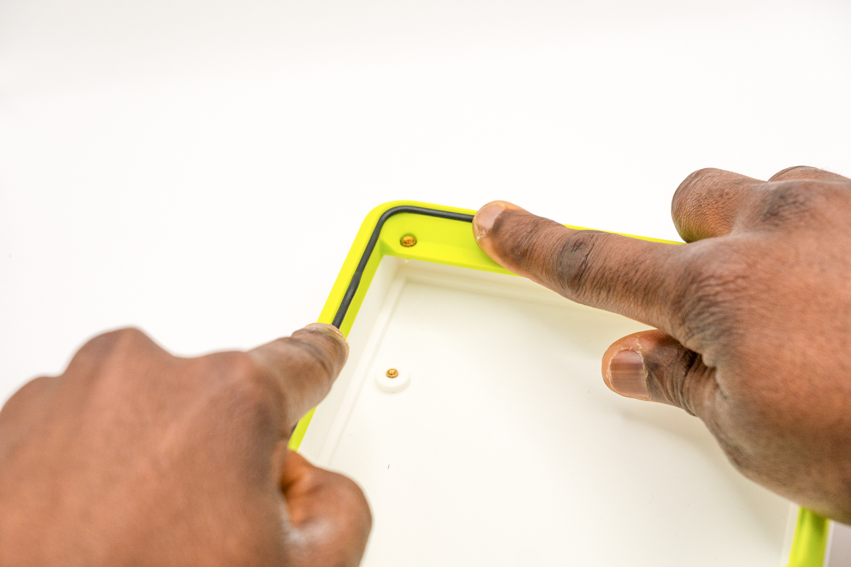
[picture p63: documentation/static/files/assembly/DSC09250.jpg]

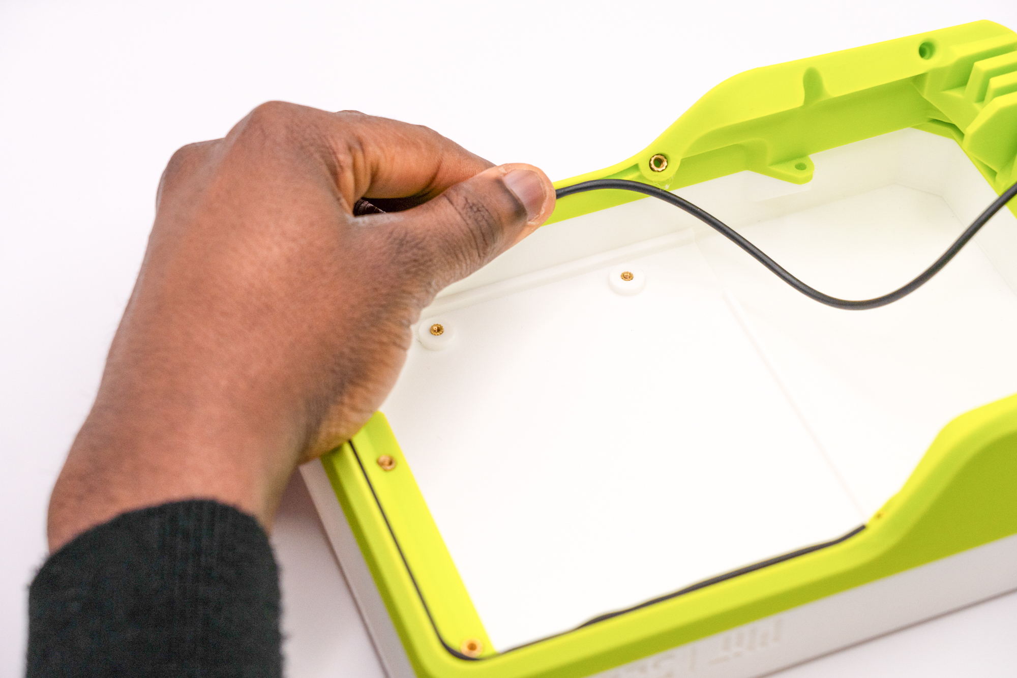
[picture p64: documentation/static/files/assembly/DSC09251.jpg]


Cut the cord to match the extremity, and push it to finish:
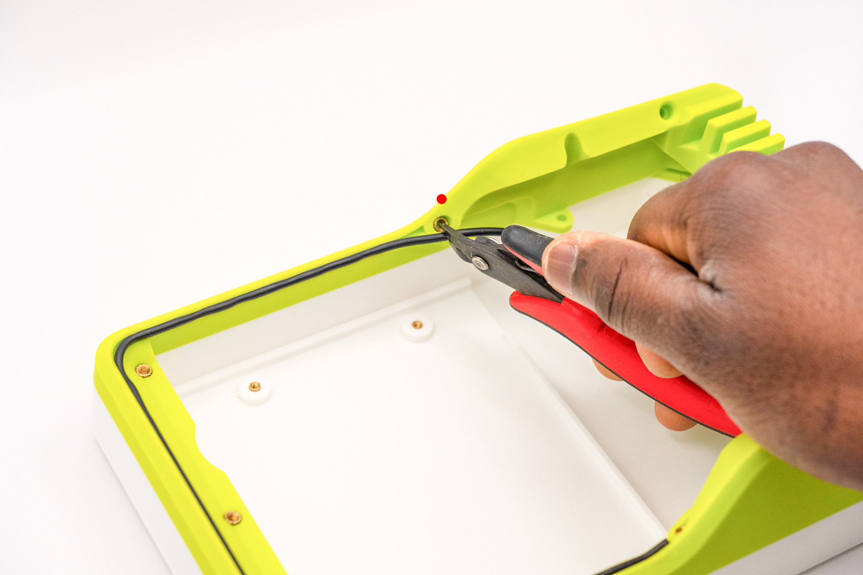
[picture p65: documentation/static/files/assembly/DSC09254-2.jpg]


**✅ Result**
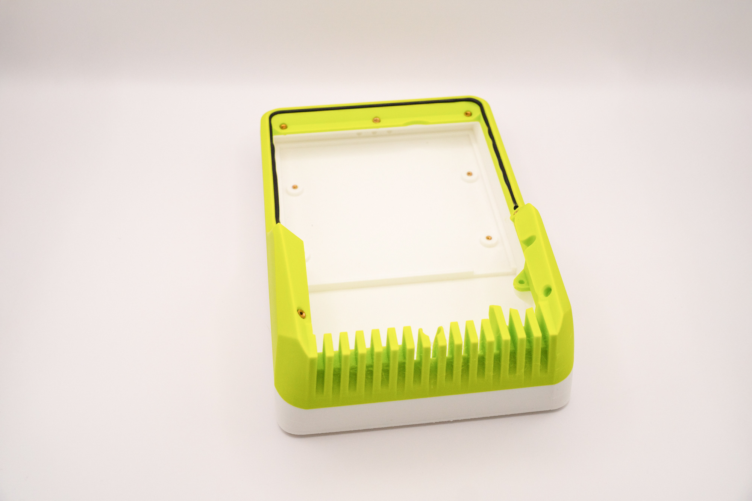
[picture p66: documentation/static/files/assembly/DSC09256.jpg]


## Step 6 – Populate Main Board

:::info
Remember to choose the type of Particle module (EMEA or US) according to where the device will be deployed.
:::

Insert the Particle module into the Main Board slot with its branding facing up:
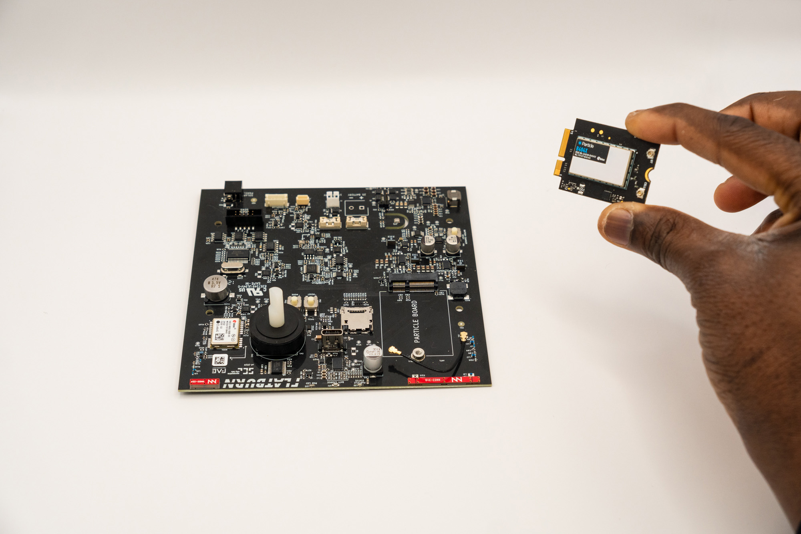
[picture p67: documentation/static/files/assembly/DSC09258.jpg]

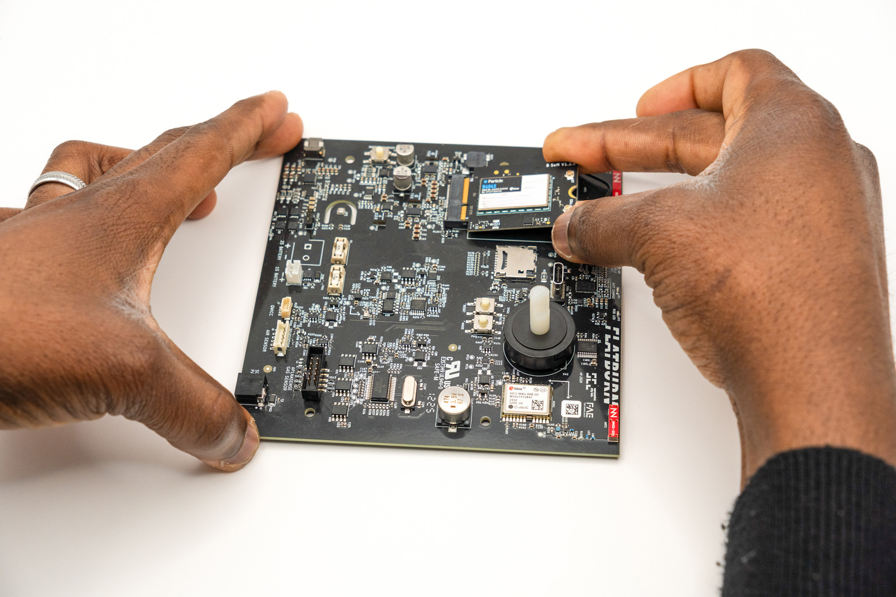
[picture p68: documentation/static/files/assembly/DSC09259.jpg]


Fasten a M2.5x4 screw with a washer and bolt into the Main Board to secure the module:
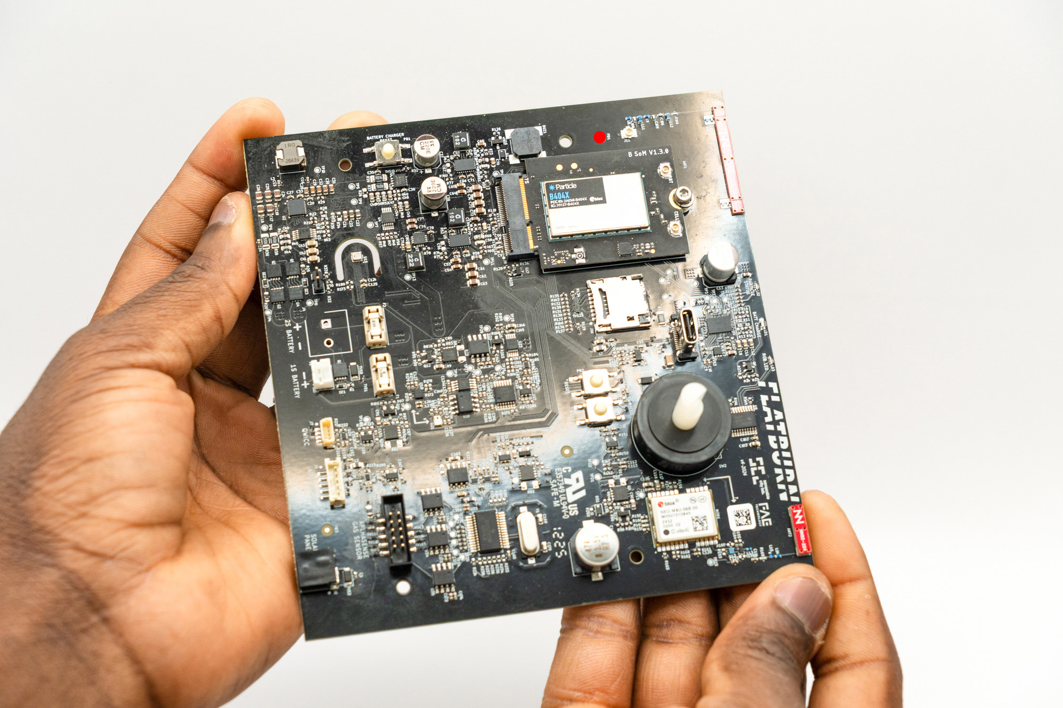
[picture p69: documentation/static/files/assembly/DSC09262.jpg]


<!-- ![alt text](../../static/files/assembly/DSC_5228.jpg) -->

Now, pick the GSM antenna cable and connect it between the Particle module and the Main Board:
:::tip

1. Depending on the Particle module type, the antenna connector will be in different place (always signed with a **_CELL_** label).
2. It can be tricky to snap the connector on. If needed, use a plier with care to not damage the connector and boards, pressing the connector from its front face, but **never press from the sides** because that will damage the connector.
   :::
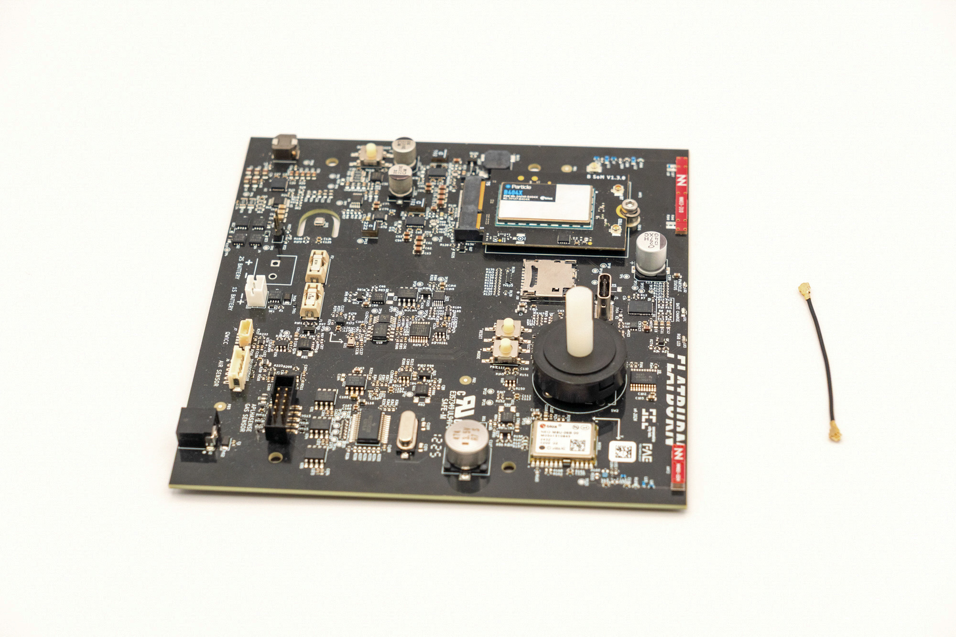
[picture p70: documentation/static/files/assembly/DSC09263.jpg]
   
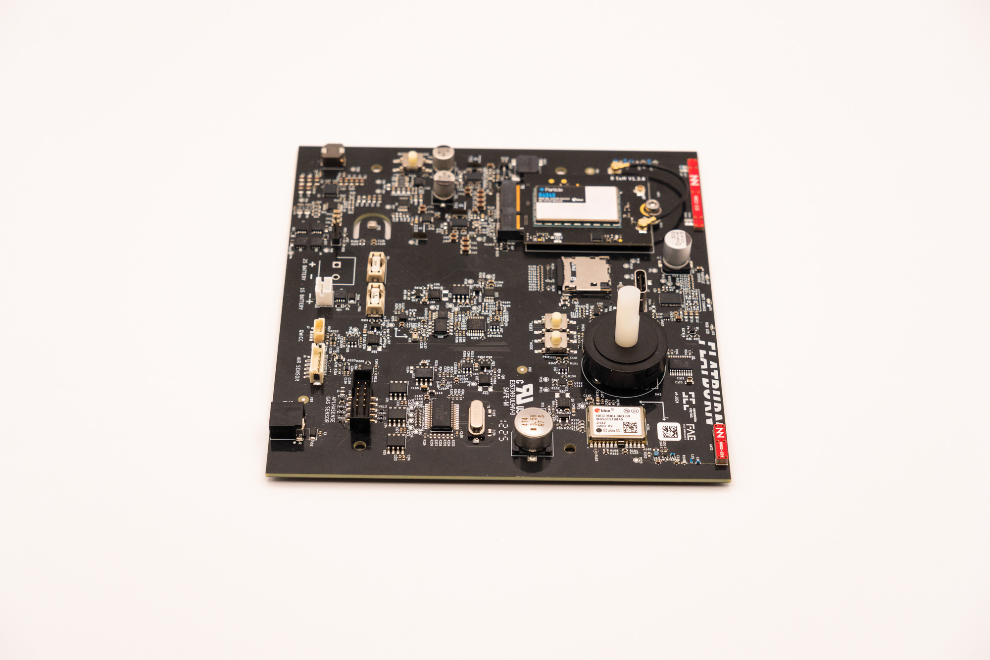
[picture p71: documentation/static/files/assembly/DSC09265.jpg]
   

To finish, add the microSD card to the Main Board slot:
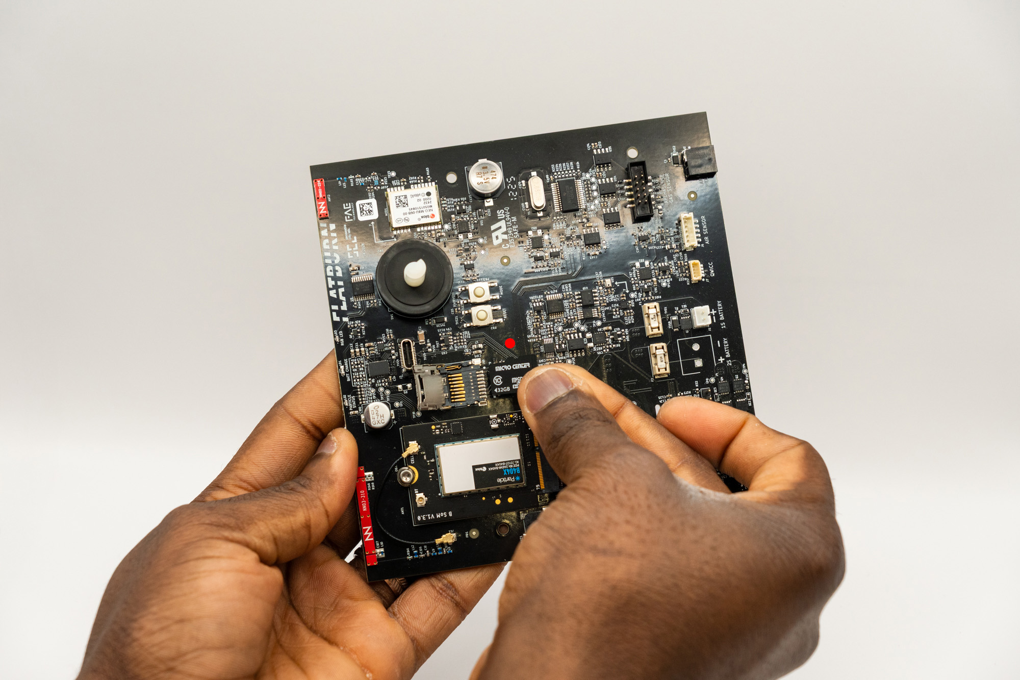
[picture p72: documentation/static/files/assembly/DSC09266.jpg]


**✅ Result**
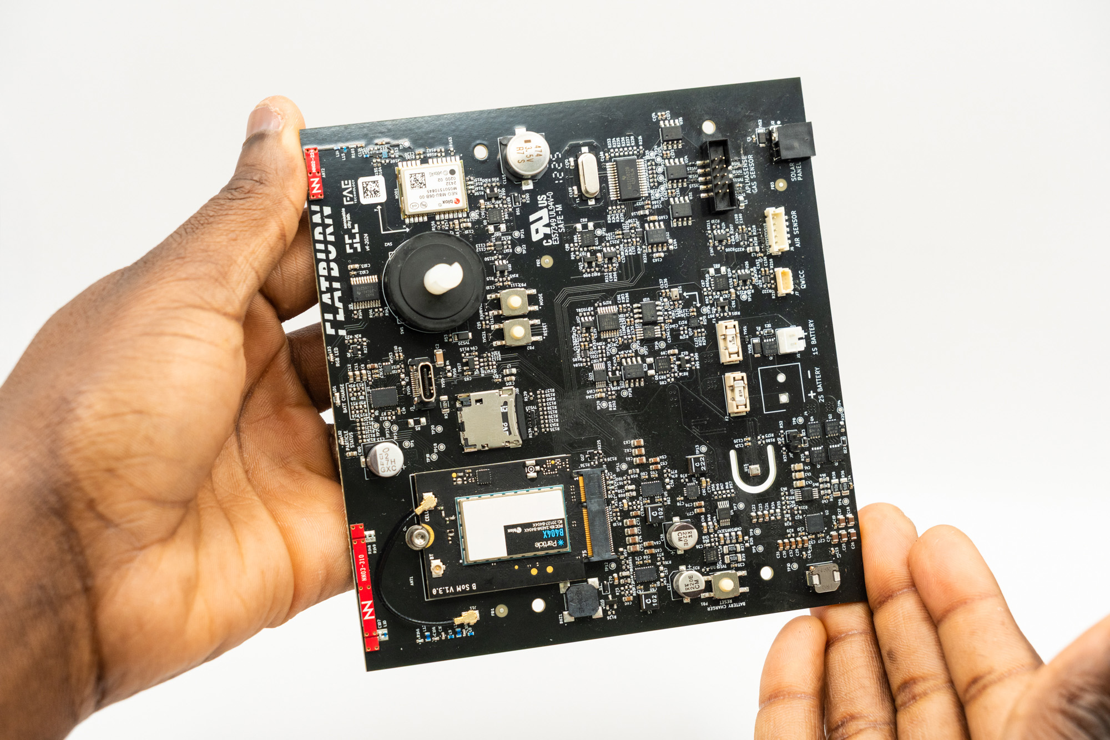
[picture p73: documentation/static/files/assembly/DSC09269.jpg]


## Step 7 – Battery and Main Board
To insert the Main Board into the _top_ piece, first place its front edge against the _top_ piece at an angle:
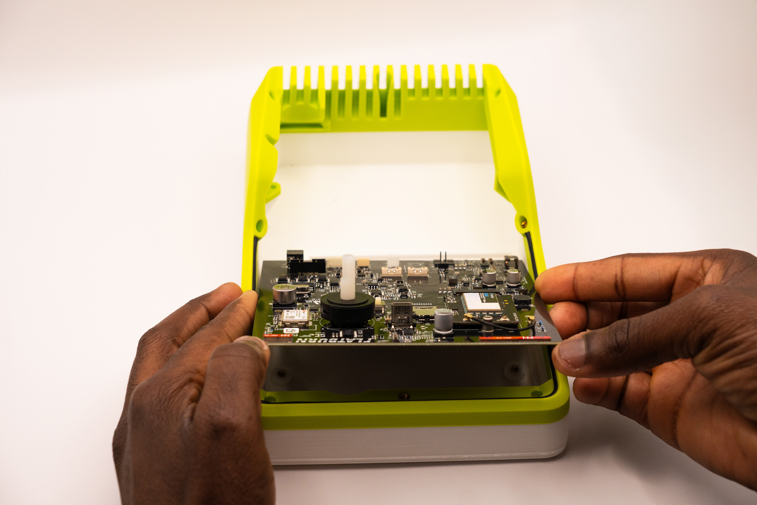
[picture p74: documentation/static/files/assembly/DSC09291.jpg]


Finally, lower and then slide it back:
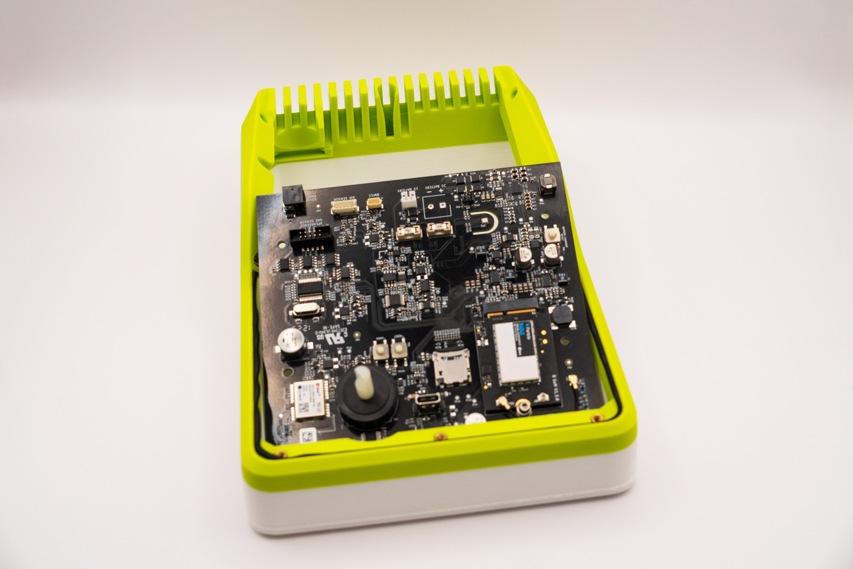
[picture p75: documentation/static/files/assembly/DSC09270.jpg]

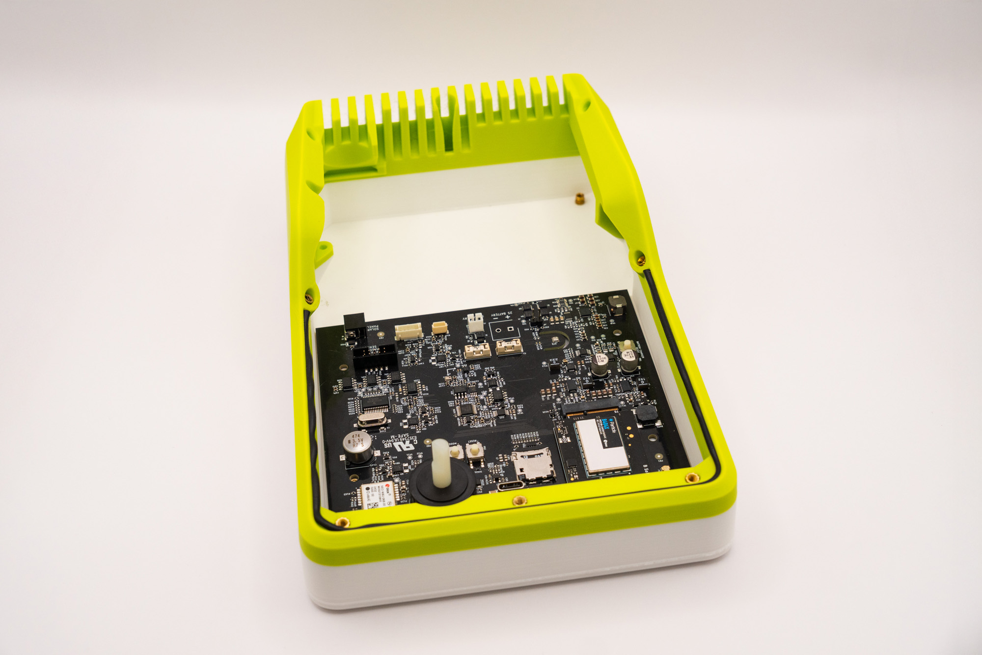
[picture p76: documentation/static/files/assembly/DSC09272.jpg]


Place the battery on the _top_ piece, making sure the cable orientation follows the image:
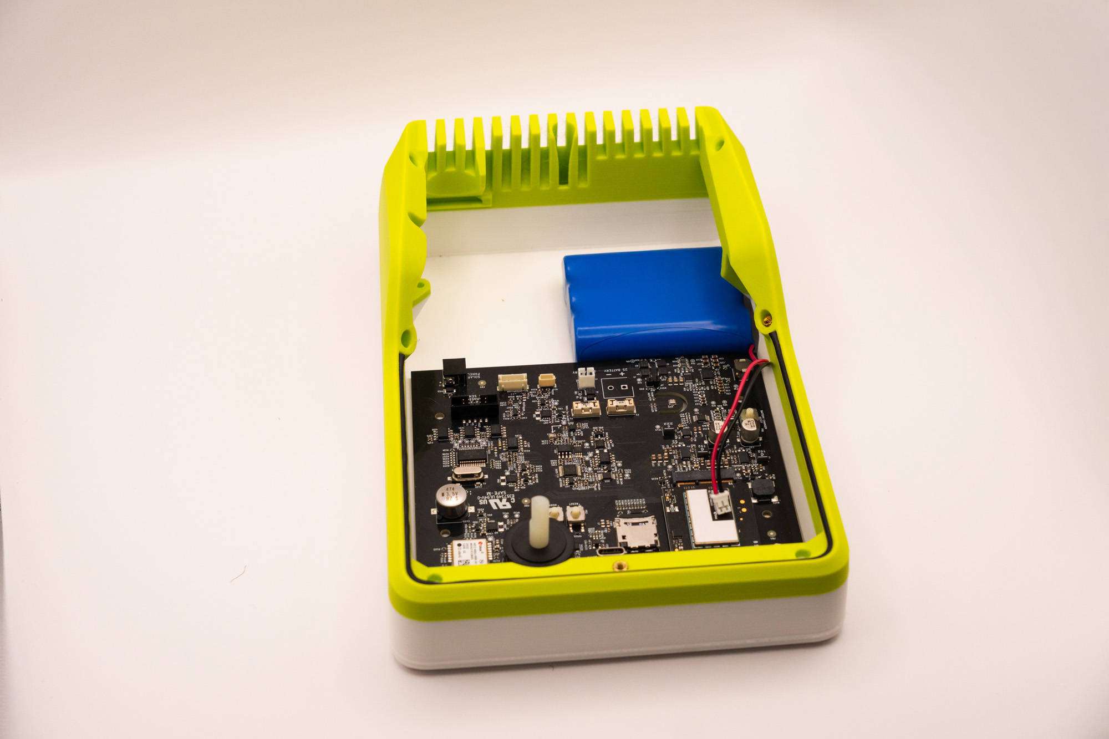
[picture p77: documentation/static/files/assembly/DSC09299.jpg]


Then, add the _battery_cover_:
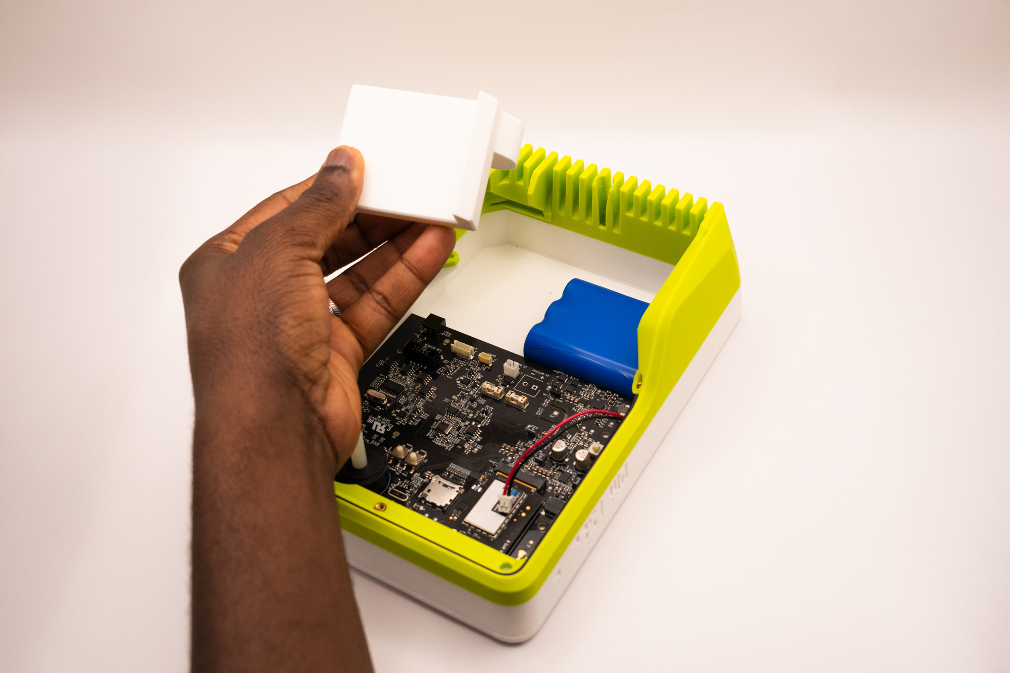
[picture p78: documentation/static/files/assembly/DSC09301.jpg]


**✅ Result**
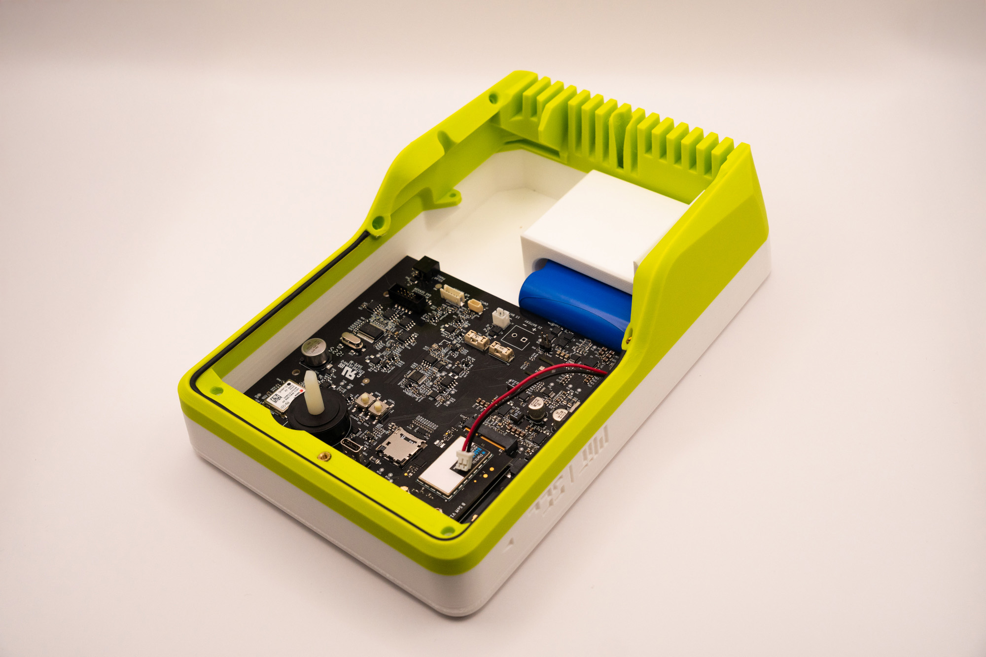
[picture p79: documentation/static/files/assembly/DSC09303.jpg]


<!-- ![alt text](../../static/files/assembly/DSC_5238.jpg) -->
<!-- ![alt text](../../static/files/assembly/DSC_5240.jpg) -->
<!-- Now, pick the Main Board and connect the battery cable: -->

## Step 8 – Secure Main Board

For fixing the Main Board, pick four M2 washers and put each into four M2X6 screws
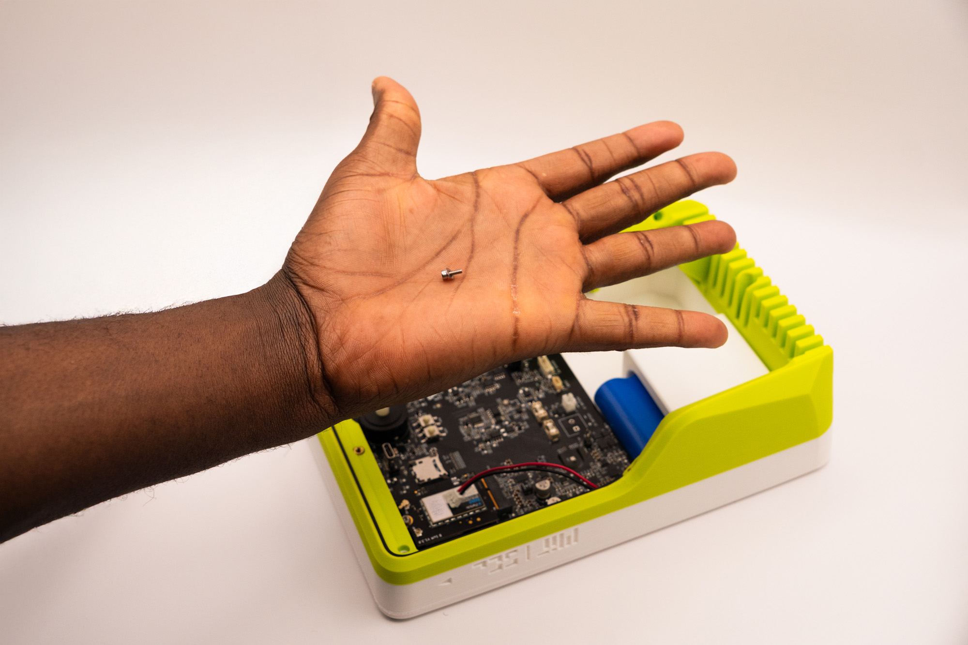
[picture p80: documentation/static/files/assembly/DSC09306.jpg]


<!-- ![alt text](../../static/files/assembly/DSC_5247.jpg) -->

Fasten them into the four indicated holes:
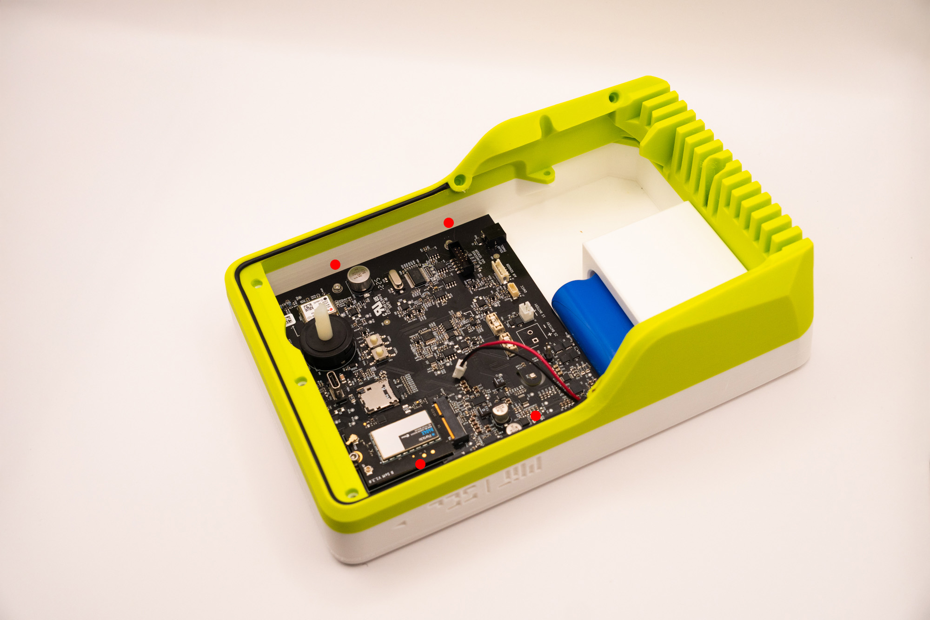
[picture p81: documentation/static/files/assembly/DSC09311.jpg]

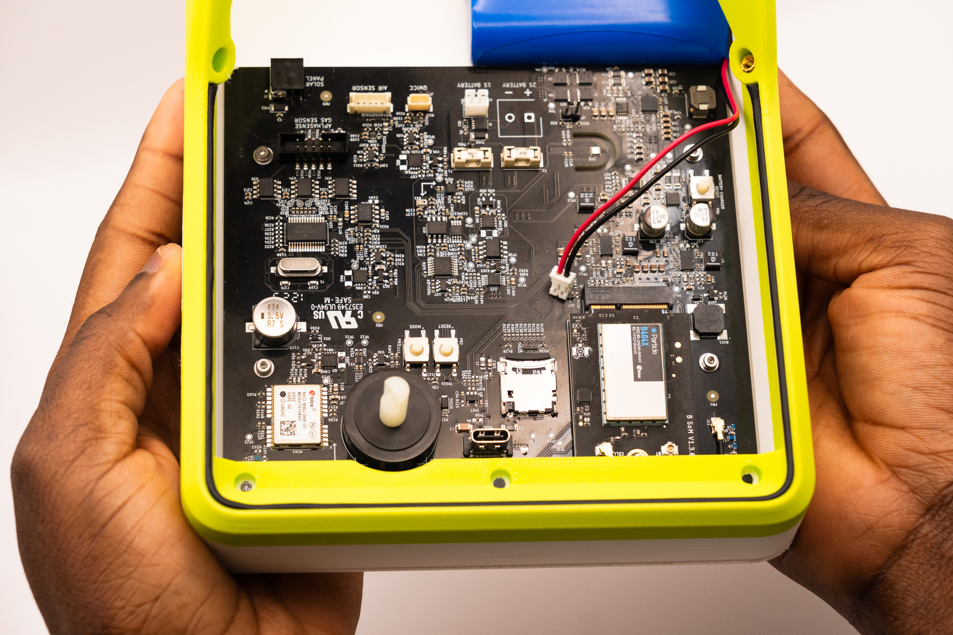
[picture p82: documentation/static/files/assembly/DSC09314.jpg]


**✅ Result**


## Step 9 – Solar Panel & Gas

Align the panel to make sure the cable is going out backwards, then pass it through the hole:
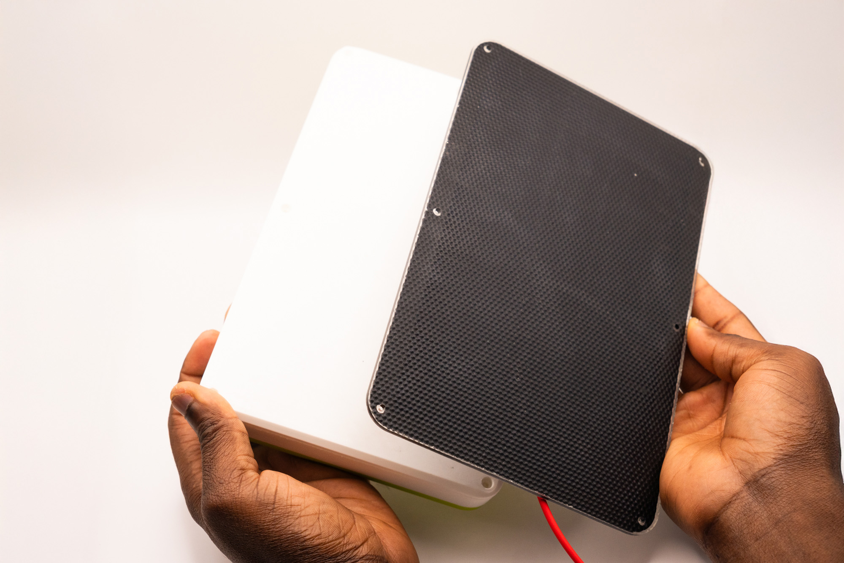
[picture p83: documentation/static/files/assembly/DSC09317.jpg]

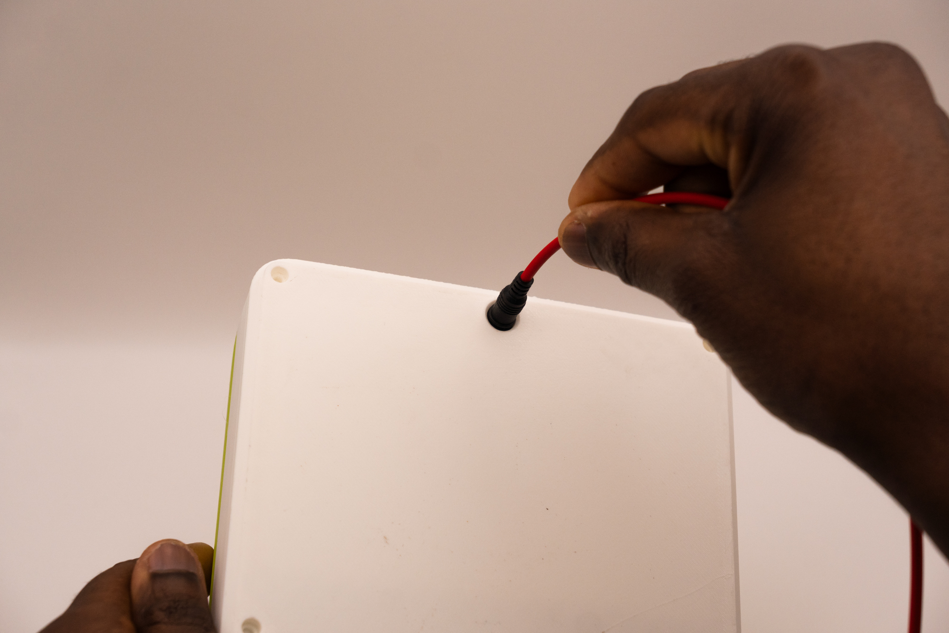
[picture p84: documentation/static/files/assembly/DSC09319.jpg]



Pick up six M3X16 screws, six M3 washers, and six 5mm spacers. These will be used to secure the solar panel to the _top_ piece in the six holes.



The correct order is **screw → washer → Solar Panel → spacer → _top_ piece**:


Start with both the intermediary holes, since that will make it easier to align the Solar Panel to the _top_ piece:



Proceed to the corners:
:::tip
Due to variation of manufacturing tolerances, it might be harder to fasten these corner screws.

Make sure the screw is properly aligned to the insert on the _top_ piece and fasten while making sure it is following the right angle.
:::


**✅ Result**


Please make sure there is no surplus of cable above the _top_ piece, all excess should be below:


Pick up a M2 washer, and solder into the hole. 



Pick up the gas and cable, and gently attach the pieces together. 



Push the gas into the corner so it sits on the ledge. 


Pick up a M2 screw to attach the gas into place. 



Attach the connector to the Main Board socket


Gently wind the cable while making sure it enters through the indicated spot on the back of the _top_ piece:


<!-- Attach the connector to the Main Board socket:
![alt text](../../static/files/assembly/DSC_5288.jpg) --> 

## Step 10 – USB-C Cable

Pick up the _Waterproof USB-C cable_:


Now, unscrew the cap and nut, remove them completely leaving the rubber seal, then put the rubber seal back:


Place the cable in the appropriate place respecting the correct order of **cable screw → rubber ring → _middle_ piece**:



While holding everything together, turn the _middle_ piece around and add the cap ring, leaving its strip pointing to the right.


Fasten the nut while keeping the cap strip at the same position:



Screw the cap:


Connect the _90º USB-C adapter_ to the _Waterproof USB-C cable_ and twist the cable as indicated to help avoiding collision with other parts when finishing the assembly:


## Step 11 – Particulate Sensor

:::tip
Pay attention to the correct orientation, since there are several ways for assembling it wrong.
:::
Place the _Sensirion sensor_ into its craddle on the _middle_ piece:



Attach the cable to the _Sensirion sensor_:



:::tip
If you need, use a tweezer or screwdriver to help attaching the sensor properly to the end.
:::


<!-- To allow for the _middle_ piece to be attached to the _top_ piece correctly, align the switch longitudinally ("on" position):
![alt text](../../static/files/assembly/DSC_5347.jpg) --> 

And turn the _Main Board_ switch twice until the green light turns on ("on" position):


Roll the Sensirion cable to remove the excess and connect it to the indicate spot:



## Step 12 – Switch & Closing

Plug in the _90º USB-C Adapter_ to the _Main Board_:
 
 

With care, align the _middle_ and _top_ pieces together while respecting the _switch_ position:


:::warning
Now you **must move back the switch** counter-clockwise to turn the device off.
:::

Fasten 3x M3x16 screws, joining the _middle_ and _top_ pieces together:





Align the _switch_top_ with the _top_ piece while respecting the _switch_ position:



Position the _bottom_ piece over the _top_ and _middle_ pieces:


Keep the cap strip out of the way:


Then insert it into the appropriate entrance on the right:


Place the last 4x M3x16 screws into the four bottom openings:


Fasten to hold it together with middle and top pieces:
:::tip
Due to the angles it might be more dificult to fasten the screws than usual.

Instead of fixing one at once then proceding to the next, it is easier if each one is tightened a bit at a time.
:::


**✅ Result**
:::warning
Make sure all seams are neatly aligned to avoid sealing issues.
:::


## Step 13 – Magnets

Fasten both _magnets_ into the _botton_ piece, making sure it is well tightened:




## Step 14 – Identification
:::tip
It is recommended to label each unit with a unique ID to avoid data identification issues:
:::



## You made it!

<!-- ![alt text](../../static/files/assembly/DSC_5375.jpg)
![alt text](../../static/files/assembly/DSC_5376.jpg) -->
<!-- ![alt text](../../static/files/assembly/DSC_5389.jpg) -->



<!-- ![alt text](../../static/files/assembly/DSC_5392.jpg) -->



<!-- ![alt text](../../static/files/assembly/DSC_5394.jpg)
![alt text](../../static/files/assembly/DSC_5395.jpg)
![alt text](../../static/files/assembly/DSC_5396.jpg)
![alt text](../../static/files/assembly/DSC_5397.jpg)
![alt text](../../static/files/assembly/DSC_5398.jpg)
![alt text](../../static/files/assembly/DSC_5399.jpg)
![alt text](../../static/files/assembly/DSC_5400.jpg) -->

<!-- ARCHIVE --> 

<!-- ## Step 10 – Switch

Place the _switch_bottom_ into the _middle_ piece, from below:
![alt text](../../static/files/assembly/DSC_5313.jpg)
![alt text](../../static/files/assembly/DSC_5314.jpg)

Insert the o-ring into the _switch_top_, observing if it is perfectly fitting into its recess:
![alt text](../../static/files/assembly/DSC_5316.jpg)
![alt text](../../static/files/assembly/DSC_5317.jpg)

Align, then join the _switch_top_ and _switch_bottom_ with a M2X6 screw while keeping the _middle_ piece in between:
![alt text](../../static/files/assembly/DSC_5319.jpg)
![alt text](../../static/files/assembly/DSC_5320.jpg)

**✅ Result**
:::info
The switch must move freely between start and end, but there should be no play between the three parts.
:::
![alt text](../../static/files/assembly/DSC_5323.jpg)
![alt text](../../static/files/assembly/DSC_5324.jpg) --> 

<!-- ## Step 12 – Sensing Board

:::info
Depending on your needs, choose the appropriate gas sensor: CO+NO2 or O3+NO2 (depicted).
:::

First, start by assembling the desired Alphasense AFE board module into the Sensor Board:
![alt text](../../static/files/assembly/DSC_5289.jpg)
![alt text](../../static/files/assembly/DSC_5292.jpg)
:::warning
Make sure the module is properly aligned, because it is easy to attach it wrong.

The module sides must be parallel, and aligned to the Sensing Board edges.
:::
![alt text](../../static/files/assembly/DSC_5293.jpg)

To place the Sensing Board into the _top_ piece, fit it into the back part while keeping it angled:
![alt text](../../static/files/assembly/DSC_5294.jpg)

Swing it down, while paying attention to the fitting on the left side:
![alt text](../../static/files/assembly/DSC_5295.jpg)

Finally, slide the Sensing Board away, making sure the Solar Panel cable is on the proper place:
![alt text](../../static/files/assembly/DSC_5296.jpg)

To secure the Sensing Board, pick a M3X16 screw with a M3 washer and fasten it into the right hole.
![alt text](../../static/files/assembly/DSC_5297.jpg)
:::warning
Do not fasten the M3 screw excessively or you might damage the Sensing Board.

It should be enough just for the Sensing Board to be held at place
:::
![alt text](../../static/files/assembly/DSC_5299.jpg)

Finally, pick a M2X6 screw with a M2 washer to used on the left hole.
:::tip
This is trickier since the screw needs to be put underneath the Alphasense AFE board.

You can raise it a little bit if needed, making sure it doesn't get disconnected.
:::
![alt text](../../static/files/assembly/DSC_5300.jpg)
![alt text](../../static/files/assembly/DSC_5301.jpg)

**✅ Result**
![alt text](../../static/files/assembly/DSC_5303.jpg)

## Step 13 – Main Cable

The main cable connects the Main Board with the Sensing Board.

:::tip
The cable has no specific start or end, but its connectors has only one way to be inserted.
:::
![alt text](../../static/files/assembly/DSC_5304.jpg)

First, connect the cable to the Sensing Board:
![alt text](../../static/files/assembly/DSC_5307.jpg)

Then, connect the cable to the Main Board:
![alt text](../../static/files/assembly/DSC_5308.jpg)
![alt text](../../static/files/assembly/DSC_5309.jpg)

To organize the cables, place them underneath the Alphasense AFE board.
![alt text](../../static/files/assembly/DSC_5310.jpg)

**✅ Result**
![alt text](../../static/files/assembly/DSC_5312.jpg)

## Step 14 - Camera Cable

Now you can connect the camera cable, beginning with the camera:
![alt text](../../static/files/assembly/DSC_5343.jpg)
![alt text](../../static/files/assembly/DSC_5344.jpg)
:::tip
You might carefully use a tweezer or screwdriver to gently push the connector, but take care to not damage anything.
:::
![alt text](../../static/files/assembly/DSC_5345.jpg)

Finally, connect the cable to the Sensing Board:
![alt text](../../static/files/assembly/DSC_5346.jpg) -->

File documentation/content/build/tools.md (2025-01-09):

---
sidebar_position: 3
---

import Bench from '@site/static/files/tools/bench.png'
import Solder from '@site/static/files/tools/solderstation.png'
import Pliers from '@site/static/files/tools/pliers.png'
import Knife from '@site/static/files/tools/knife.png'
import Tweezers from '@site/static/files/tools/tweezers.png'
import Allen from '@site/static/files/tools/screwdrivers.png'
import Label from '@site/static/files/tools/labelmaker.png'

# 🧰 Tools

Tools

All tools needed are usually found in makerspaces.

| Tool | Image | Purpose | URL |
| :--- | :---: | :--- | :---: |
| Bench |   | Should have plenty of flat space to accommodate several parts at the same time. | [link](https://www.amazon.com/WORKPRO-Adjustable-Workbench-Heavy-Duty-Workstation/dp/B08BNZDB57/?th=1) |
| Soldering Station |    | Needs controllable temperature and small tip (enough to fit a M2 hole). Will be used to heat brass inserts and place them into 3d printed parts by carefully melting the plastic. No wire soldering will be needed. | [link](https://www.amazon.com/Hakko-FX888D-23BY-Digital-Soldering-Station/dp/B00ANZRT4M/) |
| Hex/Allen Screwdriver Set |   | For fastening M2, M2.5 and M3 screws. | [link](https://www.amazon.com/Wiha-26390-Screwdriver-Metric-Precision/dp/B0006OBFCC/) |
| Small Pliers Set |    | Might be used to remove 3d printed supports and aid in placing connectors. | [link](https://www.amazon.com/Circlip-HANDSKIT-Cutting-Electronics-Jewelry/dp/B0895H524L/) |
| Retractable Knife (optional) |   | Might be used to remove any unwanted excess material from supports. | [link](https://www.amazon.com/OLFA-5018-Stainless-Slide-Lock-Utility/dp/B0006Q9CMK/) |
| ESD Tweezer Set (optional) |  | Helps to pick and position small parts during assembly. | [link](https://www.amazon.com/iFixit-Precision-Tweezers-Set-Angled/dp/B079K874CQ/) |
| Label Maker (optional) |   | For labelling, in case more than one device is being made. | [link](https://www.amazon.com/DYMO-LabelManager-Portable-One-Touch-Organization/dp/B09BK3FVLZ/) |

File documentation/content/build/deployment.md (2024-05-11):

---
sidebar_position: 7
---

# Deployment

### tips

### dos and dont's

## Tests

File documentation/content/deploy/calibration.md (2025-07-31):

---
sidebar_position: 2
---

# 🎯 Calibration (files)

**City Scanner In-Situ Calibration and Deployment**

## 1 Getting to know City Scanner

### 1.1 Background

Mobile environment monitoring is a fast-developing method capable of providing high
spatial resolution information on air quality, noise, heat, and meteorology. It has been attracting
prominent attention from the scientific community and the public for a wide range of applications,
including tracing emission sources, evaluating ambient air pollution distribution, and estimating
personal exposures. The City Scanner project initiated by the Senseable City Lab at MIT is a
pioneer in mobile environment monitoring. It aims at developing a sensing platform to enable
large-scale environmental sensing tasks using existing urban fleets as sensing nodes. We envision
the platform to be adopted as a novel type of city infrastructure to enable big data collection and
evidence-based environmental/climate policymaking.

In general, City Scanner adopts a low-cost, modular design with internet-of-things (IoT)
capabilities. Environmental sensing can be expensive and high maintenance in the traditional
approach. United States Environmental Protection Agency (US EPA) defines that any air sensor
for single or multiple pollutants costing less than $2500 is considered low-cost. Sensors used on
the City Scanner are generally less than $500 and are tested with good accuracy and precision.
City Scanner implements a modular design for its on-board sensors to lower unit costs even more.
Users can easily keep redundant sensing modules to a minimum and adapt the platform in different
urban environment deployments. City Scanner is also IoT-enabled, where individual sensing units
are mounted on top of urban fleets for data collection and stream data to the cloud for storage,
manipulation, and analysis via a cellular network. Jointly, these designs have made City Scanner
a leading mobile sensing platform to empower environmental scientific research, support
evidence-based environmental and climate decision-making, and encourage citizen engagement
and awareness in environmental justice topics.

### 1.2 Sensing modules on a City Scanner

We illustrate City Scanner version ‘Flatburn’ that is being used for multiple data collection
campaigns in global cities in Figure 1. Each City Scanner has two major modules: the core and
sensor modules. The core module houses the motherboard, the data communication and local
storage system, and the battery and thermal performance management system. The sensor module,
GPS and solar panel are connected to and managed by the core module. The core module design
detailsre presented in the hardware and firmware open-source manual. Here, we focus on the
sensor module that includes all environmental sensors. Figure 1 demonstrates the anatomy of a
baseline sensor module configuration. It contains one optical particle counter, two gas sensors, a
temperature and humidity sensor, and a noise sensor.

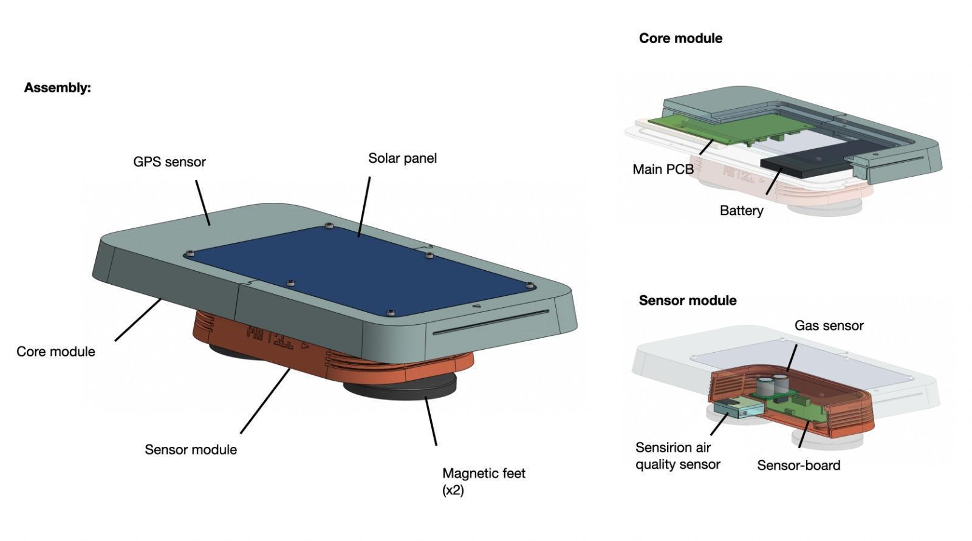
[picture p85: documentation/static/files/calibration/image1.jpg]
Figure 1. Flatburn basic configuration


_Figure 1. Flatburn basic configuration_

We list the environmental sensors that are currently being used in Table 1. Sensirion SPS30
optical particle counter (OPC) is a low-cost sensor for measuring ambient particulate matter (PM).
A laser beam is emitted through the air flow being drawn in so that by counting the pulses of light
scattered by particles in the air flow, OPC can count the number of particles. Based on the intensity
of scatter light, it is also able to measure particle size. Sensirion OPC has been adopted in academic
and citizen science projects, whose performance and durability have been proven among other competitors
in the market. Two gas sensors can be hosted in the sensor module at the same time.

Currently, we are using Alphasense’s electrochemical gas sensors for CO, NO2, and SO2. The
surface material on an electrochemical gas sensor reacts with the target gaseous pollutant, which
results in an electric current that passes from the working to the reference electrode. The current
is measured and is proportionate to the target pollutant’s concentration. The sensor board can also
be equipped with low-cost noise, temperature, and humidity sensors for measurements. But this
document mainly explained how air quality sensors are calibrated.

_Table 1. Environmental sensor specifications_

| Sensor | Sensing object | Unit cost | Substitution |
| :--- | :--- | :---: | :---: |
| Sensirion SPS30 Optical Particle Counter | Particulate matter count and estimated mass concentration | $50 | With a thermal camera  |
| Alphasense CO-A4 | Carbon monoxide | $50 | With other gas sensors |
| Alphasense NO2-A4 | Nitrogen dioxide | $50 | With other gas sensors |
| Alphasense SO2-A4 | Sulfur dioxide | $50 | With other gas sensors |
| MIC MEMS Analog | Noise | $50 | N/A |
| BME280 | Temperature, humidity | $0.88 | N/A |

## 2 Low-cost sensor calibration basics

### 2.1 The importance of calibration

Low-cost sensors suffer from constant data quality and stability issues. For example, the
abovementioned OPC cannot discern particulate matter from water droplets, thus, does not
function well in high-humidity environments. Moreover, OPC-observed PM mass concentration
is estimated based on particle shape and density assumptions, varying drastically from place to
place and season to season. Electrochemical gas sensors are known for their cross-sensitivity,
which is a common phenomenon where the electrochemical surface material reacts with gases
other than the target one. Therefore, sensor collocation and calibration are of utmost importance
to ensure accurate results before field deployment. Collocation is the process of deploying sensors
side-by-side with reference monitors and calibration involves adjusting raw sensor readings using
collocation data and mathematical methods. We summarized seven issues that affect low-cost
sensor performance from low-cost sensor calibration literature within the last five years:
intersensor variability, intra-sensor variability, drift, aging, response time, cross-sensitivity, and
sensitivity to environmental factors.

Inter-sensor variability refers to the variability in measurements using multiple identical
sensors under the same testing environment. The calibration for inter-sensor variability is crucial
for low-cost sensors as it is the foundation of large-scale sensor deployment and data transferability.
Intra-sensor variability describes the variability in consecutive measurements a given sensor makes
under the same testing environment. Drift is the gradual change in sensor response over time.
Aging refers to the continuous deterioration of sensor performance over time. Unlike reference
sensors, low-cost sensors are prone to drifting and have a much shorter lifetime. Thus, they require
routine sensor calibration and replacement. Response time reflects the lag before sensors reach
stable readings in the test environment. The difference between response time and temporal signal
change scale is critical for time-resolved sampling. Cross-sensitivity, an issue exclusive to gas
sensors, denotes a sensor’s false response to gases other than the target gas. Finally, sensitivity to
environmental factors, including temperature, humidity, wind, barometric pressure, and particle
composition, is ubiquitous in both low-cost and reference sensors. These environmental factors
are commonly identified as the main explanatory variables in low-cost sensor calibration models.

### 2.2 How do people calibrate sensors

The United States Environmental Protection Agency (EPA) is a federal agency that
regulates and manages environmental protection matters. They also provide references, guidelines,
and regulations considered “the gold standard” for air quality monitoring, primarily in the US and
many other countries. In order to facilitate the use of low-cost sensors for non-regulatory purposes,
EPA has initiated multiple projects and gathered opinions from various stakeholders. In 2021, EPA
published air sensor performance target reports for Ozone and PM2.5 low-cost sensors, which
provides consistent testing protocols, metrics, and target values to evaluate the performance of
low-cost sensors for non-regulatory applications. Previously, only a few studies followed regulated
sensor calibration protocols, whereas most studies developed their own project-specific protocols.

It hinders the inter-project comparison of low-cost sensors. Therefore, City Scanner’s calibration
and collocation protocols are mainly developed in conformity with the two reports published by
US EPA. In general, there are three phases of low-cost sensor calibration. The first phase is
collocation, which indicates a process of deploying low-cost sensors next to reference-grade
monitors. Reference monitors are a category of air sensors whose manufacturers, data quality, and
durability are certified by government agencies, specifically, EPA in the US. They are considered
the gold standard for air pollution monitoring in many regions across the globe. The second phase
is calibration, which includes adjusting raw low-cost sensor readings using statistical methods with
reference monitor data as the target variable. The last phase is evaluation, where the calibrated
results are tested against external reference monitor data (data not used in calibration training) with
statistical measures, such as Pearson correlation coefficient and mean absolute percentage error.
The three phases are detailed in Section 3.

## 3 Calibrating a City Scanner

### 3.1 In-situ collocation setup

US EPA provides two standardized performance test protocols. The base testing involves
evaluating sensors in an outdoor environment, and the enhanced testing refers to the evaluation in
a controlled lab environment. Enhanced testing is recommended if a laboratory chamber is
available but not mandatory. Hence, we will focus on the base testing protocols in the City Scanner
context.

City Scanners are recommended to be collocated and calibrated in an environment that is
as similar to the deployment environment as possible. That is to say, City Scanners should be
calibrated locally at a reference air quality station if it is available and ideally in the same season
as the deployment. Considering sensor aging and drifting, if a deployment is more than six months
in length, it is highly suggested to have collocation before and after the deployment. Usually, City
Scanners are collocated at a reference station for at least two weeks for a single deployment. This
would generate over 300 paired hourly readings, which is sufficient to fit a simple multivariate
linear regression, but not enough to account for potential nonlinearity between low-cost sensor
response and meteorological factors using machine learning algorithms. It is suggested to have a
one-month consecutive collocation if time and space allow or require higher temporal resolution
reference monitor data (finer than hourly).

Figure 2 illustrates two previous collocation and calibration campaigns in New York City
(NYC) and Boston. The setup in NYC is more desirable. As we can see, five City Scanners are
placed next to each other, facing the same direction with a secure connection to a power source.
All are very close to the reference monitors’ air inlet. This is important to ensure consistent and
continuous monitoring. The reference station is located on the rooftop of a primary school. City
Scanners are elevated from the roof, and set securely on a flat platform with no obstruction around
them. This ensures free air flow from all directions and minimizes the effects of wake dust. The
setup in Boston is not ideal but can still yield valid results. The City Scanners are placed close to
the ground instead of the reference monitors’ inlet on the roof of the container in the back, as the
power socket is located on the ground. Moreover, our City Scanners are placed quite close to the
container that hosts various reference monitors, which induces the risk of not capturing pollutant
plumes from certain directions.

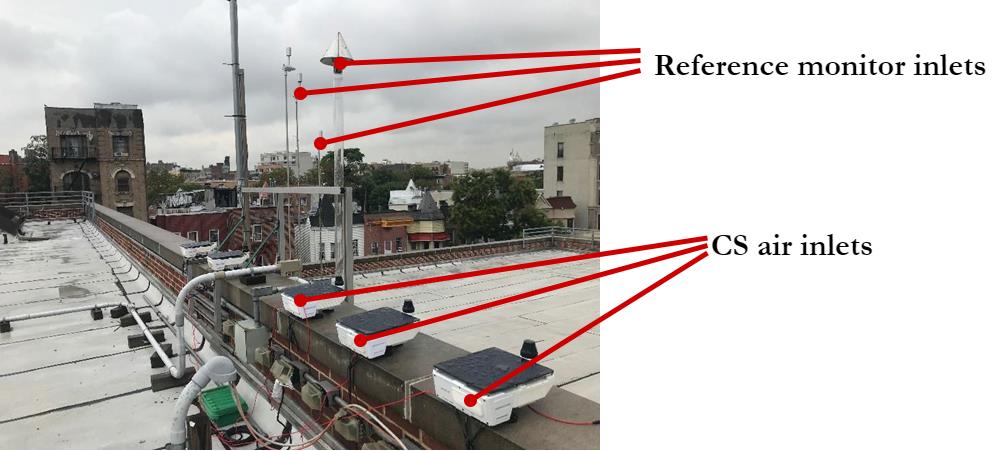
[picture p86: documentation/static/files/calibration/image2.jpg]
Figure 2. City Scanner collocation setup in (a) NYC


_(a)_

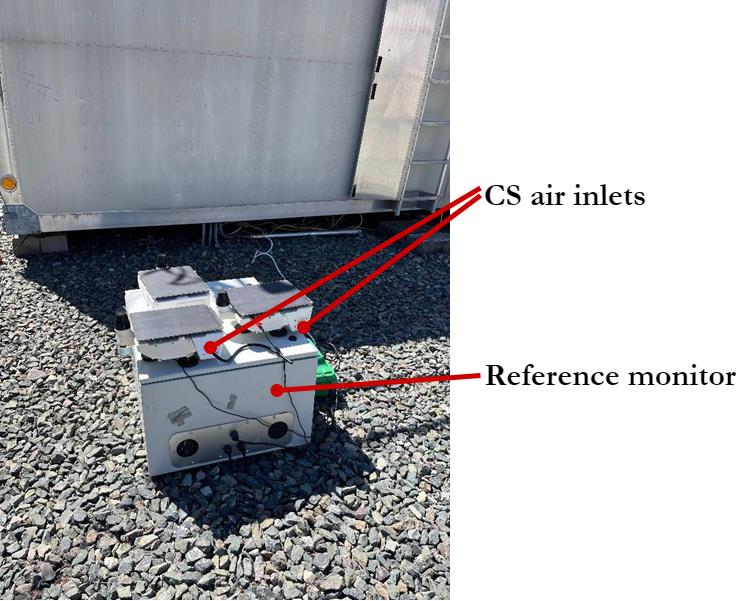
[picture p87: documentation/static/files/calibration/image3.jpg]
Figure 2. City Scanner collocation setup in (b) Boston


_(b)_

_Figure 2. City Scanner collocation setup in (a) NYC (b) Boston_

### 3.2 Data processing and digest

Collected data can be downloaded directly from the SD card located in the core module.
Locally downloaded data are not cleaned and do not have field names attached, which need to be
done manually in this case. Figure 4 presents a sample of locally downloaded raw data. Raw data
are separated into multiple files for a single deployment. There are three steps before one can use
it for calibration or analysis, including combining, filtering, and renaming. First, we need to
combine the data files from the same City Scanner in the same campaign. Second, the records
marked with ‘0’ in the first column are invalid and should be filtered out. Lastly, the first column
needs to be discarded so that all field names can be attached to each column. There are, in total,
46 fields as listed in Table 2. We have provided a simple python script to automate this process.

Figure 4. Locally downloaded City Scanner raw data from the previous City Scanner prototype

_Figure 4. Locally downloaded City Scanner raw data from the previous City Scanner prototype_

_Table 2. City Scanner data file fields and definitions_

| Field name | Definition |
| :---: | :--- |
| `deviceID` | - |
| `timestamp` | Time stamp in epoch time |
| `latitude` | - |
| `longitude` | - |
| `PM1` | PM1 mass concentration in ug/m3 |
| `PM25` | PM2.5 mass concentration in ug/m3 |
| `PM10` | PM10 mass concentration in ug/m3 |
| `flowrate` | OPC flowrate at air inlet |
| `countglitch` | Possible OPC count errors |
|  `laser_status` | OPC laser status |
| `temperature_opc` | OPC temperature in Celsius |
|  `humidity_opc` | OPC humidity in percentage |
|  `data_is_valid`  | If OPC data is valid |
| `temperature` | Ambient temperature in Celsius |
| `humidity` | Ambient humidity in percentage |
| `gas_op1_w` | Gas sensor 1 working electrode millivoltage (This is the measurement proportionate to gas 1 concentration) |
| `gas_op1_r` | Gas sensor 1 reference electrode millivoltage |
| `gas_op2_w` | Gas sensor 2 working electrode millivoltage (This is the measurement proportionate to gas 2 concentration) |
| `gas_op2_r` | Gas sensor 2 reference electrode millivoltage |
| `noise` | Noise level in dB |

Cleaned City Scanner data requires calibration against the reference monitor readings,
using meteorological factors as explanatory variables. Previously, we used meteorological factors
from a central weather station for all City Scanners circulating in a city, and the calibration
performance was satisfactory. Here, we mainly consider four factors that have effects on sensor
performance based on a previous City Scanner study, namely, temperature, humidity, air pressure,
and dew point. A conceptual calibration function is presented as follows, which can be fitted with
multivariate linear regression, but preferably an algorithm that can interpret nonlinearity, such as
random forest or gradient boosting trees. It is worth noting that we need to log-transform the
reference and City Scanner observations (pollutant concentration) to comply with the normal
distribution assumption if needed.

```
𝑙𝑜𝑔 (𝑟𝑒𝑓 𝑜𝑏𝑠𝑒𝑟𝑣𝑎𝑡𝑖𝑜𝑛) = 𝑓(𝑙𝑜𝑔 (𝐶𝑆 𝑜𝑏𝑠𝑒𝑟𝑣𝑎𝑡𝑖𝑜𝑛) ,𝑡𝑒𝑚𝑝, ℎ𝑢𝑚𝑑, 𝑝𝑟𝑒𝑠, 𝑑𝑒𝑤𝑝)
```

We have provided some sample codes to demonstrate the calibration process. The sample
codes take in synchronized reference air quality observations, City Scanner raw readings,
temperature, humidity, air pressure and dew point values that are aggregated to 1 min, 5 min, 10
min, 30 min, or 60 min intervals, which are common temporal resolution one can get from local
weather station and reference air quality monitors. Then, log-transformed City Scanner raw
readings and meteorological factors (in total,five predictors as in the previous equation) are passed
to a variety of calibration algorithms to train the best calibration model for each City Scanner unit.
The choice of the best calibration model is made by comparing the performance metrics in Section
3.3.

### 3.3 Performance metrics and quality assurance

Table 3 lists a series of performance metrics for base testing. It is compiled assuming
multivariate linear regression as the calibration algorithm. In reality, meteorological factors have
complex interactions with each other and with low-cost sensor performance. It is recommended
that other than linear regression, random forest calibration should be tested, which is a simple
machine learning model that can account for nonlinearity. As a rule of thumb, at least 500 data
points are needed to develop a robust random forest model.

_Table 3. Performance metrics for base testing_

**Test type: Base testing**

| Metric | Description |
| :---: | :--- |
| Precision | Variation around the mean of a set of measurements reported concurrently by three or more sensors of the same type collocated under the same sampling conditions. Precision is measured here using the standard deviation (SD) and coefficient of variation (CV). |
| Bias | The systematic (non-random) or persistent disagreement between the concentrations reported by the sensor and reference instruments. Bias is determined here using the linear regression slope and intercept. |
| **Linearity (Important)** | A measure of the extent to which the measurements reported by a sensor can explain the concentrations reported by the reference instrument. Linearity is determined using the coefficient of determination (Pearson correlation). As a rule of thumb, Pearson correlation should be over 0.9 after calibration. |
| **Error (Important)** | A measure of the disagreement between the pollutant concentrations reported by the sensor and the reference instrument. Error is usually measured using the root mean square error (RMSE) or mean absolute percentage error (MAPE). As a rule of thumb, MAPE should be less than 15%. |
| Exploring meteorological effects | A graphical exploration to look for a positive or negative measurement response caused by variations in ambient temperature, relative humidity, or dew point, and not by changes in the concentration of the target pollutant. |

## 4 Summary

This manual briefly introduced the background of the City Scanner project. It discussed in
detail a City Scanner’s sensor module, which includes environmental sensors for air quality, noise
and meteorology. We summarize several takeaways for collocation setup, including collocating
City Scanner in a similar environment as deployment, placing City Scanner close to the reference
monitor’s air inlet, locating City Scanner on an elevated, secure platform with no obstruction
around it, and securing the power supply for continuous measurements. The manual also
introduces data quality assurance and post-processing in preparation for City Scanner calibration.
Data sources and algorithms for calibration are presented, recommending taking nonlinearity into
account in this process. A list of sensor performance measures is also provided.

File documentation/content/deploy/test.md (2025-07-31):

---
sidebar_position: 1
---

# 🪁 Flatburn LTE Test Plan

This test plan outlines the validation process for the Flatburn sensing platform, integrating sensors for temperature, humidity, particulate matter (PM), noise, gas, GPS. 
The validation includes hardware, firmware, system integration, and field testing.

## 1. Hardware Validation

### 1.1 Sensor Functional Testing

**Objective:**  
Verify each sensor powers up and produces reasonable output over its expected range.

**Procedure:**  
- **Temperature/Humidity:** Power up; verify readings at room temperature, with heat/cool/humidity sources.
- **PM (Air Quality):** Use reference aerosol source; check readings at baseline and elevated PM levels.
- **Noise:** Play reference sound levels in a controlled environment; verify output.
- **Gas Sensor:** Expose to calibration gases; check sensor response.

### 1.2 Accuracy and Precision Validation

**Objective:**  
Assess how accurately and precisely each sensor measures environmental parameters.

**Procedure:**  
- **Accuracy Testing:** Compare sensor readings to calibrated reference devices.
- **Precision Validation:** Repeat measurements under stable conditions and calculate standard deviation.

### 1.3 GPS Module Testing

**Objective:**  
Verify GPS fix and position accuracy under real-world conditions.

**Procedure:**  
- **Static:** Place device at a known location; compare fix to actual coordinates.
- **Dynamic:** Move device along a predefined path; record and map results.
- **Signal Integrity:** Test GPS in open, urban canyon, and indoor environments.

### 1.4 RGB, Buzzer Testing

**Objective:**  
Validate that the RGB LED and buzzer function as intended.

**Procedure:**  
- Trigger RGB and buzzer via firmware; confirm colors and sound levels match expected behaviors.

### 1.5 Power Consumption Profiling

**Objective:**  
Measure the device’s current draw in various modes to verify battery life and identify power spikes.

**Procedure:**  
- Setup: Use a precision power analyzer to measure current.
- Modes: Check current in deep sleep (μA), idle/listening (μA/mA), active sensing (mA), GPS locked (peaks up to hundreds of mA).
- Profile: Use oscilloscope to record waveform for a full duty cycle (wake-up, sensor reads, GPS fix, data send, sleep).
- Battery Test: Run the device on battery until shutdown to validate expected runtime.
- Solar Testing: Evaluate with solar panel attached.

### 1.6 Environmental Stress Testing

**Objective:**  
Verify device operation under various temperature and humidity conditions.

**Procedure:**  
- Test in temperature/humidity chamber; record sensor and device operation.

### 1.7 Logging During Hardware Tests

**Procedure:**  
- Log all test results in CSV format (timestamp, raw sensor values, GPS, buzzer/RGB status, error flags).
- Good/Bad: Note missing values or timeouts for investigation.

## 2. Software and Firmware Validation

### 2.1 Firmware Unit and Module Testing

**Objective:**  
Use updated code and verify code with sensor functionalities.

**Procedure:**  
- Unit Test: Isolate sensor drivers, measure current.
- Error Paths: Inject faults (e.g., disable a sensor) and verify firmware stability.
- New Components: Test new additions (RGB, buzzer, ADC).

### 2.2 Integration Testing (Firmware + Hardware)

**Objective:**  
Ensure hardware and firmware operate together correctly.

**Procedure:**  
- End-to-End Test: Power on device, verify sampling and logging of each sensor with timestamp.
- Sequencing: Confirm sensors are read in correct order and synchronization.
- Unplugging: Confirm unplugging one sensor does not prevent others from working; ensure errors are logged.

### 2.3 Data Pipeline Verification

**Objective:**  
Validate data flow via USB

**Procedure:**  
- Offline Buffering: retrieve data locally, log to SD.
- Retries: Test retry logic and data loss handling.
- Timestamp Sync: Ensure correct time alignment in all logged data.

## 3. System-Level and Stress Testing

### 3.1 Full System Integration Tests

**Objective:**  
Test the fully assembled system as an integrated unit (hardware, firmware, GPS).

**Procedure:**  
- Startup/Shutdown: System should boot and begin operation; power removal should not corrupt data.
- Continuous Operation: Run device continuously for ≥72 hours.

### 3.2 USB Testing

**Objective:**  
Ensure incoming data from USB is captured correctly.

**Procedure:**  
- Device Logs: Monitor via serial print.
- USB Logs: Use script to retrieve data.

## 4. Field (Drive-By) Testing

### 4.1 Test Route Planning

**Objective:**  
Validate device under real-world driving conditions.

**Procedure:**  
- Route Selection: Cover industrial, residential, urban areas; test GPS signal in challenging locations.
- Repeatability: Plan multiple routes to test reproducibility.

### 4.2 Post-Drive Analysis

**Procedure:**  
- Data Download: Retrieve all onboard logs.
- Quality Assessment: Assess data completeness and integrity.

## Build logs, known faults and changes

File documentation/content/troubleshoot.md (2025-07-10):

---
sidebar_position: 5
---

# Troubleshoot

## LED Indicators
The Flatburn environmental sensing platform includes multiple onboard LEDs that serve different roles. Proper understanding and use of these indicators can help during deployment, diagnostics, and field maintenance.
## Main RGB LED – Particle connectivity status
This LED is part of the built-in RGB LED for the particle module (e.g, Boron)
Behavior (default, unless overridden):

🟢 Breathing Cyan: Connected to Particle Cloud

🟡 Blinking Yellow: Listening mode (waiting for setup)

🔴 Blinking Red: Error state (number of blinks = error code)

⚪ Off: Device off or LED turned off in firmware

More information here: https://docs.particle.io/troubleshooting/led/

## Red LED – Charging Status
This is a dedicated red LED located near the power management circuit.
It indicates the device’s charging state:

🔴 On: The device is currently charging

⚪ Off: Charging is complete, or no power is supplied from either the solar or the USB charging

## Second RGB LED – System Status
This is a secondary RGB LED on the Flatburn board, separate from the built-in Particle RGB LED. 

🟢 Solid Green: All sensors responding; normal operation

🟡 Blinking Yellow: Temporary error (e.g., GPS searching, network retrying)

🔴 Solid Red: Critical error (e.g., sensor failure, not temp data, or pm data)

This would give quick visual insight into the system’s state.

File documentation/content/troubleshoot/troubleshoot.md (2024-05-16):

---
sidebar_position: 7
---

# 🚩 Troubleshoot

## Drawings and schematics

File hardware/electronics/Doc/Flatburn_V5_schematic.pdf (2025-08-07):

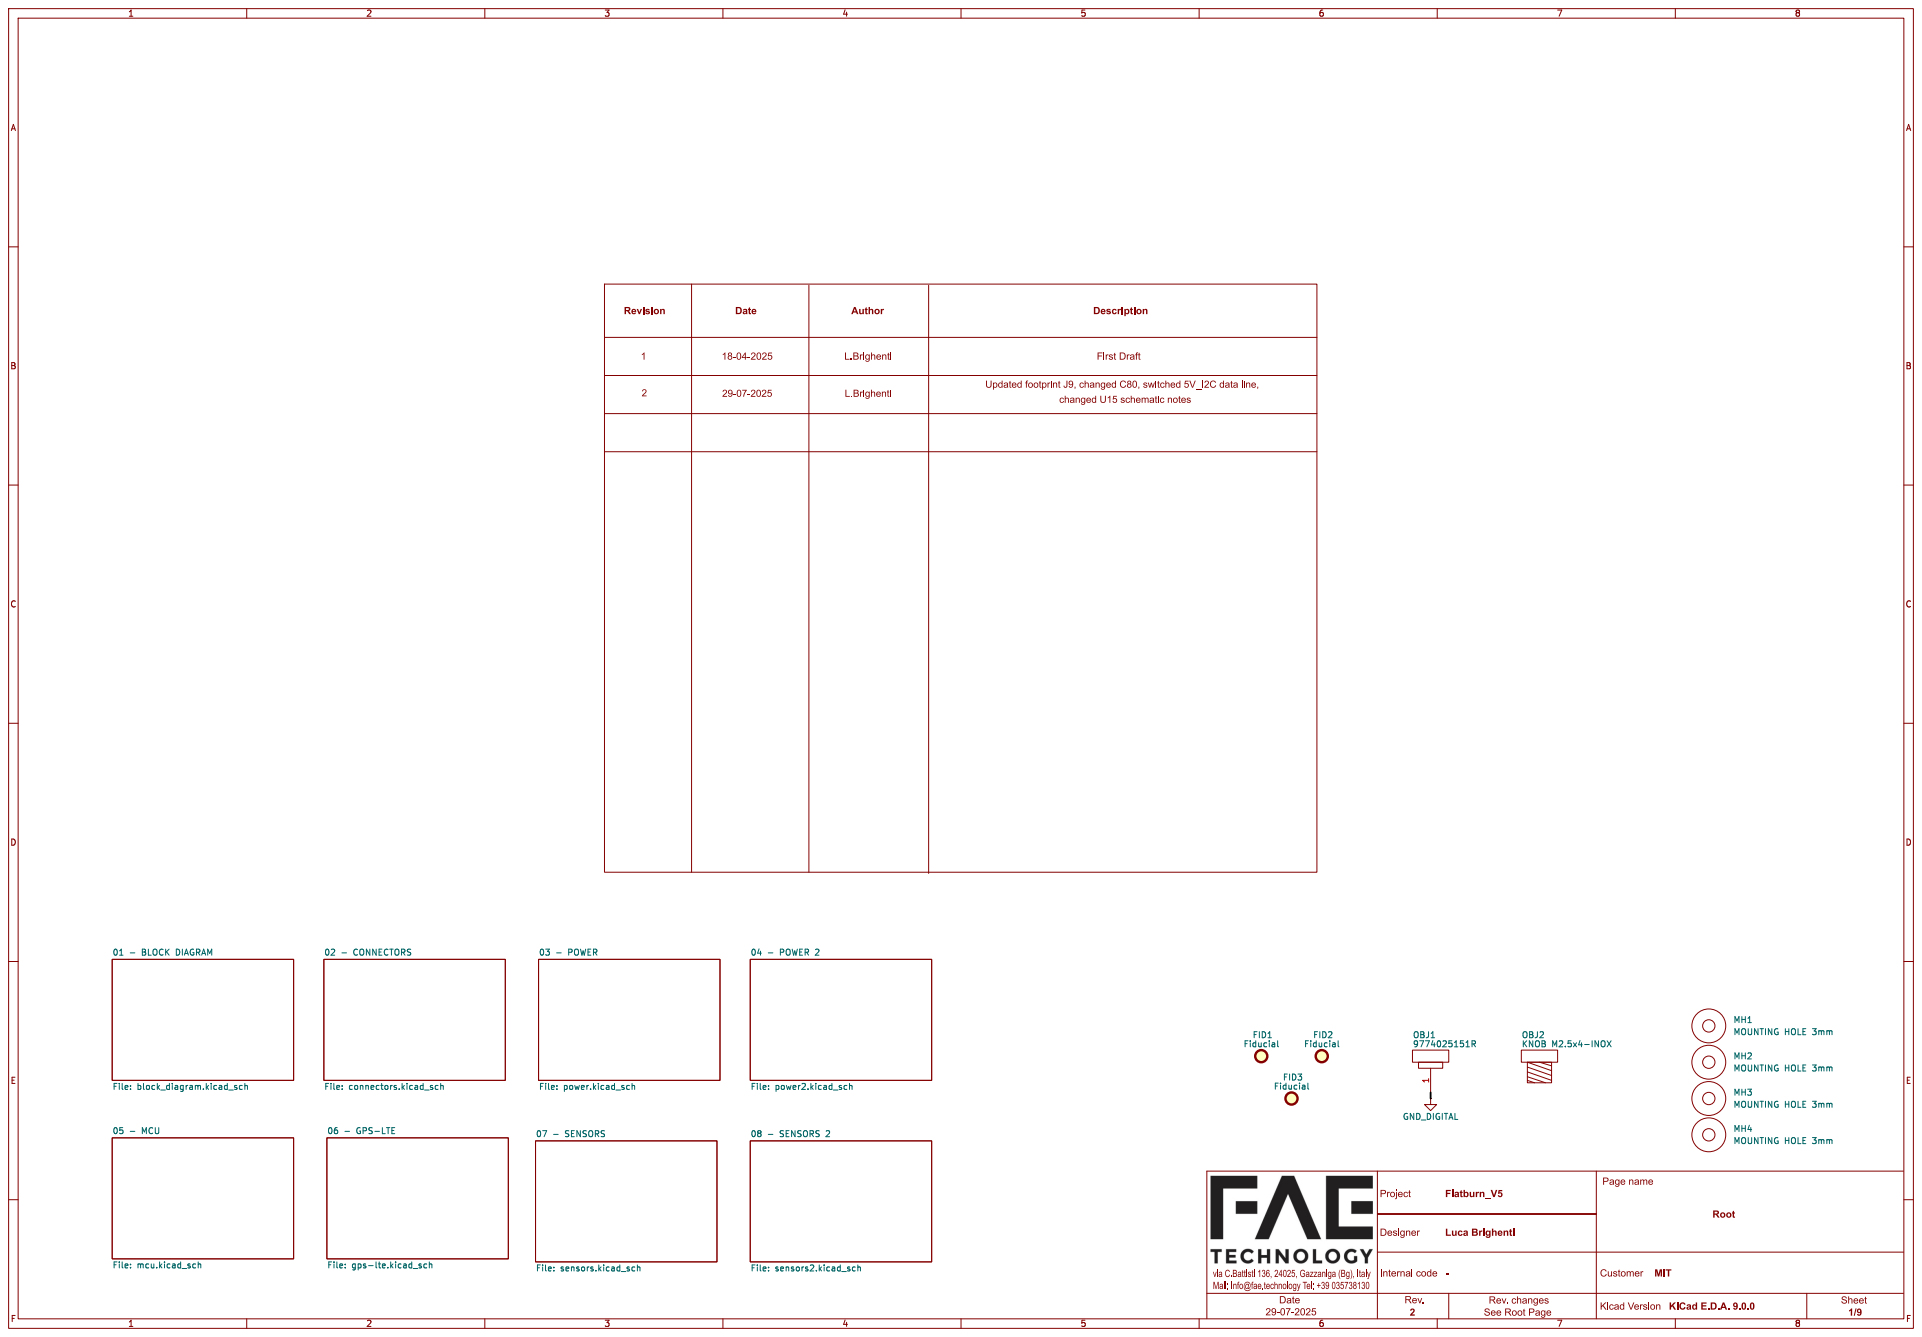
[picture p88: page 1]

via C.Battisti 136, 24025, Gazzaniga (Bg), Italy

Mail: info@fae.technology Tel: +39 035738130

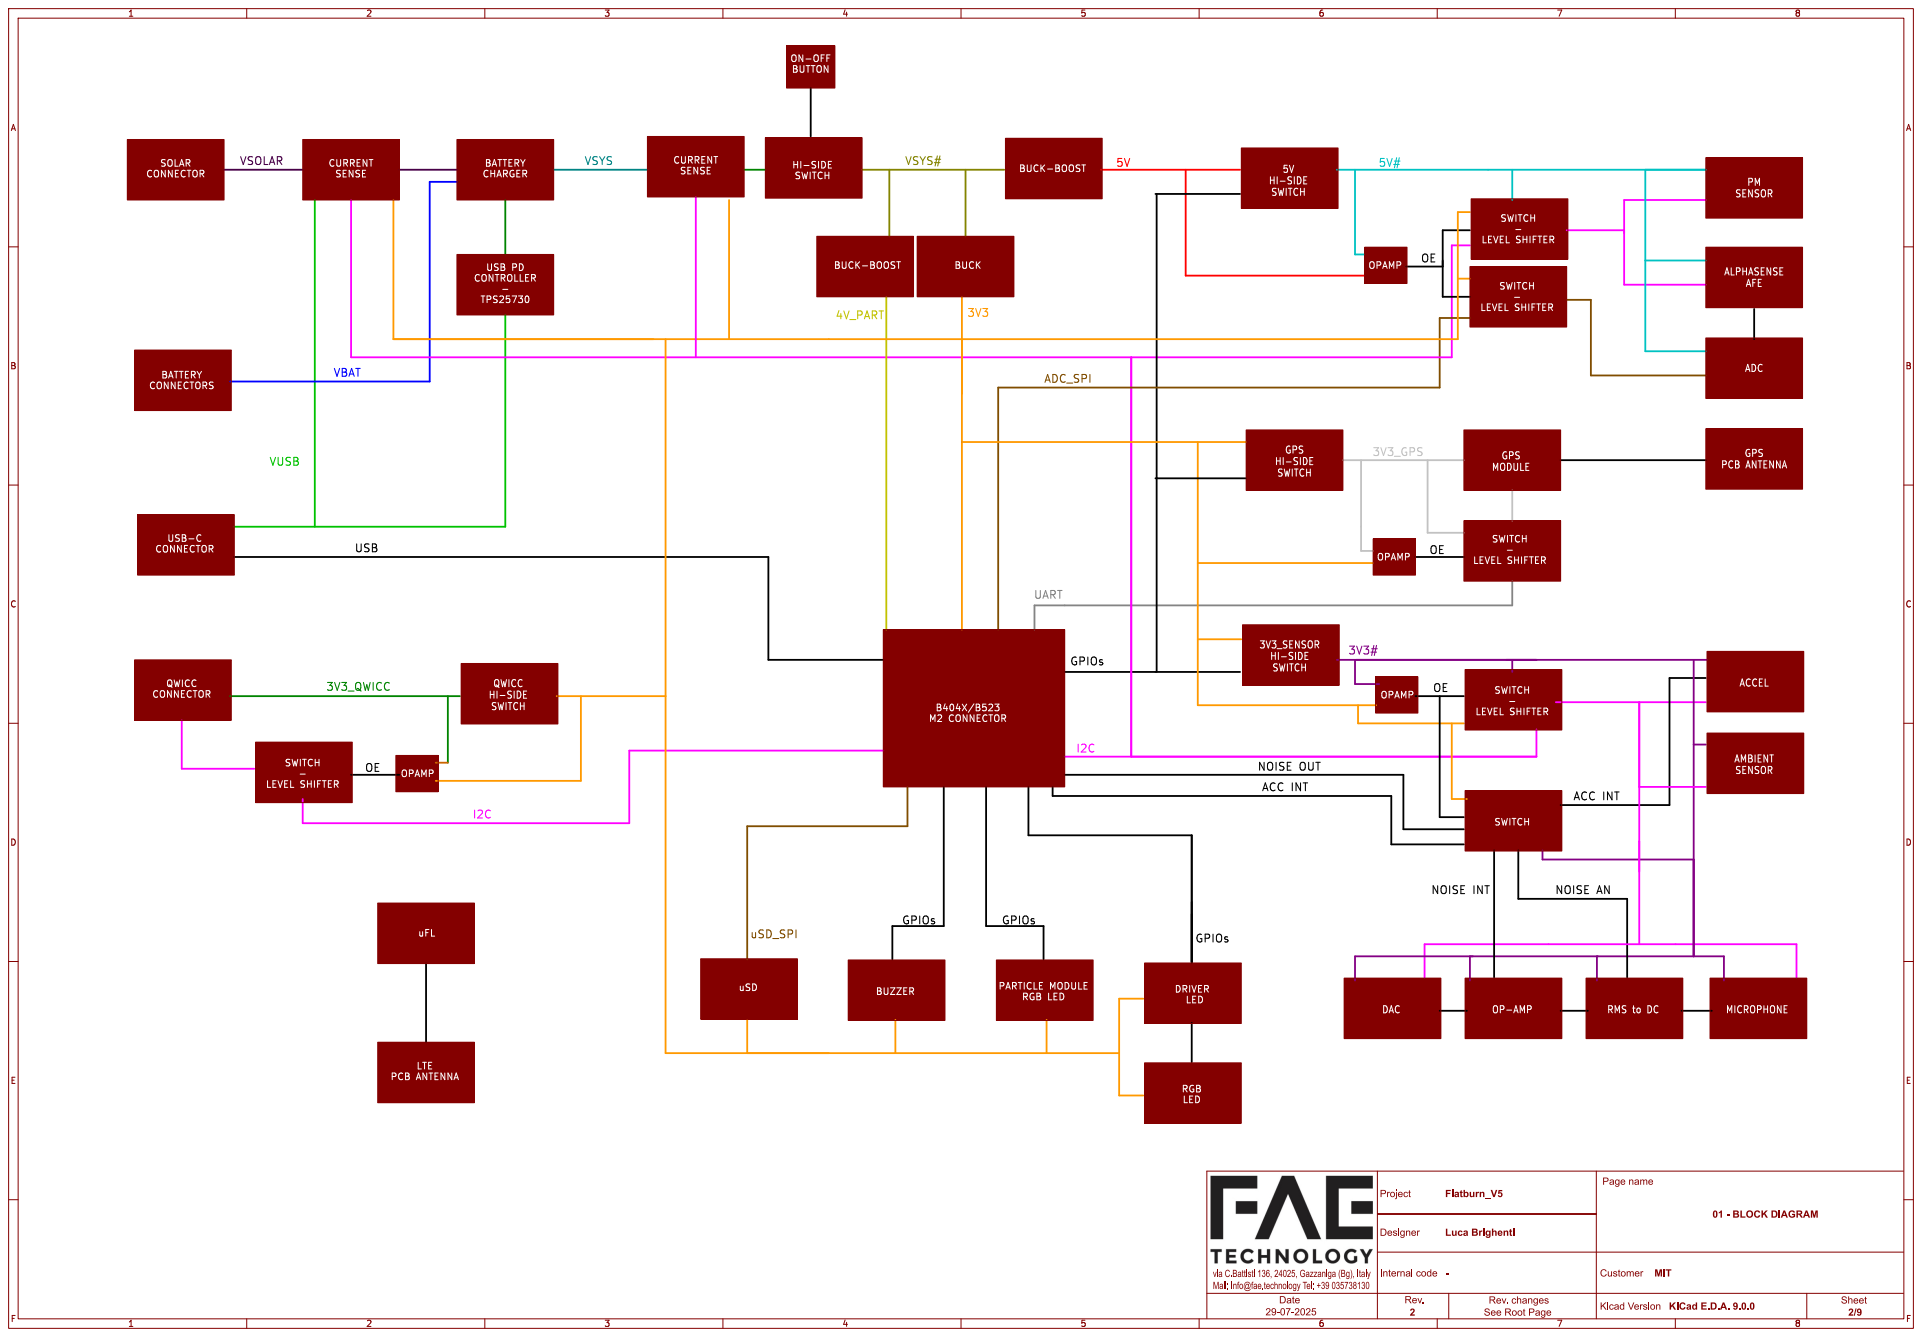
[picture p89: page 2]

SWITCH ON-OFF BUTTON

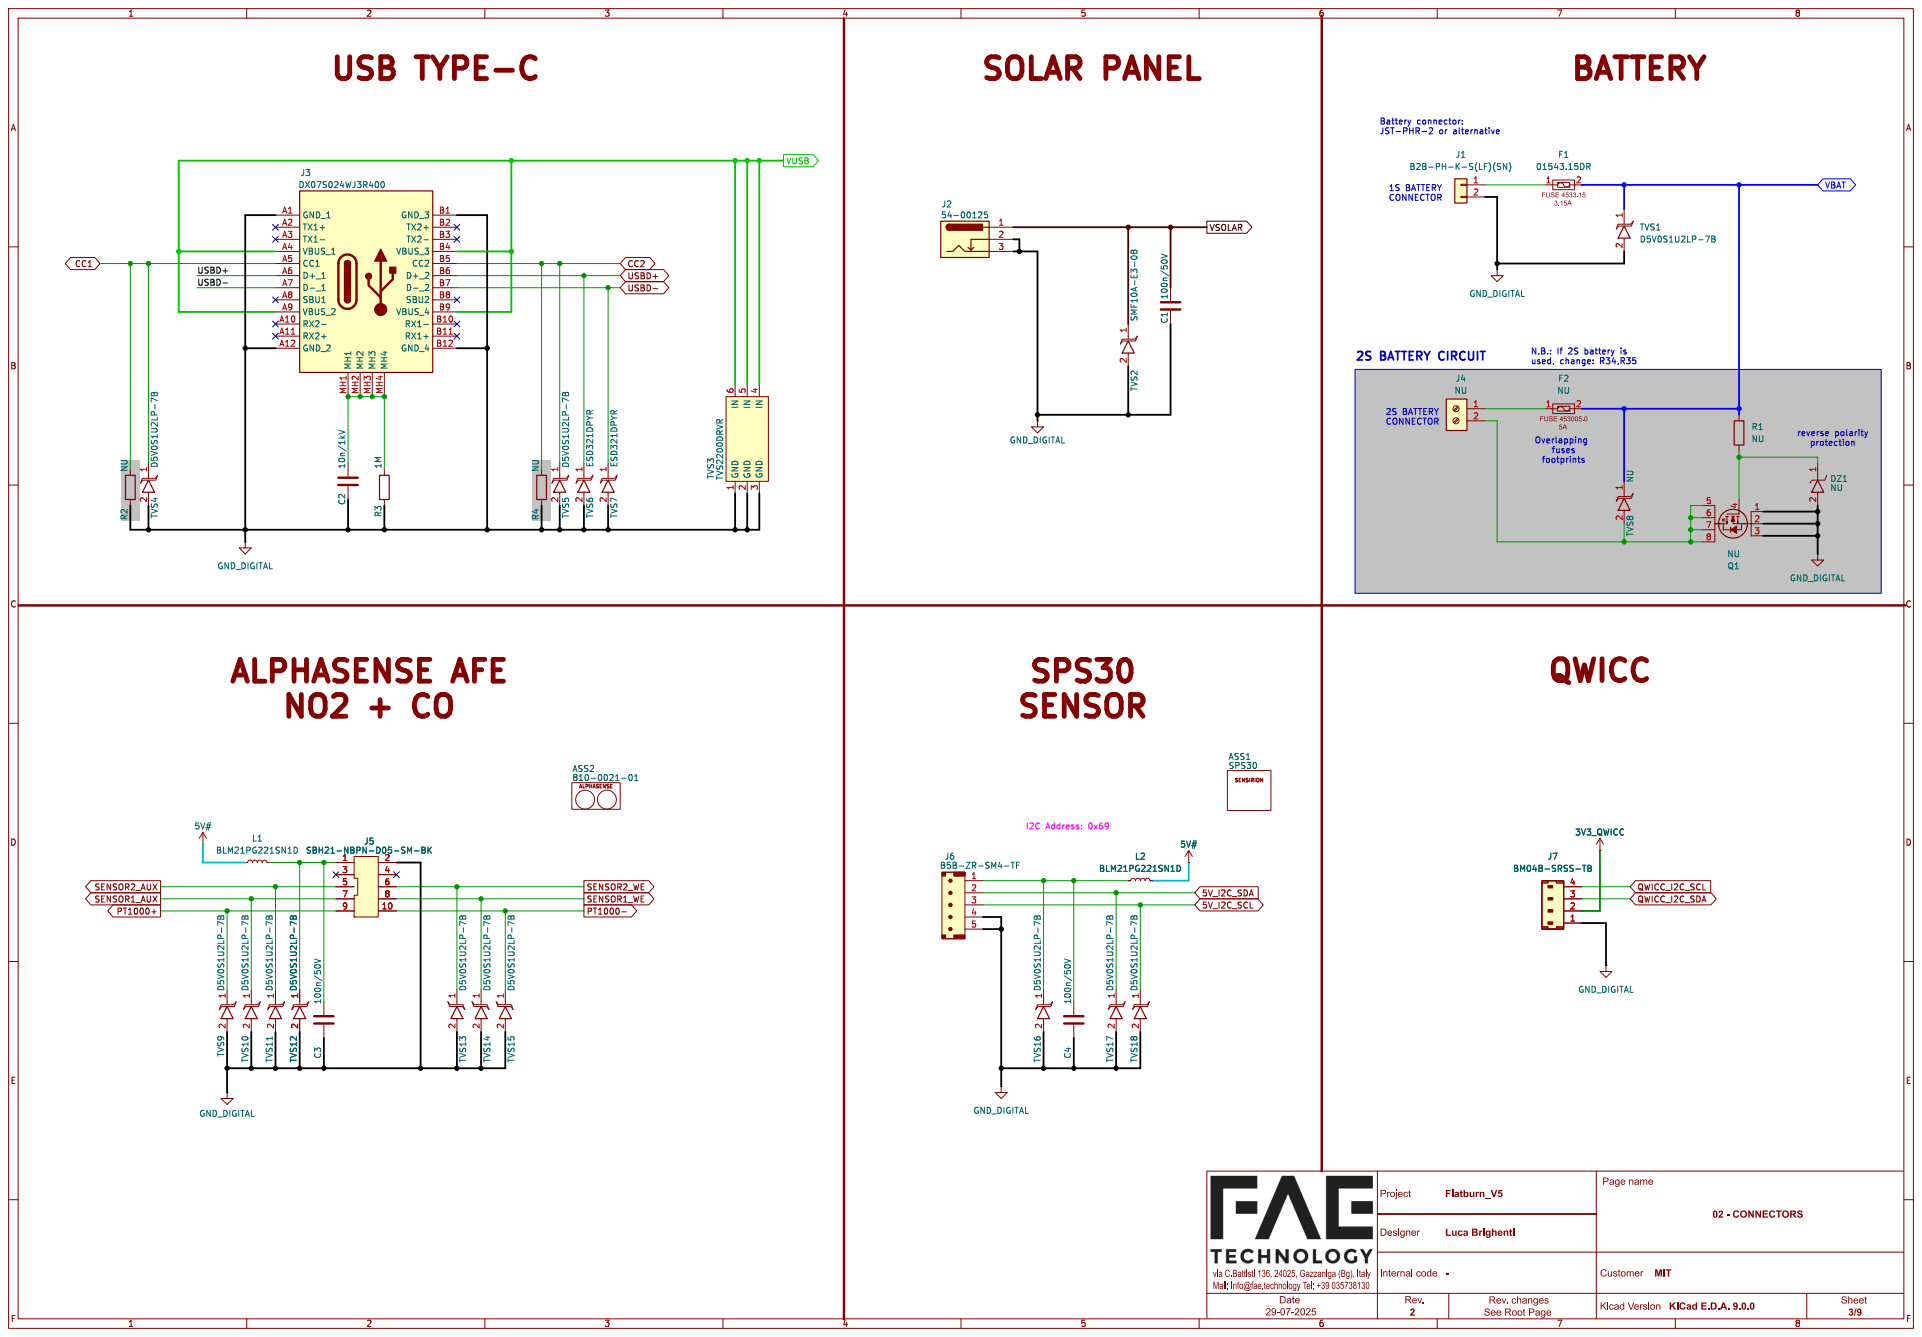
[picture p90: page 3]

N.B.: If 2S battery is used, change: R34,R35 SPS30

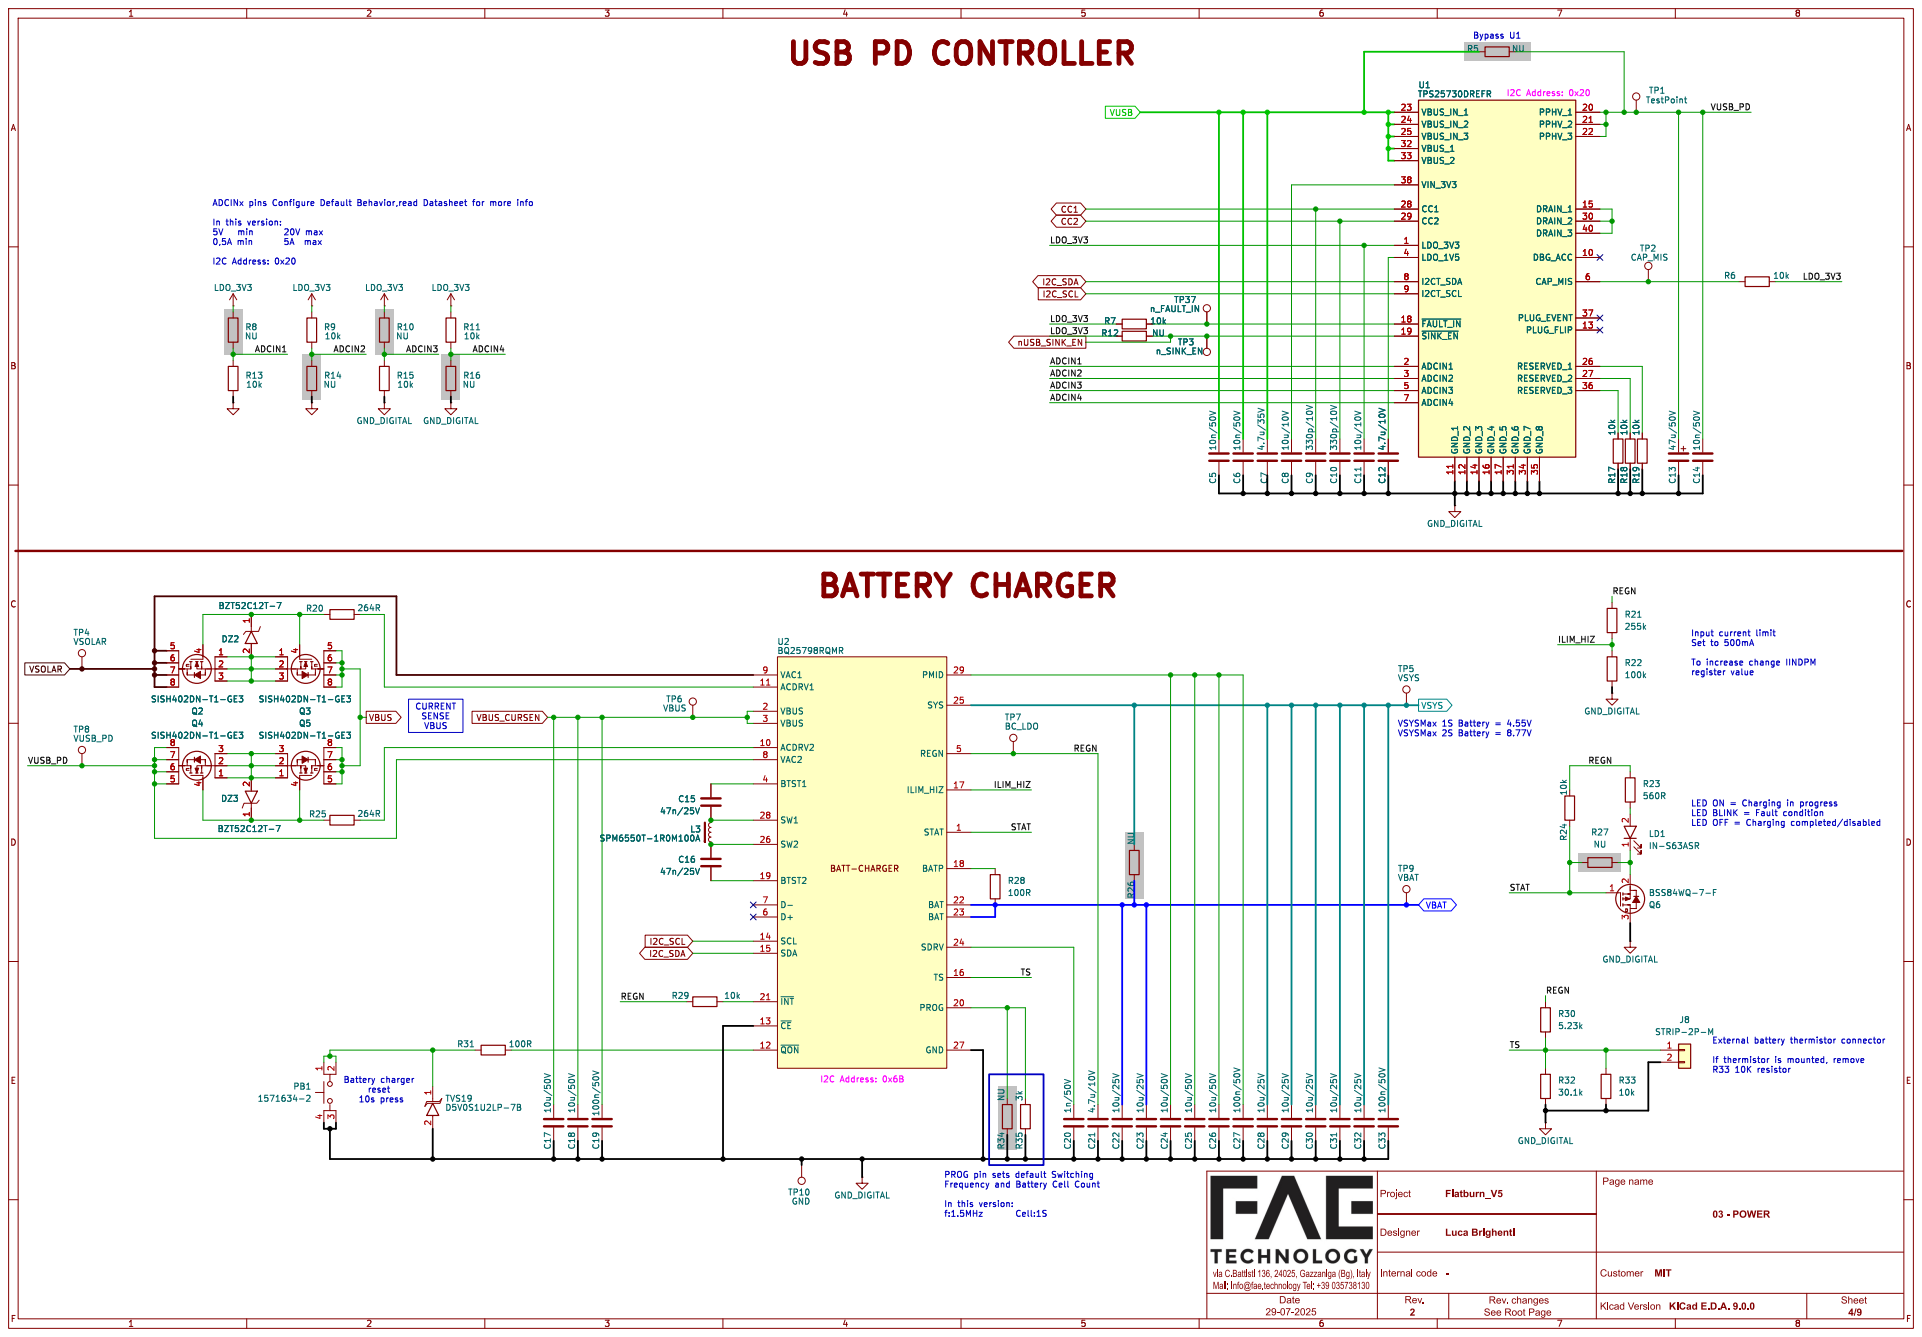
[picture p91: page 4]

Input current limit Set to 500mA

To increase change IINDPM

LED ON = Charging in progress LED BLINK = Fault condition

LED OFF = Charging completed/disabled

Frequency and Battery Cell Count

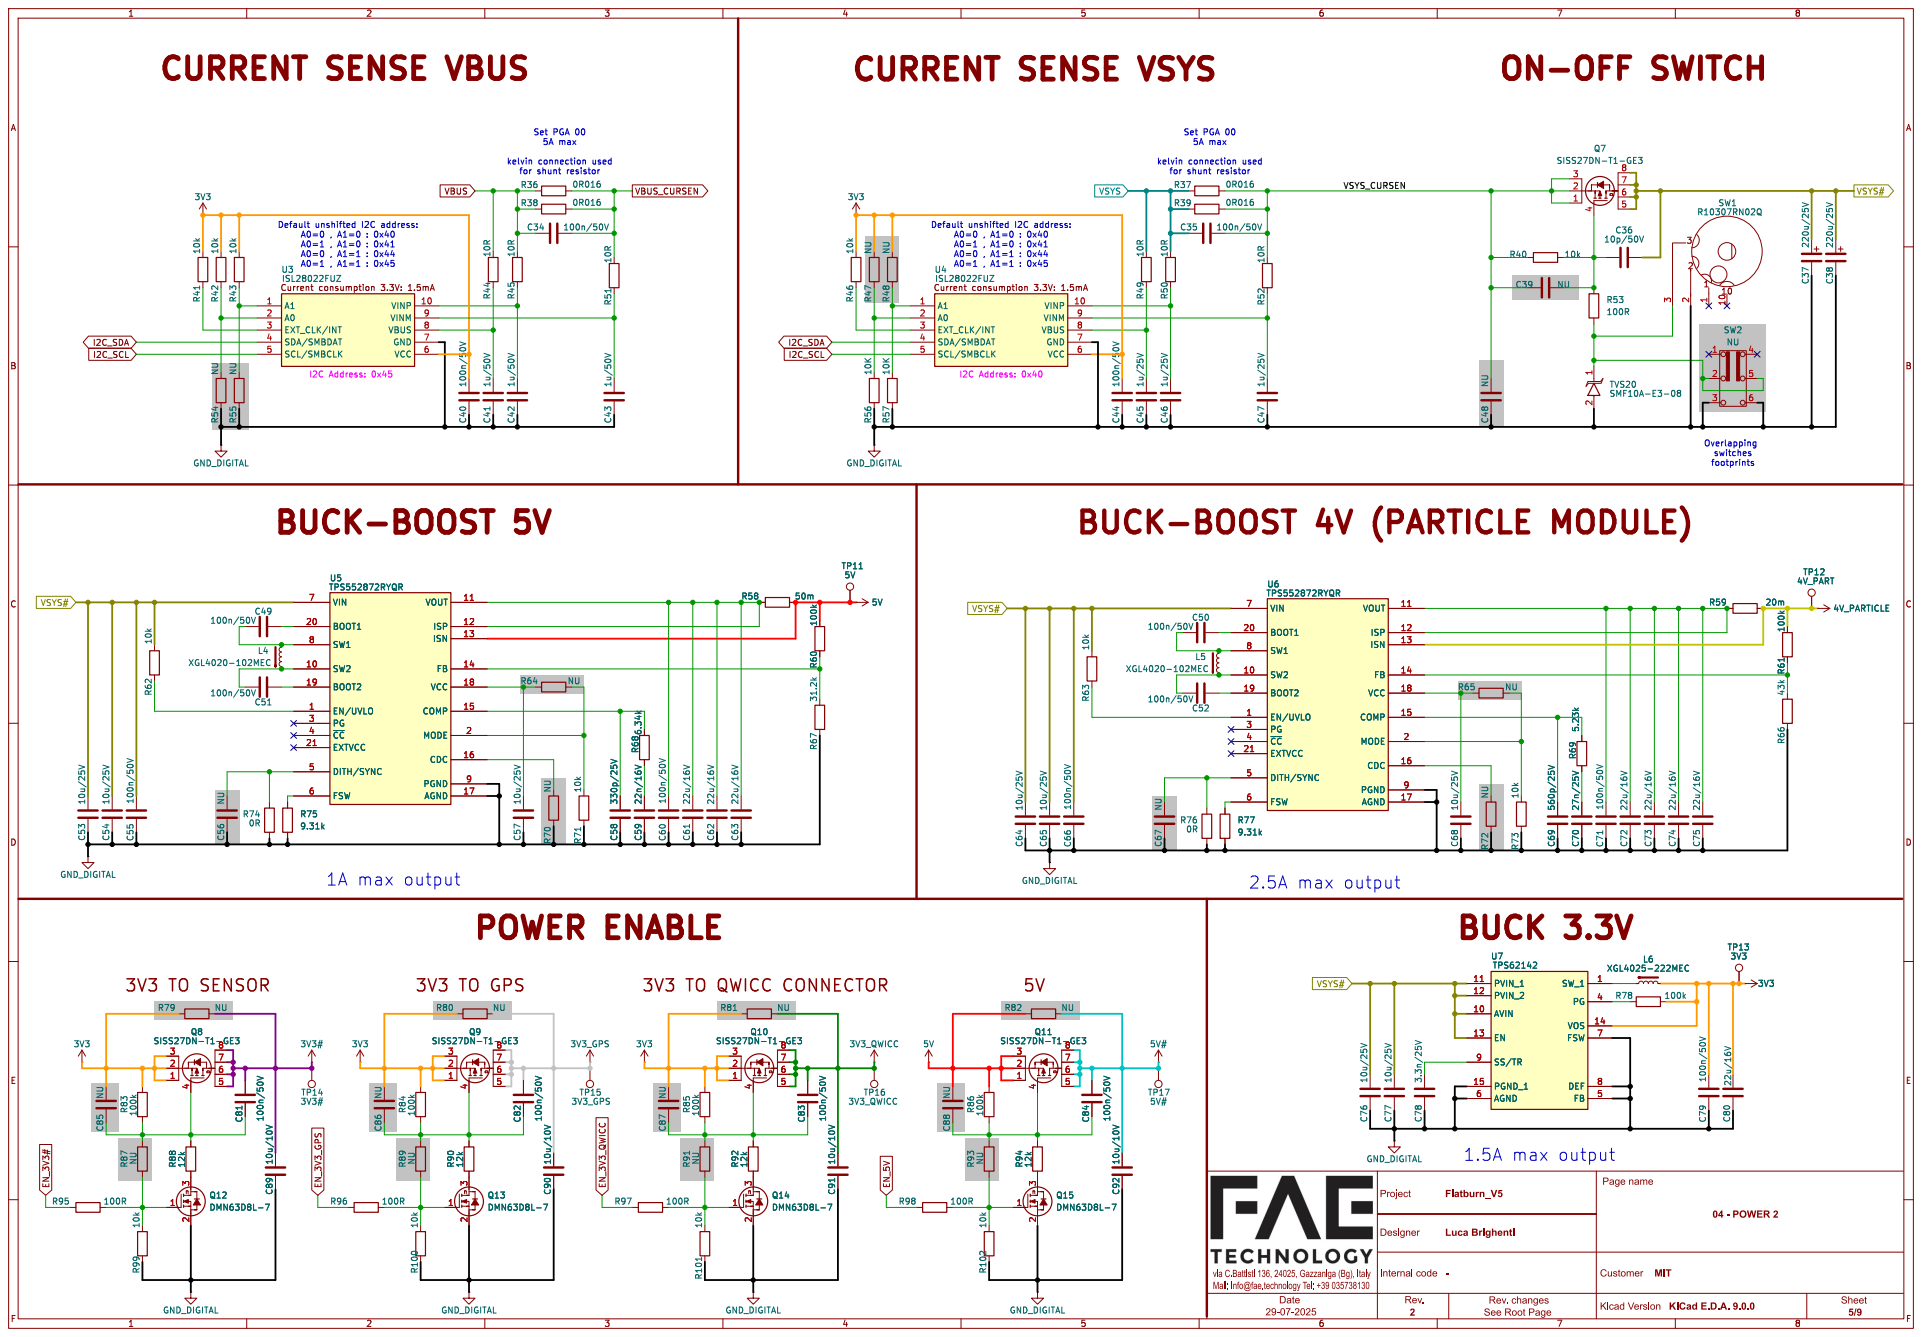
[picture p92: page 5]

BUCK-BOOST 4V (PARTICLE MODULE)
9.31k U6 TPS552872RYQR

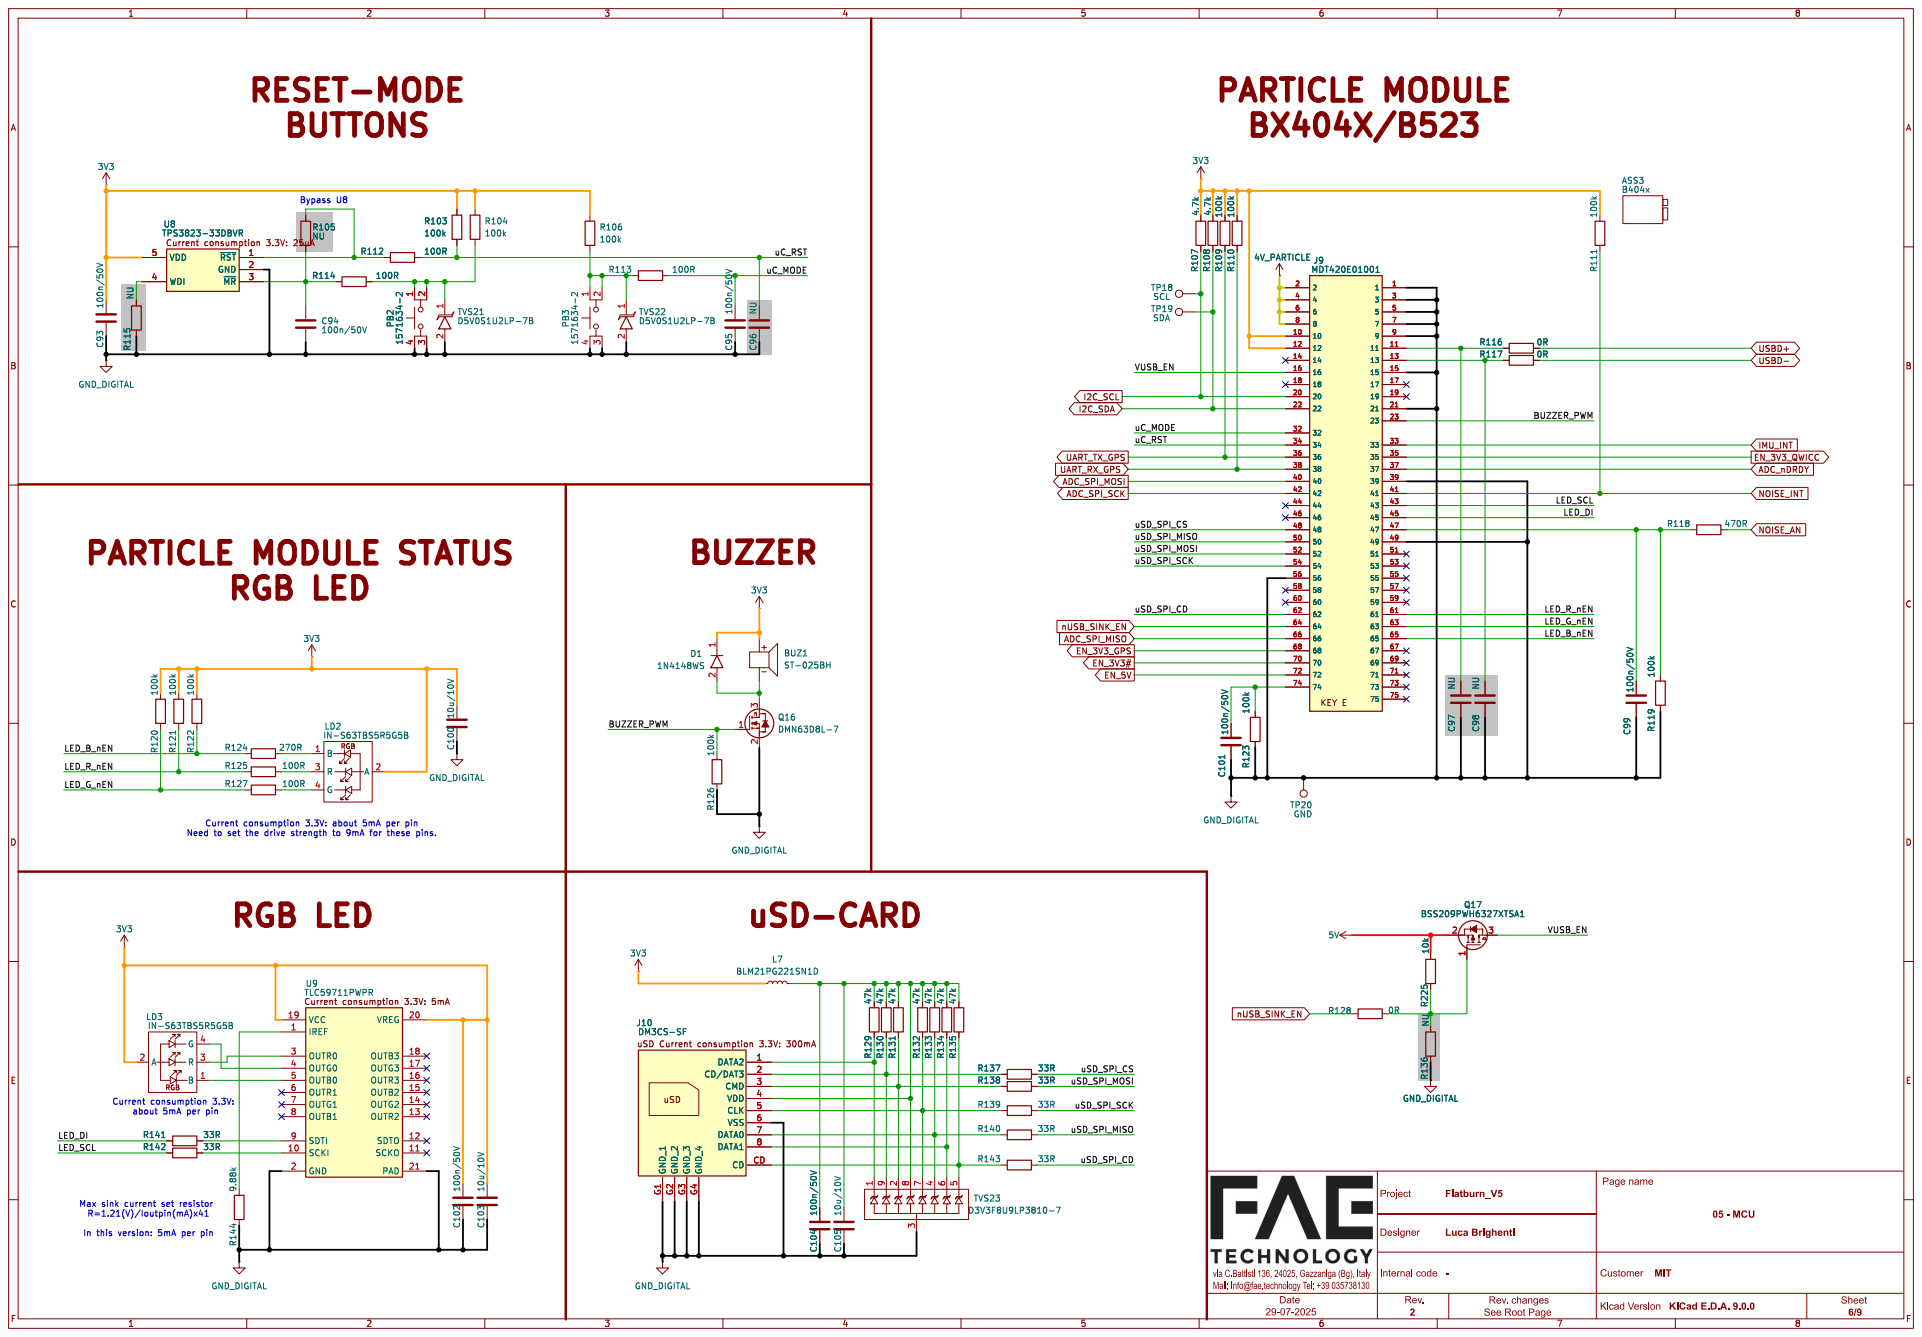
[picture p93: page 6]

Max sink current set resistor R=1.21(V)/Ioutpin(mA)x41

In this version: 5mA per pin

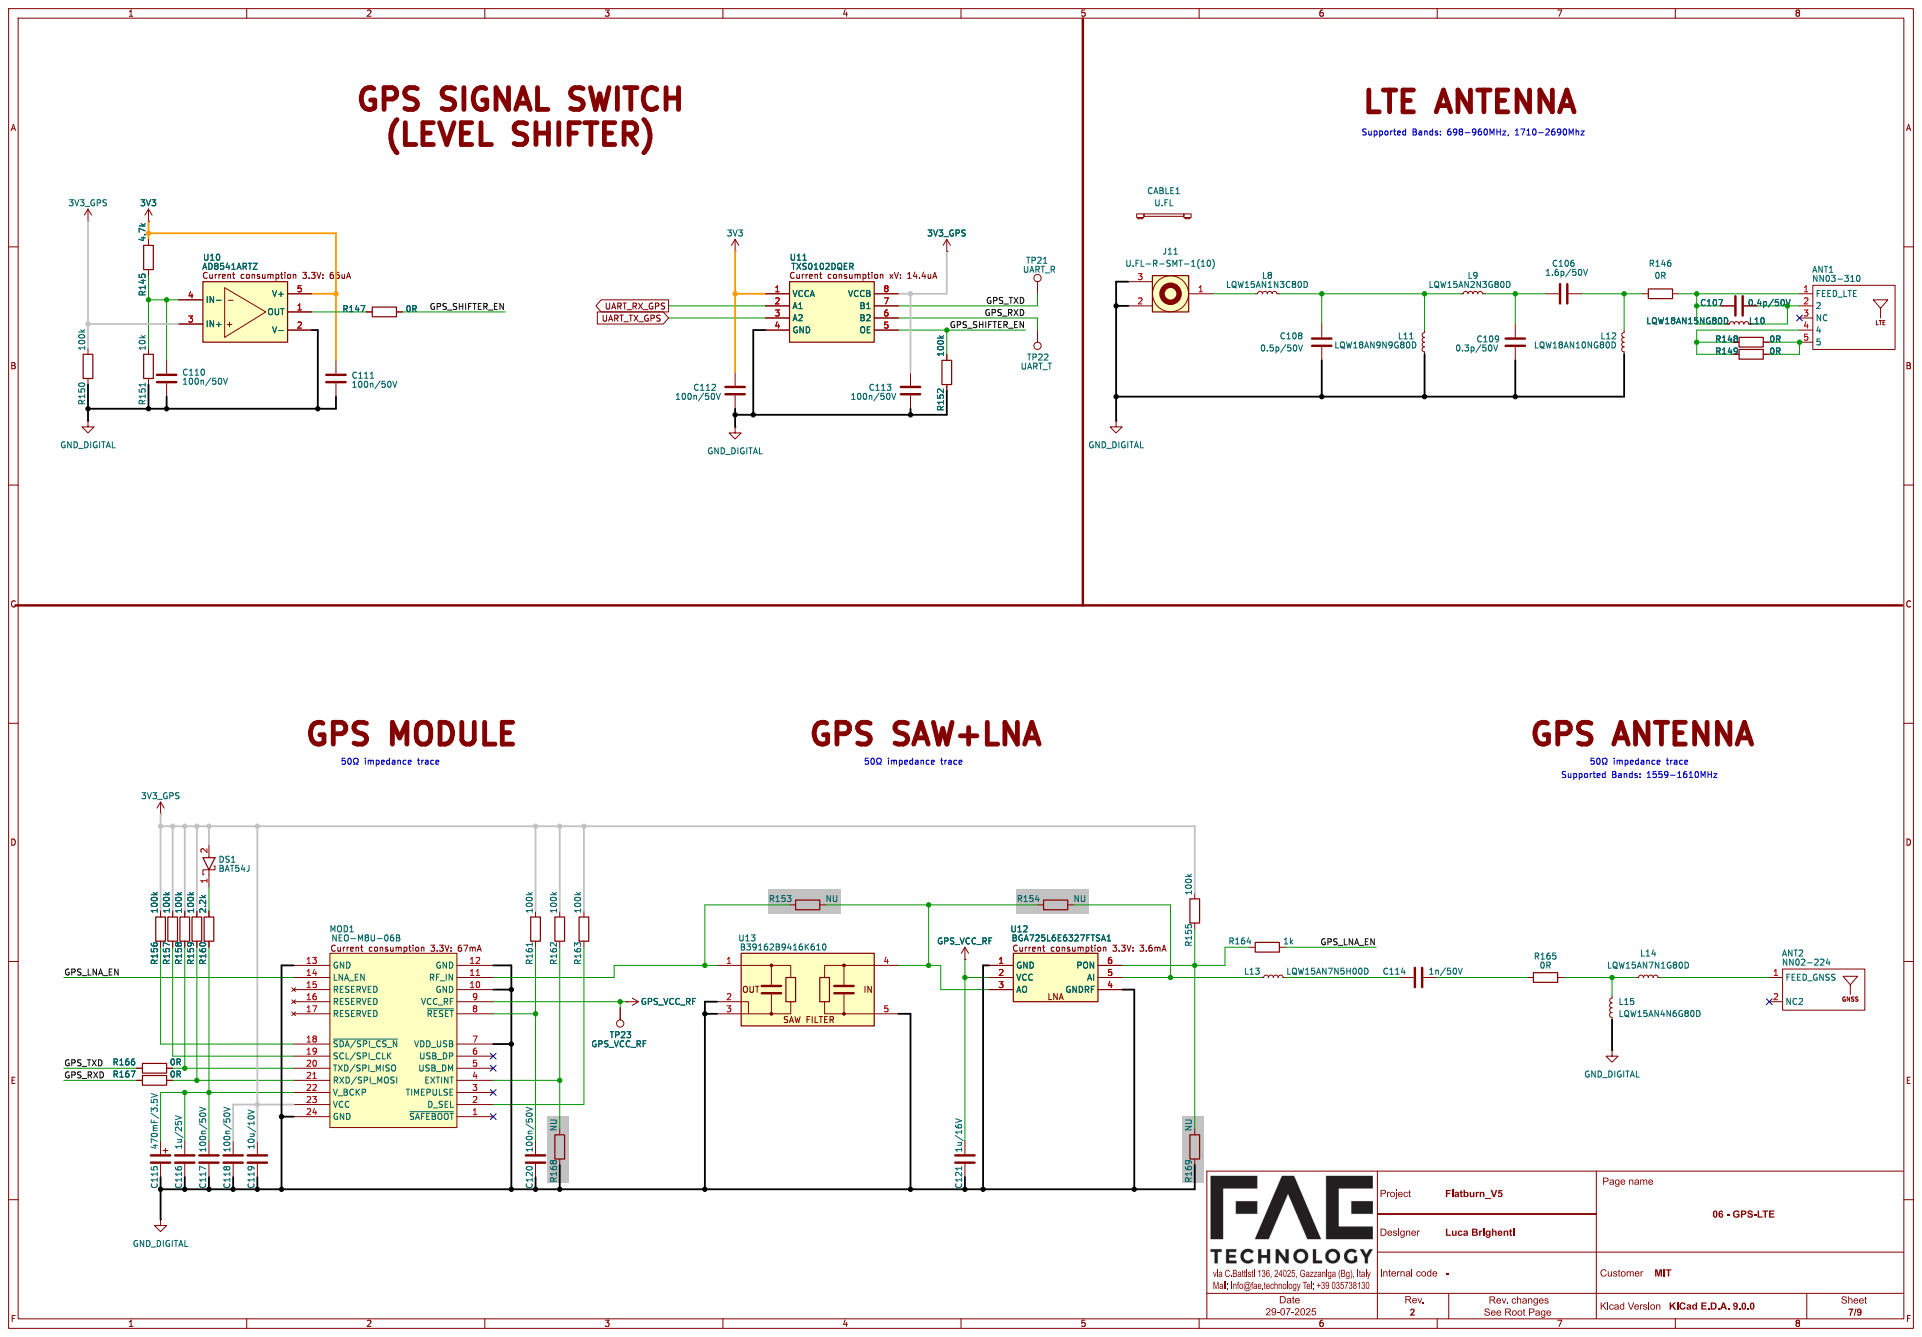
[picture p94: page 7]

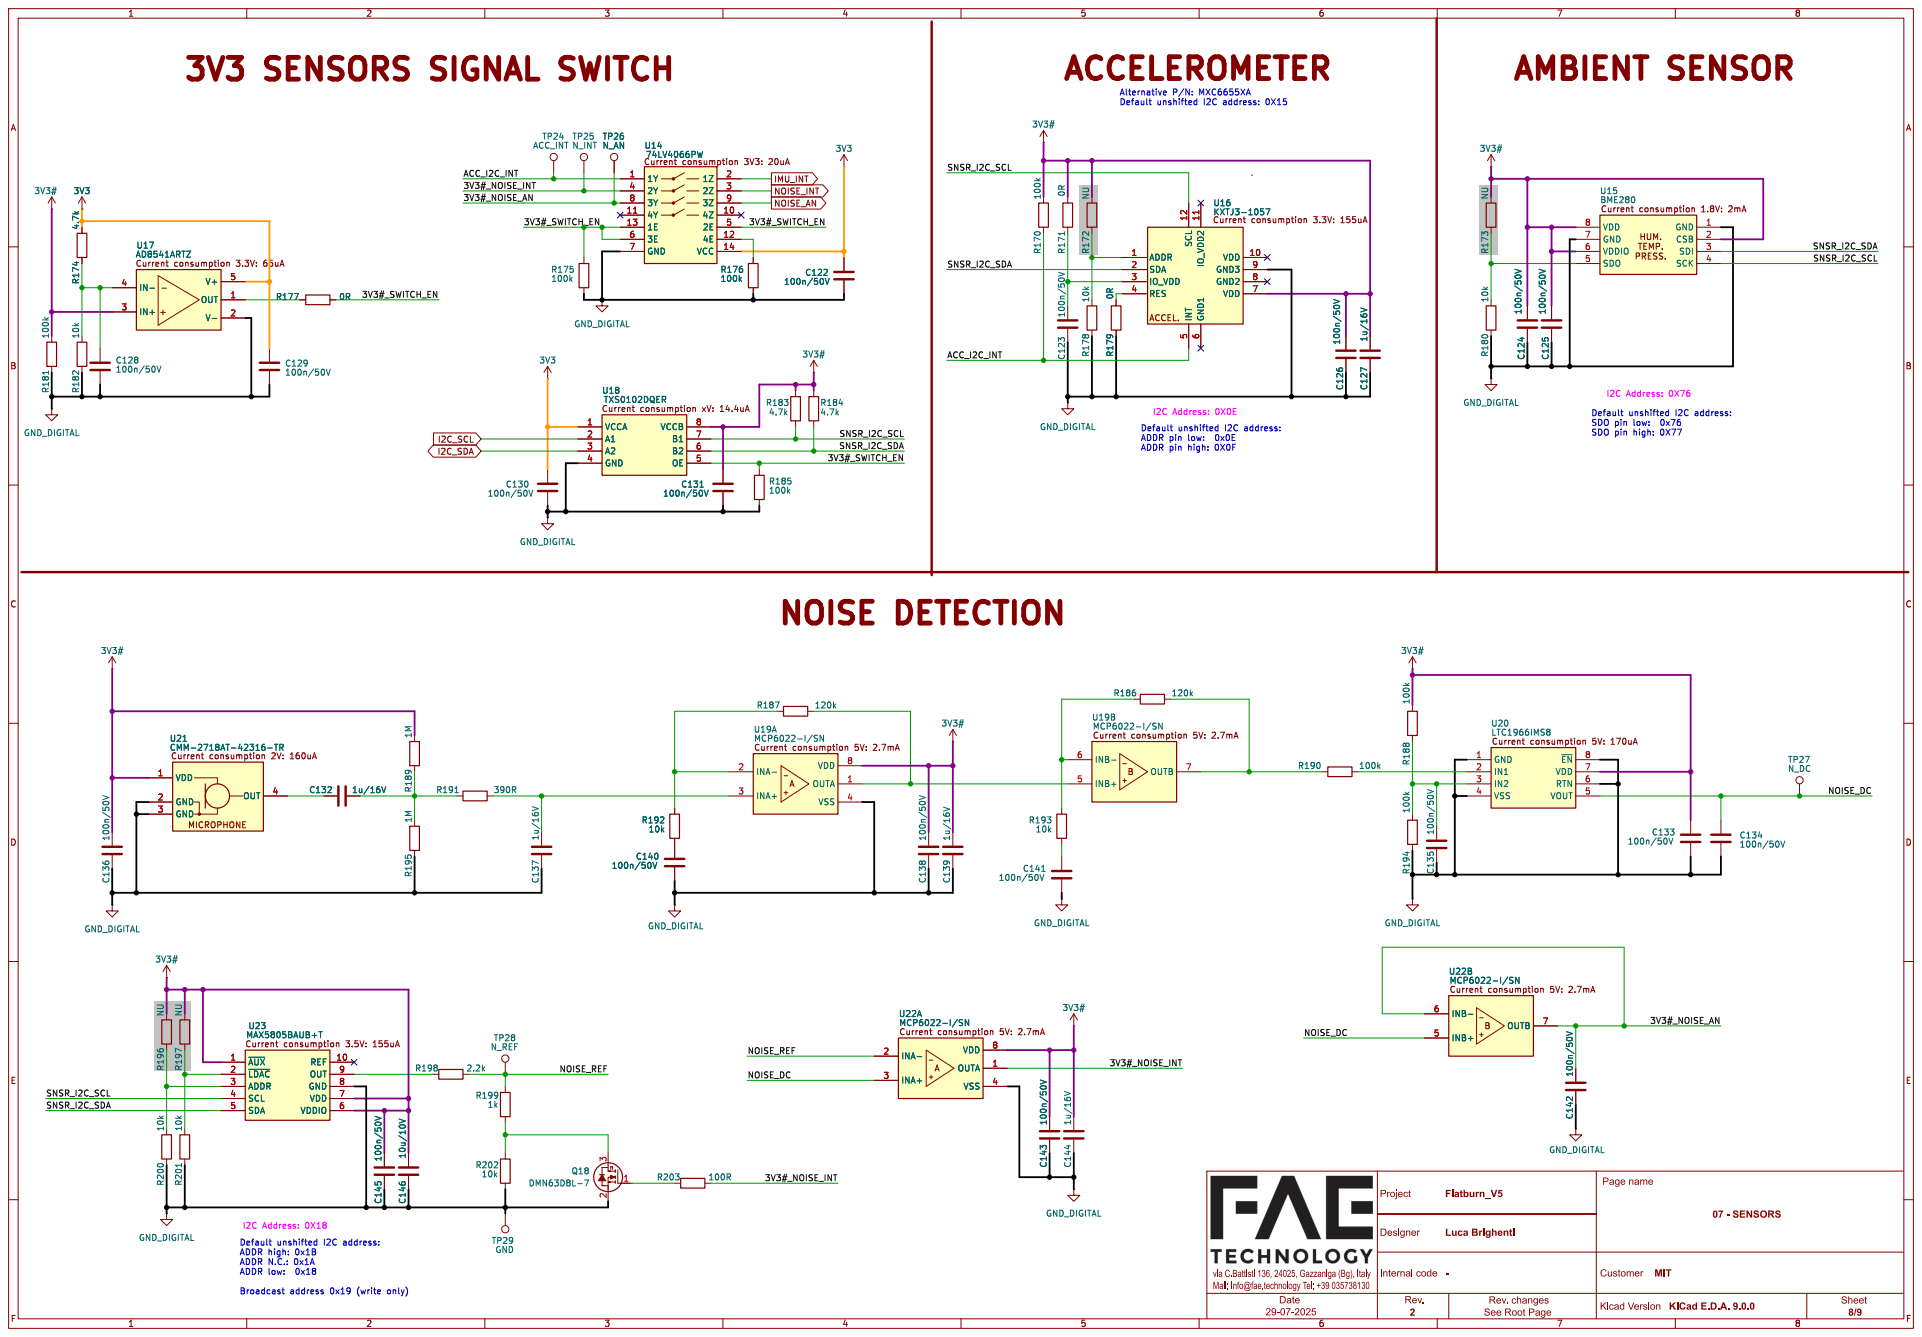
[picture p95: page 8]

I2C Address: 0X0E 3V3 SENSORS SIGNAL SWITCH

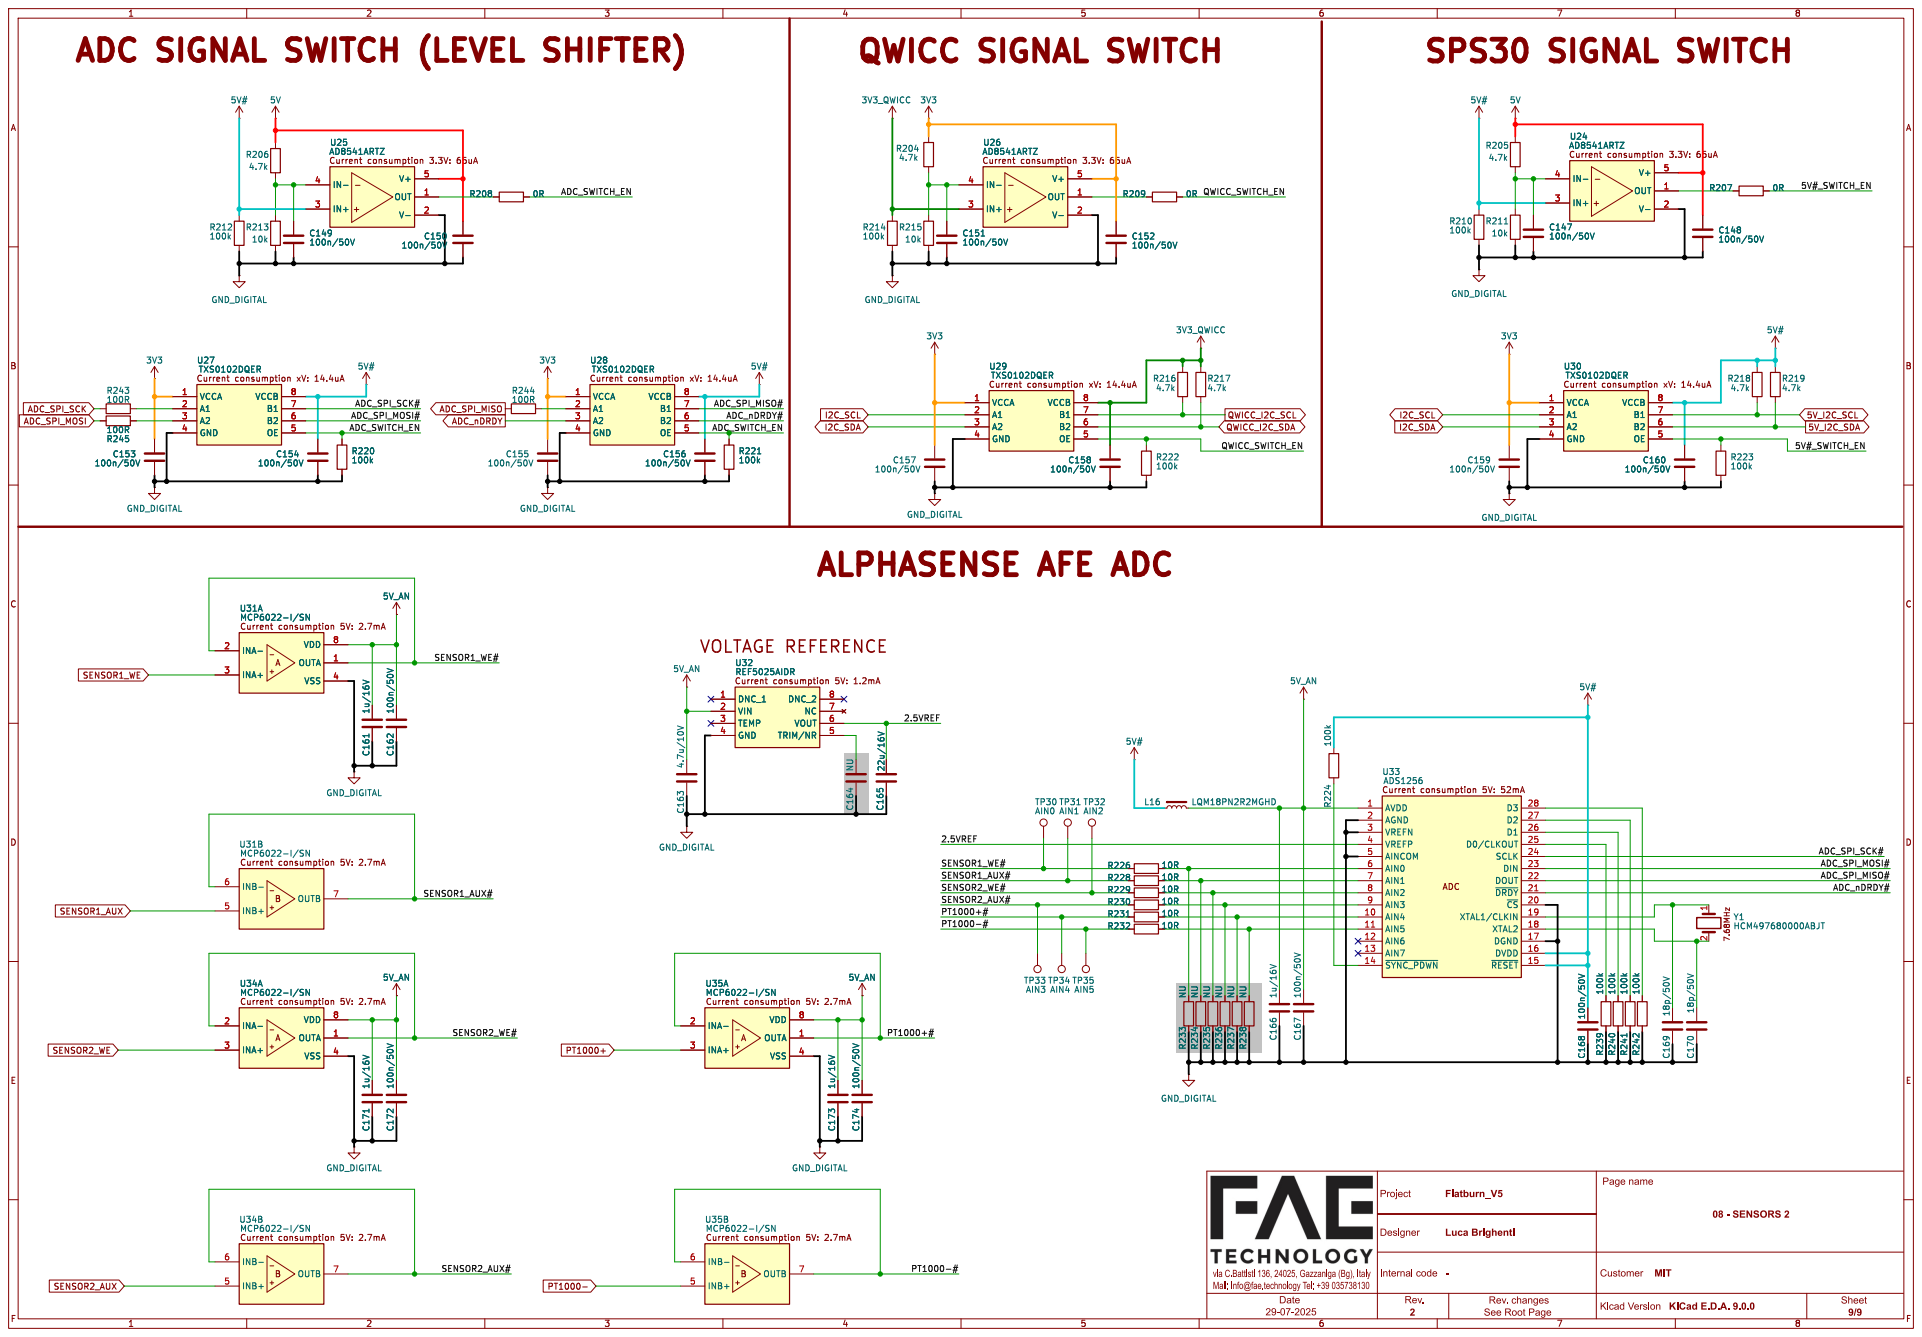
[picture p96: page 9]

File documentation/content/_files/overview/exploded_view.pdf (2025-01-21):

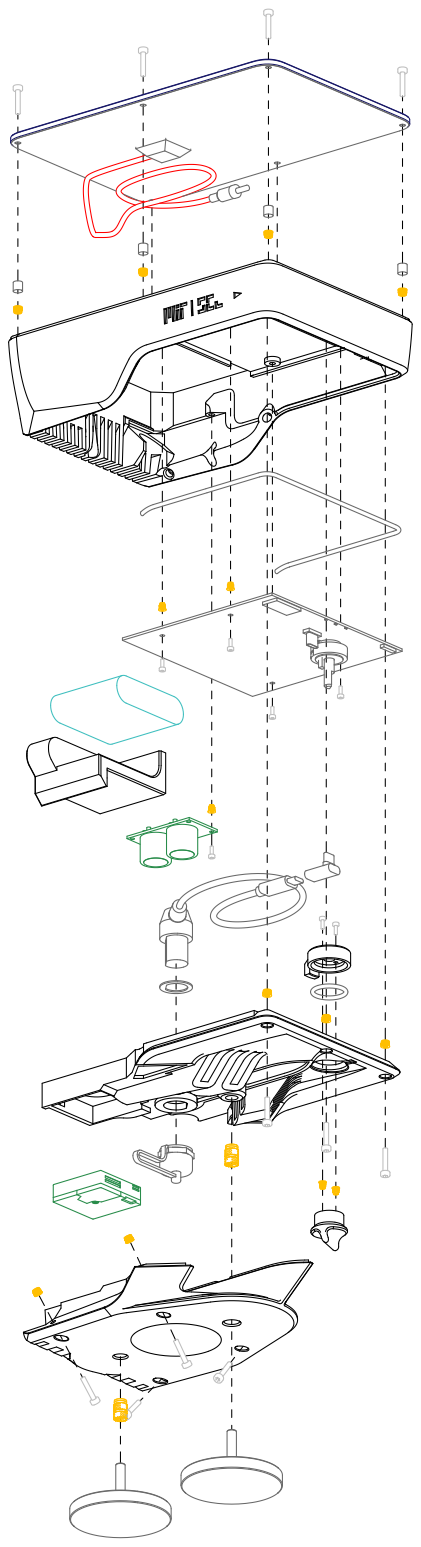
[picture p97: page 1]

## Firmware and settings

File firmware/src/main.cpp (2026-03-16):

#include "Particle.h"

#include "cityscanner_config.h"
#include "cityscanner.h"
#include "CS_core.h"

//PRODUCT_ID(PILOT_CITY); 
//PRODUCT_VERSION(PILOT_CITY_VERSION);


SYSTEM_THREAD(ENABLED);
SYSTEM_MODE(SEMI_AUTOMATIC);

STARTUP(
  Cityscanner::startup();
)

void myWatchdogHandler(void)
{
  Cityscanner::instance().sendWarning("Reset due to watchdog");
  System.reset();
}

SerialLogHandler LogHandler;
ApplicationWatchdog wd(10min, myWatchdogHandler);

void setup() { 
  Serial.begin(9600);
  //Serial1.begin(115200);
  Cityscanner::instance().init();
}

void loop() {
  Cityscanner::instance().loop();
}

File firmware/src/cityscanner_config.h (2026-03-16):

#define MODE PWRSAVE

#define AUTOSLEEP TRUE            //Autosleep when inactive
#define INACTIVITY_TIME 120         //Seconds, triggers light sleep
// Stationary-triggered sleep/hibernate path removed (reset planned)
#define IMU_HEALTH_CHECK_INTERVAL_SEC 3600  // Check IMU health every hour, can be removed for Brazil if IMU is stable
#define IMU_HEALTH_FAIL_ALERT_INTERVAL_SEC (6 * 60 * 60) // Rate-limit IMU alerts
#define DEBUG TRUE
 
#define HW_VERSION V4
#define CELLULAR_ON_STARTUP FALSE    // TRUE or FALSE
#define DTIME 100  
#define BATT_ENABLED TRUE

#define OPC_DATA_VERSION EXTENDED       // BASE or EXTENDED for full BIN data
#define TCP_GHOSTWRITE FALSE         //For testing purpose, doesn't dump data over TCP but prints it over serial
#define SD_FORMAT_ONSTARTUP FALSE   //Erase SD Card on startup

// Data sampling
#define SAMPLE_RATE 5 //Seconds 
#define VITALS_RATE 300 //Seconds
#define ROUTINE_RATE 60 //seconds

// BME280 watchdog
#define BME_FAIL_REINIT_MS (60UL * 1000UL)      // Try re-init every 60s on failure
#define BME_FAIL_RESET_MS (10UL * 60UL * 1000UL) // Reset after 10 minutes of continuous failure

// Data Storage and Broadcasting
#define RECORDS_PER_FILE 200 //standard is 200
#define LOW_BATTERY_THRESHOLD 3.70 //volt
#define LOW_BATTERY_HIBERNATE FALSE // Keep awake for battery/solar soak testing
#define LOW_BATT_ALERT_INTERVAL_SEC (4 * 60 * 60) // 4 hours

#define TCP_ENDPOINT "127.0.0.1" //change the IP address to dump data over TCP (not implemented yet)

// Battery voltage sanity checks
#define BATT_VOLT_STUCK_DELTA 0.01f
#define BATT_VOLT_STUCK_MS (15UL * 60UL * 1000UL)
#define BATT_VOLT_REINIT_COOLDOWN_MS (180UL * 1000UL)

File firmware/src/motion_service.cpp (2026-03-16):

#include "Particle.h"
#include "motion_service.h"
#include "CS_core.h"  //

#define LOW_POWER

float   sampleRate = 6.25;  // HZ - Samples per second - 0.781, 1.563, 3.125, 6.25, 12.5, 25, 50, 100, 200, 400, 800, 1600Hz
uint8_t accelRange = 2;     // Accelerometer range = 2, 4, 8, 16g

int32_t result;

KXTJ3 myIMU(0x0E); // Address 0x0E

MotionService *MotionService::_instance = nullptr;
int MotionService::inactivity_counter = 0;
retained uint32_t imu_irq_total = 0;
volatile uint32_t imu_irq_count = 0;
volatile bool imu_irq_flag = false;
uint32_t imu_irq_last_ms = 0;

namespace {
    const uint32_t IMU_HEALTH_MAGIC = 0x494D5548; // "IMUH"
    const int EEPROM_ADDR_IMU_HEALTH = 96;

    struct ImuHealthAlertRecord {
        uint32_t magic;
        uint16_t batt_mv;
        uint16_t reserved;
        uint32_t epoch;
        uint32_t count;
        uint8_t whoami;
        uint8_t status;
        uint16_t pad;
    };

    bool readImuHealthAlert(ImuHealthAlertRecord &rec) {
        EEPROM.get(EEPROM_ADDR_IMU_HEALTH, rec);
        return (rec.magic == IMU_HEALTH_MAGIC);
    }

    void writeImuHealthAlert(uint16_t batt_mv, uint32_t epoch, uint8_t whoami, uint8_t status) {
        ImuHealthAlertRecord rec = {};
        if (readImuHealthAlert(rec)) {
            rec.count++;
        } else {
            rec.magic = IMU_HEALTH_MAGIC;
            rec.count = 1;
        }
        rec.batt_mv = batt_mv;
        rec.epoch = epoch;
        rec.whoami = whoami;
        rec.status = status;
        EEPROM.put(EEPROM_ADDR_IMU_HEALTH, rec);
    }

    void clearImuHealthAlert() {
        ImuHealthAlertRecord rec = {};
        EEPROM.put(EEPROM_ADDR_IMU_HEALTH, rec);
    }
}


void MotionService::timer_fnc(){
   inactivity_counter++;
   Serial.print("Inactivity counter: ");Serial.println(inactivity_counter);
    pinMode(A1, INPUT); // Accelerometer interrupt
}


Timer inactivity_timer(1000, MotionService::timer_fnc);

MotionService::MotionService() {
}
void scanI2Cwire() { // For debugging purposes
    Serial.println("\n----- I2C Scanner -----");

    if (!Wire.isEnabled()) {
        Serial.println("Wire not enabled! Initializing...");
        Wire.begin();
        Wire.setSpeed(CLOCK_SPEED_100KHZ);
        delay(50);
    }
    uint8_t count = 0;
    for (uint8_t addr = 1; addr < 127; addr++) {
        Wire.beginTransmission(addr);
        if (Wire.endTransmission() == 0) {
            Serial.printlnf("Found device at 0x%02X on wire", addr);
            count++;
        }
    }
    Serial.printlnf("Found %d device(s)\n", count);
}

// Direct register read function
uint8_t readRegisterDirect(uint8_t addr, uint8_t reg) {
    Wire.beginTransmission(addr);
    Wire.write(reg);
    Wire.endTransmission(false);  // Keep connection open
    Wire.requestFrom(addr, (uint8_t)1);
    if (Wire.available()) {
        return Wire.read();
    }
    return 0xFF;
}

// Direct register write function
void writeRegisterDirect(uint8_t addr, uint8_t reg, uint8_t value) {
    Wire.beginTransmission(addr);
    Wire.write(reg);
    Wire.write(value);
    Wire.endTransmission();
}

int MotionService::start()
{   
    uint8_t errorAccumulator = 0;
    if (HW_VERSION == V4)
    {

        bool imu_ok = false; // Adjusted IMU start up
        const int MAX_RETRIES = 10; // Added retries in case of failure, latest tests shows consistent boot on first attempt.
                for (int attempt = 1; attempt <= MAX_RETRIES; attempt++)
        {

            Serial.printlnf("\n--- IMU initialization attempt %d/%d ---", attempt, MAX_RETRIES);

            if (!Wire.isEnabled()) { // I was unsure about wire status for most of the boot process, so added a check and init here to be sure.
                Serial.println("Wire not enabled, reinitializing...");
                Wire.begin();
                Wire.setSpeed(CLOCK_SPEED_100KHZ);
                delay(200);
                
                if (!Wire.isEnabled()) {
                    Serial.println("ERROR: Cannot enable Wire!");
                    continue;  // Skip this attempt
                }
            }
            
            if (myIMU.begin(sampleRate, accelRange) == 0)
            {
                Serial.println("IMU initialized successfully!");
                imu_ok = true;
                break;
            }
            
            Serial.printlnf("IMU init attempt %d failed", attempt);
            
            // Recovery actions between attempts
            if (attempt < MAX_RETRIES)
            {
                Serial.println("Attempting recovery...");
                
                // Reset I2C bus
                Wire.begin();
                Wire.setSpeed(CLOCK_SPEED_100KHZ);
                delay(100);
                
                // Longer delay on later attempts
                if (attempt >= 2)
                {
                    Serial.println("Extended delay before retry...");
                    delay(2000);
                }
            }
         }
        
        if (!imu_ok)
        {
            Serial.println("ERROR: IMU failed to initialize after all attempts!");
            errorAccumulator++;
        }
        else
        {
            // Configure interrupt only if IMU initialized successfully
            myIMU.intConf(50, 1, 10, LOW);

            uint8_t readData = 0;
            myIMU.readRegister(&readData, KXTJ3_WHO_AM_I);
            Serial.print("Who am I? 0x");
            Serial.println(readData, HEX);
                        if (readData == 0x35) {
                Serial.println("IMU identity confirmed: KXTJ3-1057"); // Serial confirmation for debugging
            }
        }
    }
    if(errorAccumulator)
    {
        Serial.println("Problem configuring the device.");
    }
    else
    {
        Serial.println("Device O.K.");
    }
    
    attachInterrupt(INT_ACC, MotionService::resetInactivityCounter, FALLING);
    inactivity_timer.start();   
    Serial.println("timer started");
    motionservice_started = true;
    return true;
}

int MotionService::stop()
{
    inactivity_timer.dispose(); 
    motionservice_started = false;
    return 1;
}

int MotionService::waitOnEvent()
{
    return 1;
    // check accelerometer for events and add it to event queque
    // if no motion events for x minutes go to sleep
}
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

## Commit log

2024-05-10 initial root restructure
    [BronxFallGrid.csv, BronxFallNO2Grid_MedianTrainRstr.csv, BronxFallPMGrid_MedianTrainRstr.csv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]
2024-05-10 documentation structure
    [BronxFallGrid.csv, BronxFallNO2Grid_MedianTrainRstr.csv, BronxFallPMGrid_MedianTrainRstr.csv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]
2024-05-10 config docusaurus
    [BronxFallGrid.csv, BronxFallNO2Grid_MedianTrainRstr.csv, BronxFallPMGrid_MedianTrainRstr.csv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]
2024-05-16 bill of materials, overall structure and visuals
2024-05-16 better tables, added BOM content
2024-05-17 calibration docs content
2024-05-17 device and evolution doc content
2024-05-17 fixed ids on bom
2024-05-18 improved bom and other minor adjusts
2024-05-23 added information to bom on docs
2024-05-23 improved device page docs
2024-05-23 adjusts on bom and tools docs
2024-05-24 adjusts on assembly doc
2024-05-25 fixed assembly order docs
2024-05-25 3d printing table docs
2024-05-30 docs: assembly instructions with photos
2024-06-01 docs: diagrams for device , evolution and platform
2024-06-04 docs: detailed device page
2024-12-17 remove thermal camera from bom
2024-12-17 remove all mentions to thermal camera
2024-12-17 about as landing page
2025-01-09 docs: blind devices, adjusted branding
2025-01-09 docs: device page blind images updated
2025-01-09 docs: evolution page, blind device
2025-01-15 added new physical design files, removed old
    [EB-01 main_board.stp, EH-03 90deg_adapter_usb.stp, EH-04 waterproof_usb.stp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]
2025-01-15 updated b.o.m.
    [MF-05 screw_m3x16.stp, MF-06 screw_m3x16.stp, MF-07 spacer_6mm.stp]
2025-01-15 file cleanup
    [BronxFallGrid.csv, BronxFallNO2Grid_MedianTrainRstr.csv, BronxFallPMGrid_MedianTrainRstr.csv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]
2025-01-15 organize files conten
    [BronxFallGrid.csv, BronxFallNO2Grid_MedianTrainRstr.csv, BronxFallPMGrid_MedianTrainRstr.csv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]
2025-01-15 fixed device page
2025-01-15 added bambu files for printing on x-1 carbon
    [battery_holder.3mf, bottom.3mf, middle.3mf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]
2025-01-16 updated switch and top 3d models
    [MP-04 switch_top.stl, MP-04 switch_top.stp, MP-05 switch_bottom.stl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]
2025-01-20 updated 3d files
    [battery_holder.3mf, bottom.3mf, switch_linear.3mf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]
2025-01-21 updated radial switch with physical stop
    [MP-04 switch_top.stl, MP-04 switch_top.stp, switch_radial_R10307RN02Q.3mf]
2025-01-22 uploaded main board step with LEDs
    [EB-01 main_board.stp]
2025-05-29 KiCad files
    [Flatburn_V4.kicad_sch, block_diagram.kicad_sch, connectors.kicad_sch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]
2025-06-09 Update assembly.md
    update photo links for steps 1-7, removed step 1 (remove printed supports)
2025-06-12 Update assembly.md
    updated photos links, renumber steps
2025-06-12 Update assembly.md
    updated blurred image links
2025-06-17 Update assembly.md
    update photos with gas
2026-01-21 Updated DeviceOS
2026-01-21 Update README for Particle deviceOS compatibility
2026-01-21 ADC Lib
2026-01-21 Pin maping for core
2026-01-21 Battery status
2026-03-16 Revise data retrieval process for Flatburn device
    Updated the data retrieval instructions for the Flatburn device, replacing the Python script with a web-based downloader tool and modifying steps accordingly.
2026-03-17 Add note on device initialization wait time
    Added a note about the initialization wait time after connecting.
2026-03-19 Update link for MP_02 middle STL file
2026-03-19 Update link for MP_03 bottom STL file
2026-03-19 Update link for switch_top STL file
2026-03-19 Fix image references for switch_bottom and battery_cover
2026-03-19 Delete 3D printed parts section from mechanics.md
    Removed section on 3D printed parts and corresponding image.
2026-03-19 Remove duplicate import of CameraMount
    Removed duplicate import statement for CameraMount.
